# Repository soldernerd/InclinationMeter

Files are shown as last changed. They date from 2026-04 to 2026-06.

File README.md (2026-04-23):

# Inclination Meter

A battery-powered, Bluetooth-enabled precision electronic level instrument for machine tool geometry inspection and granite surface plate qualification.

## Overview

The instrument combines a MEMS 3-axis inclinometer (Murata SCL3300) with a high-resolution pendulum-based capacitive sensor (Sciosense PCAP04), a 2.7" Sharp Memory LCD display, and a Bluetooth Low Energy interface to a companion Windows application. All precision sensing is mechanically coupled directly to a cast iron reference base, isolated from the plastic enclosure.

## Hardware

| Parameter | Value |
|---|---|
| MCU | STM32G0B1RET6 (Cortex-M0+, 64 MHz, 512 KB flash) |
| Display | Sharp LS027B7DH01, 2.7", 400x240 monochrome |
| Connectivity | Bluetooth LE 5.0 (Microchip RN4871) |
| USB | USB-C Full Speed - charging + HID + DFU bootloader |
| Battery | 1S LiPo 1000 mAh, ~20 h runtime |
| Supply | 3.3 V main rail, 5 V display rail |
| MEMS range | +/-90 deg |
| Pendulum range | +/-1 mm/m |
| Pendulum resolution | ~0.001 um/m |

### Physical Architecture

Three PCBs:
- **Main board** - MCU, power management, display, BLE, user interface
- **SCL3300 daughter board** - 3-axis MEMS inclinometer, mounted to cast iron base
- **PCAP04 daughter boards x2** - capacitive pendulum readout, one per axis

## Repository Structure

```
KiCad/          KiCad 10 schematic and PCB files
docs/           KiCad file format and schematic reference notes
spec.md         Full hardware design specification
Netlist.md      Schematic netlist / connection list
```

## KiCad Library

All symbols and footprints use [sldrnrd_kicad_lib](https://github.com/soldernerd/sldrnrd_kicad_lib). Clone it as a sibling of this repository:

```
EmbeddedSystems/
├── InclinationMeter/   ← this repo
└── sldrnrd_kicad_lib/  ← library repo
```

## Firmware

Developed with STM32CubeIDE. Firmware update via USB DFU bootloader (no external programmer required after initial flash).

## Status

Hardware design in progress - schematic phase.

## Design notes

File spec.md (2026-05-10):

# Precision Electronic Level Instrument — Hardware Design Specification

**Document version:** 0.3  
**Status:** Draft  
**Date:** May 2026  
**Schematic reference:** KiCad commit 03fac10 (finalized)

---

## 1. System Overview

A battery-powered, Bluetooth-enabled precision electronic level instrument for machine tool geometry inspection and granite surface plate qualification. The system combines a MEMS 3-axis inclinometer with a high-resolution pendulum-based capacitive precision sensor, a wireless interface to a companion Windows desktop application, and a local display for standalone use.

### 1.1 Physical Architecture

The instrument consists of three PCBs:

| Board | Description | Mounting |
|---|---|---|
| Main PCB | Microcontroller, power, display, connectivity, user interface | 3D printed plastic enclosure |
| SCL3300 daughter board | 3-axis MEMS inclinometer | Cast iron precision base via brass standoffs |
| PCAP04 daughter board ×2 | Capacitive pendulum readout (one per axis) | Cast iron precision base via brass standoffs |

The cast iron base (~150×40mm) provides the precision reference surface. The plastic enclosure mounts on top. All precision sensing is mechanically coupled directly to the cast iron, isolated from the plastic enclosure.

### 1.2 Key Specifications

| Parameter | Value |
|---|---|
| Measurement range (MEMS) | ±90° |
| Measurement range (pendulum) | ±1 mm/m |
| Pendulum resolution | ~0.001 µm/m (electronics limited) |
| Pendulum precision (workshop) | ~0.1 µm/m |
| Display | 2.7" Sharp Memory LCD, 400×240 monochrome |
| Connectivity | Bluetooth Low Energy (BLE 5.0) |
| USB | USB-C, Full Speed (charging + HID + MSD bootloader) |
| Battery | 1S LiPo, 1000 mAh |
| Battery life | ~20 hours at 30 mA average |
| Supply voltage | 3.3V (main rail), 3.3V (sensor rail), 5V (buzzer only) |

---

## 2. Power Supply

### 2.1 Architecture

```
1S LiPo 1000mAh (JST-PH 2.0mm)
    │
    ├── Reverse polarity protection (Q1 DMG2305UX P-MOSFET)
    │
    ├── U1 TP4056 (USB-C charging, CC/CV, 500mA charge current)
    │       └── Q2 FS8205A (cell protection FET)
    │
    ├── U2 LP5907MFX-3.3 LDO → 3V3 rail (MCU, RN4871, display logic, EEPROM, buzzer buffer)
    │       └── Enable pin controlled by STM32 PB9 (3V3_EN, active-high)
    │
    ├── U4 LP5907MFX-3.3 LDO → 3V3_Sensors rail (SCL3300, PCAP04 #1, PCAP04 #2)
    │       └── Enable controlled by LDO_EN (power-sheet sequencing logic)
    │
    └── U5 SD6210A boost converter → 5V0 rail (buzzer BZ1 only, via U8 74AHCT244)
            └── Enable controlled by STM32 PB8 (5V_EN, active-high)
```

### 2.2 Component Details

| Ref | Function | Part | Package | JLCPCB # | Notes |
|---|---|---|---|---|---|
| J2 | USB-C + battery charge input | USB-C receptacle | SMD | C165948 | CC1/CC2: 5.1 kΩ to GND |
| Q1 | Reverse polarity | DMG2305UX | SOT-23 | C144153 | P-channel MOSFET |
| U1 | LiPo charger | TP4056 | SOP-8 | C382139 | RPROG = 2 kΩ (R3 ‖ R5) → ~500 mA |
| Q2 | Cell protection FET | FS8205A | TSSOP-8 | C14212 | Dual N-channel |
| U2 | 3V3 LDO — main rail | LP5907MFX-3.3/NOPB | SOT-23-5 | C80670 | 250 mA; EN = PB9 |
| U4 | 3V3_Sensors LDO — sensor rail | LP5907MFX-3.3/NOPB | SOT-23-5 | C80670 | 250 mA; EN = LDO_EN (power-sheet logic) |
| U5 | 5 V boost converter | SD6210A | SOT-23-6 | C250809 | 2.8–5 V in, 5 V/250 mA out; EN = PB8 |
| Q3 | Charging control | AO3400A | SOT-23 | C20917 | N-ch MOSFET; controls TP4056 charge enable path |
| Q4 | Sense-divider isolation | AO3400A | SOT-23 | C20917 | N-ch MOSFET; disconnects BATTERY_SENSE divider lower leg in off-state to prevent battery drain |
| D1–D4 | Schottky diodes | BAT54WS | SOD-323 | — | Present in schematic; verify placement in power sheet |

### 2.3 Battery Cutoff

- Hardware cutoff: DW01A at ~3.0V (cell protection absolute minimum)
- Software cutoff: STM32 ADC monitors Vbat via resistor divider, disables LDO enable pin at 3.6V
- Usable capacity at 3.6V cutoff: ~70% of rated capacity (~700mAh)
- Runtime at 30mA average: ~23 hours

### 2.4 Vbat Measurement

Resistor divider on BAT+ → BATTERY_SENSE → PB14 (ADC_IN):

- R9 = 100 kΩ (high side, BAT+ to divider node)
- R6 = 33 kΩ (low side, divider node to Q4 drain → GND)
- Q4 (AO3400A, N-ch) in the lower leg disconnects the divider during off-state to prevent battery drain
- Scale factor: 33/(100+33) = 0.248 → 4.2 V × 0.248 = 1.04 V max ADC input (within 3.3 V ADC range)
- Software ADC reference: VREF+ = 3.3 V

### 2.5 USB-C Connector

USB-C with CC1/CC2 pulled to GND via 5.1kΩ resistors for 5V/500mA negotiation. USB data lines connect to STM32 USB peripheral.

### 2.6 Decoupling

Every power pin of every IC must have a 100nF ceramic capacitor placed as close as possible to the pin. Additional bulk capacitors (10µF) at LDO output and charge pump output.

---

## 3. Microcontroller

### 3.1 Device

**STM32G0B1RET6**
- Package: LQFP64-GP (10×10 mm, 0.5 mm pitch — same body as PIC32MX470 64-TQFP)
- Core: ARM Cortex-M0+, 64 MHz
- Flash: 512 KB
- RAM: 144 KB (without parity)
- Supply: 1.7–3.6V
- JLCPCB: C2829307

### 3.2 Clock

- Main crystal: 8 MHz, ±20 ppm, SMD 5032 package (Yangxing X50328MSB2GI, JLCPCB C115962)
- Main crystal load caps: 33 pF NP0 (0603). Crystal CL = 20 pF, C_stray ≈ 3 pF → C_load = 2×(20−3) = 34 pF → 33 pF (nearest E12)
- Main crystal pins: PF0-OSC_IN (pin 10), PF1-OSC_OUT (pin 11)
- PLL configuration: HSE 8 MHz → SYSCLK = 64 MHz
- USB clock: HSI48 internal RC + CRS locked to USB SOF packets → 48 MHz (no crystal required for USB)
- **RTC crystal (Y1):** 32.768 kHz, standard RTC crystal, on PC14 (OSC32_IN, pin 4) and PC15 (OSC32_OUT, pin 5)
  > **Note:** PC14/PC15 are also used for PCAP04 #2 SCL/SDA and the ~{RST} signal respectively. See open items.

### 3.3 Debug / Programming Interface

**J4 — 2×7, 50 mil (1.27 mm) pitch SMD header**, compatible with STLINK-V3MINIE.

| J4 Position | Signal | Net | Notes |
|---|---|---|---|
| 1 | VCC | 3V3 | Target voltage sense for STLINK |
| 2 | SWDIO | SWDIO | SWD data — see note below |
| 3 | GND | GND | |
| 4 | SWCLK | SWCLK | SWD clock — see note below |
| 5 | GND | GND | |
| 6 | SWO | SWO | Cortex-M0+ has no ITM; SWO not functional |
| 7 | NC | — | |
| 8 | ~{RST} | ~{RST} | Reset signal → PC15 |
| 9 | GND | GND | |
| 10 | DEBUG_UART_MCU_TO_PC | — | PD9 (UART TX from MCU) |
| 11 | DEBUG_UART_PC_TO_MCU | — | PD8 (UART RX to MCU) |
| 12–14 | GND / NC | — | |

> **SWD pin note:** Standard SWD pins on STM32G0B1 are PA13 (SWDIO) and PA14 (SWCLK). In this design, PA13/PA14 are used for PCAP04 #1 P3/P2 GPIO. The `SWDIO` and `SWCLK` nets on J4 appear connected to PA8/PB15 in the schematic. This is a known conflict requiring clarification: either PA13/PA14 must be routed to J4 for SWD to function, or SWD and PCAP04_1 P2/P3 cannot be used simultaneously. See Netlist.md open items.

### 3.4 Reset

NRST (pin 12) has a decoupling capacitor to GND. The `~{RST}` signal from J4 routes to PC15 — see Netlist.md open item 2.

### 3.5 BOOT0 / DFU Bootloader

PA14 doubles as BOOT0 on STM32G0B1. A pull-down resistor holds BOOT0 LOW for normal boot. To activate the ROM DFU bootloader, pull BOOT0 HIGH before reset — the device enumerates as a USB DFU device. No SPI flash required.

---

## 4. Peripheral Pin Allocation

### 4.1 Summary Table

All assignments verified from KiCad/mcu.kicad_sch global label coordinates. See Netlist.md §5 for full analysis and footnotes.

| Function | Signal | Direction | STM32 Pin (phys.) | Net name |
|---|---|---|---|---|
| **Power control** | | | | |
| 3.3 V main LDO enable | 3V3_EN | Out | PB9 (63) | 3V3_EN |
| 5 V boost enable | 5V_EN | Out | PB8 (62) | 5V_EN |
| Charge enable (active-low) | ~{CHARGE_EN} | Out | PB7 (61) | ~{CHARGE_EN} |
| Battery voltage sense | BATTERY_SENSE | ADC in | PB14 (34) | BATTERY_SENSE |
| Charge status sense | CHARGE_SENSE | In | PC4 (25) | CHARGE_SENSE |
| Standby sense | STANDBY_SENSE | In | PC5 (26) | STANDBY_SENSE |
| USB VBUS sense | VBUS_SENSE | In | PC7 (39) | VBUS_SENSE |
| **SPI — SCL3300 inclinometer** | | | | |
| SCK | SCL3300_SCK | SPI out | PB5 (59) | SCL3300_SCK |
| MOSI | SCL3300_MOSI | SPI out | PB3 (57) | SCL3300_MOSI |
| MISO | SCL3300_MISO | SPI in | PB4 (58) | SCL3300_MISO |
| CS (active-low) | SCL3300_CS | Out | PB6 (60) | SCL3300_CS |
| **I2C — PCAP04 #1** | | | | |
| SCL | PCAP04_1_SCL | I2C out | PC8 (48) | PCAP04_1_SCL |
| SDA | PCAP04_1_SDA | I2C bidir | PA15 (47) | PCAP04_1_SDA |
| Interrupt | PCAP04_1_INT | In | PA12 (44) | PCAP04_1_INT |
| GPIO P2 (optional) | PCAP04_1_P2 | Bidir | PA14 (46) | PCAP04_1_P2 |
| GPIO P3 (optional) | PCAP04_1_P3 | Bidir | PA13 (45) | PCAP04_1_P3 |
| **I2C — PCAP04 #2** | | | | |
| SCL | PCAP04_2_SCL | I2C out | PC14 (4) | PCAP04_2_SCL |
| SDA | PCAP04_2_SDA | I2C bidir | PC13 (3) | PCAP04_2_SDA |
| Interrupt | PCAP04_2_INT | In | PC10 (64) | PCAP04_2_INT |
| GPIO P2 (optional) | PCAP04_2_P2 | Bidir | PC11 (1) | PCAP04_2_P2 |
| GPIO P3 (optional) | PCAP04_2_P3 | Bidir | PC12 (2) | PCAP04_2_P3 |
| **I2C — EEPROM (U10)** | | | | |
| SCL | EEPROM_SCL | I2C out | PA4 (21) | EEPROM_SCL |
| SDA | EEPROM_SDA | I2C bidir | PA3 (20) | EEPROM_SDA |
| **SPI — Display (LS027B7DH01)** | | | | |
| SCK | DISP_SCK | SPI out | PB10 (30) | DISP_SCK |
| MOSI (SI) | DISP_MOSI | SPI out | PB0 (27) | DISP_MOSI |
| CS (SCS, active-high) | DISP_CS | Out | PB11 (31) | DISP_CS |
| VCOM toggle | DISP_VCOM | Out | PB1 (28) | DISP_VCOM |
| Display on/off | DISP_ON | Out | PB2 (29) | DISP_ON |
| **USART2 — RN4871 BLE** | | | | |
| TX (MCU→BLE) | BLE_UART_MCU_TO_BLE | Out | PD6 (56) | BLE_UART_MCU_TO_BLE |
| RX (BLE→MCU) | BLE_UART_BLE_TO_MCU | In | PD5 (55) | BLE_UART_BLE_TO_MCU |
| Reset (active-low) | ~{BLE_RST} | Out | PD4 (54) | ~{BLE_RST} |
| GPIO P0_2 (optional) | BLE_P0_2 | Bidir | PD2 (52) | BLE_P0_2 |
| GPIO P1_6 (optional) | BLE_P1_6 | Bidir | PD3 (53) | BLE_P1_6 |
| GPIO P1_7 (optional) | BLE_P1_7 | Bidir | PD0 (50) | BLE_P1_7 |
| GPIO P2_0 (optional) | BLE_P2_0 | Bidir | PC9 (49) | BLE_P2_0 |
| GPIO P3_6 (optional) | BLE_P3_6 | Bidir | PD1 (51) | BLE_P3_6 |
| **Debug UART (J4)** | | | | |
| TX (MCU→PC) | DEBUG_UART_MCU_TO_PC | Out | PD9 (41) | DEBUG_UART_MCU_TO_PC |
| RX (PC→MCU) | DEBUG_UART_PC_TO_MCU | In | PD8 (40) | DEBUG_UART_PC_TO_MCU |
| **USB FS** | | | | |
| D+ | USB_D+ | Bidir | PA9 (37) | USB_D+ |
| D− | USB_D- | Bidir | PC6 (38) | USB_D- |
| **Rotary encoder 1** | | | | |
| Channel A | ENC_1A | In | PA1 (18) | ENC_1A |
| Channel B | ENC_1B | In | PA2 (19) | ENC_1B |
| Push-button (active-low) | ~{ENC_1SW} | In | PA0 (17) | ~{ENC_1SW} |
| **Rotary encoder 2** | | | | |
| Channel A | ENC_2A | In | PC2 (15) | ENC_2A |
| Channel B | ENC_2B | In | PC3 (16) | ENC_2B |
| Push-button | ENC_2SW | In | PC1 (14) | ENC_2SW |
| **Temperature sensor** | | | | |
| Analog output | TEMP_SENSE | ADC in | PB13 (33) | TEMP_SENSE |
| **Buzzer** | | | | |
| Drive signal (3.3 V logic) | BUZZER | PWM out | PB12 (32) | BUZZER |
| **Status LEDs** | | | | |
| Power LED | LED_PWR | Out | PA6 (23) | LED_PWR |
| Status LED | LED_STATUS | Out | PA5 (22) | LED_STATUS |
| **SWD / debug** | | | | |
| SWO | SWO | Out | PA7 (24) | SWO |
| SWDIO | SWDIO | Bidir | PA8 (36)* | SWDIO |
| SWCLK | SWCLK | In | PB15 (35)* | SWCLK |
| Reset sense | ~{RST} | In | PC15 (5)* | ~{RST} |
| **Misc** | | | | |
| External reset (NRST) | — | — | pin 12 | hardware only |

*See §3.3 note regarding SWD pin conflict with PCAP04 and ~{RST} on PC15.

### 4.2 Peripheral Allocation

| Peripheral | Assignment | Pins |
|---|---|---|
| SPI (TBD) | SCL3300 inclinometer | PB3/PB4/PB5/PB6 |
| SPI (TBD) | Display LS027B7DH01 | PB0/PB10/PB11 (bit-bang or AF, verify) |
| I2C (TBD) | PCAP04 #1 | PC8/PA15 |
| I2C (TBD) | PCAP04 #2 | PC14/PC13 |
| I2C (TBD) | EEPROM (U10) | PA4/PA3 — dedicated bus |
| USART2 | RN4871 BLE module, 115200 baud | PD5/PD6 |
| USART (TBD) | Debug UART to J4 | PD8/PD9 |
| USB FS | USB-C (charging + HID + DFU); HSI48 + CRS | PA9/PC6 |
| ADC | BATTERY_SENSE, TEMP_SENSE | PB14, PB13 |
| Timer (PWM) | BUZZER (3.3 V drive to U8) | PB12 |
| Timer (PWM) | DISP_VCOM toggle (≥ 1 Hz) | PB1 |

> All SPI and I2C peripheral assignments require verification against the STM32G0B1RET6 alternate function table.  
> PCAP04 P2/P3 GPIO lines and RN4871 GPIO lines will be assigned to specific functions during firmware development.

---

## 5. Display

### 5.1 Device

**Sharp LS027B7DH01**
- Size: 2.7", 400×240 pixels, monochrome
- Technology: Memory-in-Pixel reflective LCD (no backlight)
- Interface: SPI write-only
- Supply: VDD = VDDA = 5V
- Logic inputs: 3V compatible (level shifted from 3.3V)
- FPC connector: 10-pin, 0.5mm pitch, integral tail

### 5.2 Power

- VDD and VDDA both connected to 5V rail from SD6210A
- VDD must rise before or simultaneously with VDDA
- 1µF ceramic decoupling on both VDD and VDDA

### 5.3 Signal Connections

| Display Pin | Signal | Connection |
|---|---|---|
| SCLK | SPI clock | 74AHCT244 output → SPI1 SCK |
| SI | SPI data in | 74AHCT244 output → SPI1 MOSI |
| SCS | Chip select | 74AHCT244 output → GPIO (active HIGH) |
| EXTCOMIN | VCOM inversion | 74AHCT244 output → GPIO (timer ISR toggle) |
| EXTMODE | COM mode select | Tied to VDD (5V) — external VCOM mode |
| DISP | Display on/off | 74AHCT244 output → GPIO |
| VDD | Digital supply | 5V rail |
| VDDA | Analog supply | 5V rail |
| VSS | Digital GND | GND |
| VSSA | Analog GND | GND |

### 5.4 Logic Level Shifting

All 5 logic signals (SCLK, SI, SCS, EXTCOMIN, DISP) shifted from 3.3V to 5V via:

**SN74AHCT244DBR** (TI, SSOP-20, JLCPCB C2868870)
- 8-channel unidirectional buffer, 3.3V in, 5V out
- OE1, OE2 tied to GND (always enabled)
- 3 channels spare

### 5.5 PCB Connector

**10-pin, 0.5mm pitch ZIF FPC connector** (bottom contact, SMD)
- Hirose FH12-10S-0.5SH or equivalent
- Position within 30mm of display window in enclosure (limited by FPC tail length)

### 5.6 VCOM Timing

EXTMODE = HIGH selects external VCOM mode. STM32 TIM3_CH1 (PA6 AF1) or a timer ISR toggles DISP_VCOM at 30 Hz (33 ms period). This prevents DC bias buildup in the liquid crystal cells. VCOM must toggle continuously whenever the display is powered.

### 5.7 Framebuffer Note

Full 400×240 monochrome framebuffer = 12,000 bytes. STM32G0B1 has 144 KB RAM — full framebuffer fits comfortably. Render line-by-line for updates; transmit only changed lines to minimise SPI activity.

---

## 6. Bluetooth Low Energy

### 6.1 Device

**RN4871-I/RM128** (Microchip, castellated module)
- BLE 5.0
- UART ASCII command interface
- Pre-certified FCC/CE
- 3.3V supply
- JLCPCB: C633941

### 6.2 Interface

UART at 115200 baud, 8N1

| Signal | STM32 Pin (phys.) | Direction | Notes |
|---|---|---|---|
| UART TX (MCU→BLE) | PD6 (56), USART2_TX | STM32 → RN4871 | 3.3V logic |
| UART RX (BLE→MCU) | PD5 (55), USART2_RX | RN4871 → STM32 | 3.3V logic |
| ~{BLE_RST} | PD4 (54) | STM32 → RN4871 | Active low hardware reset |
| GPIO P0_2–P3_6 | PD2/PD3/PD0/PC9/PD1 | TBD | Optional; usage determined in firmware |

### 6.3 GATT Service

Custom BLE service with two characteristics:

| Characteristic | UUID | Properties | Description |
|---|---|---|---|
| Measurement notify | 128-bit custom | Notify | Device → PC: angle data |
| Command write | 128-bit custom | Write | PC → Device: trigger commands |

Custom 128-bit UUIDs to be defined during firmware development.

### 6.4 Antenna Keep-out

Keep-out zone around RN4871 antenna: no copper, no vias, no traces within the area specified in the module datasheet. Place module at PCB edge where possible.

---

## 7. 3-Axis Inclinometer (SCL3300 Daughter Board)

### 7.1 Device

**Murata SCL3300-D01**
- 3-axis MEMS inclinometer
- Digital SPI interface
- Supply: 3.0–3.6V
- Current: 1.2mA typical
- Measurement modes: 4 selectable (Mode 4 preferred: lowest noise, 10Hz ODR)
- Noise: 0.0009°/√Hz (Mode 4, X/Z axes)
- Factory calibrated, no external calibration required
- Package: 12-pin LCC (SMD, on daughter board)

### 7.2 Daughter Board

Separate small PCB (~30×25mm) with:
- SCL3300 + decoupling capacitors only
- 6-pin FFC connector (same physical standard as PCAP04 boards)
- Mounted to cast iron base via brass M3 standoffs, 4 corners

**Pinout of J3 (6-pin FFC, 1.0 mm pitch, main board side):**

| Pin | Signal | Description |
|---|---|---|
| 1 | 3V3_Sensors | 3.3 V supply (from U4 LDO) |
| 2 | SCL3300_CS | SPI chip select (active-low) |
| 3 | SCL3300_SCK | SPI clock |
| 4 | SCL3300_MISO | SPI data out (SCL3300 → MCU) |
| 5 | SCL3300_MOSI | SPI data in (MCU → SCL3300) |
| 6 | GND | Ground |

Connector: J3 (JUSHUO AFA07 or equivalent 6-pin 1.0 mm FFC ZIF).

### 7.3 Main Board Connection

J3 (SCL3300 FFC) is the only 6-pin FFC on the main board for sensor connections. J5 and J6 are 10-pin FFCs for PCAP04 #1 and #2 respectively.

**SPI timing:** Use SPI Mode 0, recommended clock 2–4 MHz per datasheet for best noise performance.

**Post-assembly calibration:** Perform system-level zero/offset calibration after final mechanical assembly with all standoffs torqued. Wait minimum 12 hours after reflow before calibrating.

---

## 8. Precision Capacitive Inclinometer (PCAP04 Boards)

### 8.1 Device

**Sciosense PCAP04-AQFM-24**
- Capacitance-to-digital converter with integrated DSP
- Input range: 1pF–100nF
- Resolution: up to 8aF at 2.5Hz
- Interface: I2C or SPI (I2C selected)
- Supply: 2.1–3.6V (3.3V nominal)
- Package: QFN-24, 4×4mm

### 8.2 I2C Configuration

Each PCAP04 board has a dedicated I2C bus. I2C (not SPI) is used in this design.

**PCAP04 #1 (J5) — SCL=PC8, SDA=PA15:**
- PCAP04 #1 I2C address: verify from PCAP04 datasheet (address depends on ADDR pin)
- Pull-ups on SCL/SDA to 3V3_Sensors on the daughter board

**PCAP04 #2 (J6) — SCL=PC14, SDA=PC13:**
- PCAP04 #2 I2C address: verify from PCAP04 datasheet
- Pull-ups on SCL/SDA to 3V3_Sensors on the daughter board

**EEPROM (U10) — SCL=PA4, SDA=PA3 (separate dedicated I2C bus)**

> EEPROM is on its own I2C bus, separate from both PCAP04 buses.

### 8.3 PCAP04 Daughter Boards (v2)

The PCAP04 v2 daughter boards are used. They expose both I2C and SPI interfaces but **only I2C is used**. Connector: 10-pin FFC.

**Pinout of J5 / J6 (10-pin FFC, main board side):**

| Pin | Signal | Description |
|---|---|---|
| 1 | 3V3_Sensors | 3.3 V supply |
| 2 | PCAP04_x_SCL | I2C clock |
| 3 | PCAP04_x_SDA | I2C data |
| 4–7 | GND / NC | Ground / no-connect |
| 8 | PCAP04_x_P3 | GPIO P3 (optional, usage TBD) |
| 9 | PCAP04_x_P2 | GPIO P2 (optional, usage TBD) |
| 10 | PCAP04_x_INT | Interrupt output (active-low) |

> **Compatibility note:** These 10-pin FFC connectors are **not compatible** with the old 6-pin FFC prototype boards.  
> New v2 daughter boards are required for use with this main board.

### 8.4 Mechanical Design (Pendulum Sensor)

The PCAP04 measures differential capacitance between two plates (~20mm diameter, 0.1mm gap) flanking a brass pendulum bob suspended from a thin metal foil pivot. Eddy current braking (permanent magnet near brass bob) provides damping. Pendulum length ~40mm to centre of gravity.

**Performance summary:**

| Parameter | Value |
|---|---|
| Capacitance per plate | ~28 pF |
| Sensitivity | ~53 fF/arcsecond |
| Resolution (8aF noise) | ~0.001 µm/m |
| Measurement range | ±1 mm/m |
| Natural frequency | ~2.5 Hz |

---

## 9. Firmware Update (DFU)

The W25Q80DV SPI flash has been removed. Firmware updates are handled by the STM32G0B1 built-in ROM DFU bootloader:

- No external flash required
- DFU activated by pulling BOOT0 (PA14/pin 46) HIGH during reset
- STM32 enumerates as USB DFU device (class 0xFE, subclass 0x01)
- Firmware downloaded via `dfu-util` or STM32CubeProgrammer over the existing USB-C port
- After programming, normal reset (BOOT0 LOW) boots from internal flash

The SPI2 bus is now dedicated to the SCL3300 sensor only (one device, one CS line).

---

## 10. EEPROM

### 10.1 Device

**Microchip 24LC256-I/ST**
- 256Kbit (32KB) EEPROM
- I2C interface
- 3.3V supply
- TSSOP-8 package
- JLCPCB: C87823

### 10.2 Purpose

Non-volatile storage for calibration coefficients, zero offsets, instrument configuration, and measurement history.

### 10.3 Connections

| EEPROM Pin | Connection | Notes |
|---|---|---|
| A0 | GND | I2C address bit 0 = 0 |
| A1 | GND | I2C address bit 1 = 0 |
| A2 | GND | I2C address bit 2 = 0 → address 0x50 |
| VSS | GND | |
| SDA | I2C SDA | Shared bus |
| SCL | I2C SCL | Shared bus |
| WP | GND | Write always enabled |
| VCC | 3.3V | 100nF decoupling |

---

## 11. Temperature Sensor

### 11.1 Device

**Texas Instruments LM35**
- Linear temperature sensor, 10mV/°C
- No calibration required
- Supply: 3.3V
- SOT-23 package
- JLCPCB: C9900081740

### 11.2 Purpose

Ambient temperature measurement for pendulum thermal drift compensation and data logging.

### 11.3 Placement

Mount on main PCB, away from heat sources (LP5907 LDO, TP4056, SD6210A charge pump). Placement near centre of board, not near USB-C connector or power section.

### 11.4 Connection

Output pin → STM32 PB1 (pin 28, ADC_IN9) via 100 Ω series resistor and 10 nF cap to GND (low-pass filter).

---

## 12. Buzzer

### 12.1 Device

**Same Sky (CUI) CPT-9019A-SMT-TR**
- SMD passive piezo transducer
- Resonant frequency: 4000 Hz
- Rated voltage: 3 Vp-p
- Capacitance: 12 nF (capacitive load — no driver transistor required)
- SPL: 75 dB typical / 72 dB minimum at 10 cm at 3 Vp-p
- Package: 9×9×1.9 mm SMD
- Operating temperature: −20 to +70 °C
- JLCPCB: C20181991

### 12.2 Drive

BZ1 is driven at **5 V** via the 74AHCT244 buffer (U8):

1. MCU PB12 (pin 32) outputs 3.3 V PWM signal (`BUZZER` net)
2. U8 (74AHCT244) level-shifts 3.3 V → 5 V (`BUZZER_5V` net)
3. 5 V signal drives BZ1

PWM frequency: buzzer resonant frequency (typically ~4 kHz). Duty cycle 50% for continuous tone. Shorter bursts for click feedback.

### 12.3 Connections

| Buzzer Pin | Net | Notes |
|---|---|---|
| + (signal) | BUZZER_5V | U8 (74AHCT244) output, 5 V |
| − (GND) | GND | |

### 12.4 Usage

| Event | Pattern |
|---|---|
| Encoder turn | Single short beep (e.g. 20 ms) |
| Button press | Double short beep (e.g. 2 × 10 ms) |
| Battery low warning | Slow repeating beep (firmware defined) |
| Error / invalid action | Long beep (firmware defined) |

---

## 13. User Interface

### 12.1 Rotary Encoders

Two mechanical rotary encoders with integral push-button switches.

**Debouncing:** RC filters only (no Schmitt trigger inverter). All 6 signals connect to STM32 GPIO pins with internal pull-ups. Additional software debounce (≥ 5 ms) required in firmware.

RC filter values (from schematic):
- Encoder A/B signals (4 lines): 33 kΩ + 10 nF (τ = 330 µs)
- Encoder switch signals (2 lines): 68 kΩ + 100 nF (τ = 6.8 ms)

**Encoder part:** Bourns PEC11R-4215F-S0024. JLCPCB: C143790. Incremental, 24 detents/rev, integrated push-button switch, 15 mm shaft, SMD.

**Encoder assignments:**
- Encoder 1: Navigation / value adjustment
- Encoder 2: Mode selection / confirmation

**Push buttons:** Short press = select/confirm, long press = back/cancel (defined in firmware).

### 12.2 Status LEDs

| LED | Colour | Function | Series resistor |
|---|---|---|---|
| LED_PWR | Green | Power on indicator | 330Ω |
| LED_STS | Blue | BLE connected / activity | 330Ω |

Both LEDs: 0603 SMD, active high from STM32 GPIO.

---

## 14. USB

### 13.1 Connector

USB-C receptacle, SMD, with CC1/CC2 pull-down resistors:
- CC1: 5.1kΩ to GND
- CC2: 5.1kΩ to GND
- Purpose: signals USB-C host to supply 5V/500mA (USB default power)

### 13.2 USB Interface

Implemented directly by STM32G0B1 internal USB peripheral (Full Speed, 12 Mbps).

**USB clock:** HSI48 internal 48 MHz RC oscillator locked to USB SOF via CRS (Clock Recovery System). No crystal required for USB operation.

**USB pin assignment:** D+ = PA9 (pin 37), D− = PC6 (pin 38). These are alternate USB pin positions on STM32G0B1 — verify AF table support before implementing USB driver.

**VBUS detection:** PC7 (pin 39) senses VBUS for cable presence detection.

### 13.3 USB Device Classes

| Class | Purpose |
|---|---|
| HID | Communication with Windows companion application |
| DFU | Firmware update via STM32 ROM DFU bootloader (USB DFU class) |
| CDC (optional) | Development/debug virtual COM port |

**DFU bootloader flow:** Pull BOOT0 (PA14) HIGH before reset → STM32 ROM DFU activates → host programs firmware via `dfu-util` or STM32CubeProgrammer → normal reset boots updated firmware. No SPI flash or external memory required.

---

## 15. Connectors and Headers

### 14.1 Connector Summary

| Ref | Type | Pins | Pitch | Purpose |
|---|---|---|---|---|
| J2 | USB-C receptacle | — | — | Charging + USB data |
| J3 | ZIF FFC | 6 | 1.0 mm | SCL3300 inclinometer daughter board |
| J4 | 2×7 50 mil SMD header | 14 | 1.27 mm | STLINK-V3MINIE SWD debug + debug UART |
| J5 | ZIF FFC | 10 | TBD | PCAP04 #1 daughter board (v2) |
| J6 | ZIF FFC | 10 | TBD | PCAP04 #2 daughter board (v2) |

The display (DS1, LS027B7DH01) FPC is integrated into the DS1 footprint — there is no separate FPC connector designator on the main board.

> J5 and J6 (10-pin FFC) are not compatible with earlier 6-pin FFC PCAP04 daughter boards. V2 daughter boards required.

### 14.2 Expansion Header (J8)

7-pin 100mil (2.54mm) through-hole header. **DNP (do not populate)** — footprint reserved for future hardware extensions. Place at board edge.

| Pin | Signal | Net | Notes |
|---|---|---|---|
| 1 | GND | GND | |
| 2 | +3.3V | +3V3 | |
| 3 | +5V | +5V | |
| 4 | EXP1 | EXP1 | Spare GPIO from STM32 (assign from 18 spare pins) |
| 5 | EXP2 | EXP2 | Spare GPIO from STM32 |
| 6 | EXP3 | EXP3 | Spare GPIO from STM32 |
| 7 | EXP4 | EXP4 | Spare GPIO from STM32 |

Specific spare pins to assign at PCB layout stage. Candidates: PD1–PD6 (pins 51–56), PB4/PB5 (pins 58/59).

### 14.3 FFC Cable Note

All three 6-pin FFC connectors on the main board are identical physical parts. The signal assignments at the daughter board end differ between SCL3300 and PCAP04 boards. Cable length should be sufficient to allow mechanical compliance between cast iron base and plastic enclosure — recommend 100–150mm.

---

## 16. Complete Bill of Materials

| Ref | Description | Part Number | Package | JLCPCB # | Qty |
|---|---|---|---|---|---|
| U6 | MCU STM32G0B1RET6 | STM32G0B1RET6 | LQFP64-GP | C2829307 | 1 |
| U7 | BLE module RN4871 | RN4871-I/RM128 | Castellated | C633941 | 1 |
| U1 | LiPo charger | TP4056 | SOP-8 | C382139 | 1 |
| U2 | 3.3 V LDO — main rail (3V3) | LP5907MFX-3.3/NOPB | SOT-23-5 | C80670 | 1 |
| U4 | 3.3 V LDO — sensor rail (3V3_Sensors) | LP5907MFX-3.3/NOPB | SOT-23-5 | C80670 | 1 |
| U5 | 5 V boost converter | SD6210A | SOT-23-6 | C250809 | 1 |
| U8 | Octal buffer 3.3V→5V (buzzer drive) | 74AHCT244 | SSOP-20 | C2868870 | 1 |
| U10 | EEPROM 32 KB | 24LC256-I/ST | TSSOP-8 | C87823 | 1 |
| Q1 | Reverse polarity P-ch MOSFET | DMG2305UX | SOT-23 | C144153 | 1 |
| Q2 | Cell protection FET | FS8205A | TSSOP-8 | C14212 | 1 |
| Q3 | Charge control N-ch MOSFET | AO3400A | SOT-23 | C20917 | 1 |
| Q4 | Sense-divider isolation N-ch MOSFET | AO3400A | SOT-23 | C20917 | 1 |
| D1–D4 | Schottky diode | BAT54WS | SOD-323 | — | 4 |
| Y1 (main) | Crystal 8 MHz | X50328MSB2GI | SMD-5032 | C115962 | 1 |
| Y1 (RTC) | Crystal 32.768 kHz | (TBD) | SMD | — | 1 |
| J2 | USB-C connector | TYPE-C-31-M-12 | SMD right-angle | C165948 | 1 |
| J3 | FFC ZIF 6-pin (SCL3300) | JUSHUO AFA07 | SMD ZIF 1.0 mm | — | 1 |
| J4 | Debug header 2×7 50 mil | (TBD) | SMD | — | 1 |
| J5, J6 | FFC ZIF 10-pin (PCAP04 ×2) | (TBD) | SMD ZIF | — | 2 |
| SW1, SW2 | Rotary encoder with switch | Bourns PEC11R-4215F-S0024 | SMD | C143790 | 2 |
| DS1 | Sharp Memory LCD 2.7" | LS027B7DH01 | FPC | C17492463 | 1 |
| BZ1 | Passive piezo transducer | CPT-9019A-SMT-TR | SMD 9×9 mm | C20181991 | 1 |
| — | Resistors 0603 | Various | 0603 | — | ~30 |
| — | Capacitors | 100 nF, 1 µF (0603); 4.7 µF, 10 µF (0805/1206) | — | — | ~40 |

> Components removed vs previous spec: DW01A (cell protection IC replaced by FS8205A alone), SN74HC14PWR Schmitt trigger (no longer used), SPI flash W25Q80DV (replaced by ROM DFU bootloader).

---

## 17. PCB Design Guidelines

### 16.1 Stack-up

4-layer PCB recommended:
- Layer 1: Signal + components (top)
- Layer 2: Ground plane (solid)
- Layer 3: Power planes (3.3V, 5V)
- Layer 4: Signal (bottom)

2-layer is acceptable for prototype if careful attention is paid to ground return paths.

### 16.2 Layout Priorities

1. Crystal and load capacitors as close to OSC1/OSC2 as possible, keep traces short, no other signals nearby
2. USB D+/D- routed as differential pair, matched length, 90Ω differential impedance, no vias
3. RN4871 at board edge, antenna keep-out observed, no copper under antenna area
4. Power section (TP4056, DW01A, LDO, charge pump) grouped together away from sensitive signals
5. 74AHCT244 between STM32 and display connector, short trace path
6. 10-pin display ZIF connector positioned within 30mm of display window location
7. Three 6-pin FFC connectors grouped at one edge of board for cable routing to cast iron base
8. U5B (3.3V_DBOARD LDO) placed close to the three FFC connectors with short traces to the 3.3V_DBOARD power pour; minimises resistive drop on the daughter board supply
9. LM35 away from heat sources, near centre of board

### 16.3 Decoupling Strategy

- 100 nF 0603 ceramic at every power pin, placed within 1 mm of pin
- 4.7 µF at STM32 VDD/VDDA (pin 8) as primary bulk cap; additional 100 nF directly at pin
- 1 µF + 10 nF at STM32 VREF+ (pin 7)
- 100 nF at STM32 VBAT (pin 6)
- 4.7 µF 0805 at STM32 VDD bulk; 10 µF 0805/1206 at LDO output and charge pump output
- 1 µF ceramic at display VDD and VDDA
- Keep decoupling capacitor ground via as short as possible — direct to ground plane
- **No VCAP capacitor needed** — STM32G0 has fully integrated core regulator (no external filter cap)

### 16.4 Ground

Single ground plane on layer 2. Star topology from main ground point near power section. No ground splits. Analogue and digital signals share the same ground plane — this is acceptable for this design given the SCL3300 and PCAP04 are fully digital devices. The only analogue signals are Vbat sense and LM35 output, both low frequency.

---

## 18. Mechanical

### 17.1 PCB Dimensions

To be defined. Target: fits within 150×35mm footprint of plastic enclosure with display centred on top face.

### 17.2 Enclosure

3D printed (PETG or ASA). Brass heat-set inserts for all screw attachment points. Display window with minimal bezel. Encoder knobs accessible from top/front panel. USB-C and ICSP header accessible from end panel. LED indicators visible from top.

### 17.3 Precision Base

Cast iron, approximately 150×40×20mm. Precision lapped bottom surface. Tapped holes for brass standoffs supporting sensor PCBs. Material: grey cast iron for vibration damping and thermal stability.

### 17.4 Sensor PCB Mounting

SCL3300 and PCAP04 PCBs mount directly to cast iron via 4× M3 brass standoffs each. All standoffs torqued to consistent value. PCBs must be flat — any bow introduces sensor offset. Perform zero calibration after final assembly with all hardware at operating temperature.

---

## 19. Firmware Architecture (Outline)

### 18.1 Boot Sequence

1. Check BOOT0 (PA14, shared with PCAP04_1_P2) state: if HIGH → STM32 ROM DFU bootloader handles firmware update, enumerates USB DFU
2. Normal boot (BOOT0 LOW): STM32 jumps to user application at `0x08000000`
3. Firmware initialises all peripherals, starts main loop

### 18.2 Main Tasks

| Task | Rate | Notes |
|---|---|---|
| SCL3300 read | 10 Hz | SPI, Mode 0, PB3–PB6 |
| PCAP04 read | 2–10 Hz | I2C; #1 on PC8/PA15, #2 on PC14/PC13 |
| Sensor fusion | 10 Hz | Complementary filter: pendulum < 0.5 Hz, MEMS > 0.5 Hz |
| BLE notify | On measurement | USART2 to RN4871 (PD5/PD6) |
| Display update | 10 Hz | Redraw changed lines only |
| VCOM toggle | ≥ 1 Hz | PB1 PWM — must run whenever display is powered |
| Vbat ADC | 1 Hz | PB14 ADC; software cutoff at 3.6 V |
| Temperature ADC | 0.1 Hz | PB13 ADC |
| USB service | As needed | HID + DFU; PA9/PC6 |
| Encoder service | GPIO interrupt | RC-filtered inputs; software debounce ≥ 5 ms |

### 18.3 BLE Protocol

Custom GATT service. Measurement notification packet format (to be defined):
- X-axis angle (pendulum, µm/m, 32-bit float)
- Y-axis angle (SCL3300, µm/m, 32-bit float)
- Z-axis angle (SCL3300, µm/m, 32-bit float)
- Temperature (°C, 16-bit fixed point)
- Status flags (battery, BLE, sensor health)
- Timestamp (ms since power-on)

---

## 20. Open Items

| Item | Description | Priority |
|---|---|---|
| **SWD vs PCAP04_1 pin conflict** | PA13/PA14 used for PCAP04_1_P3/P2 AND are the hardware SWD pins. Schematic shows SWDIO/SWCLK at PA8/PB15 — verify if this is intentional routing or an error. Clarify with designer before firmware implementation. | **High** |
| **~{RST} on PC15 / RTC crystal** | PC15 carries ~{RST} from J4. PC14/PC15 are also OSC32_IN/OUT for RTC crystal Y1. Clarify: is Y1 fitted? If yes, PCAP04_2 SCL/SDA (PC14/PC13) and ~{RST} (PC15) conflict. Decision: use LSI for RTC or do not populate Y1. | **High** |
| **USB alternate pin mapping** | USB D+=PA9, D−=PC6 (non-standard). Verify STM32G0B1 AF table supports USB FS on these pins before USB driver development. | **High** |
| **PCAP04 I2C addresses** | Verify I2C addresses for PCAP04 #1 and #2 from PCAP04 datasheet (ADDR pin configuration). | Medium |
| **10-pin FFC connector parts** | Select specific parts for J5 and J6 (10-pin FFC ZIF). Confirm pitch (0.5 mm or 1.0 mm) matches v2 PCAP04 daughter boards. | Medium |
| **J4 debug header part** | Confirm 50-mil 2×7 SMD header part number for J4. | Medium |
| **RTC crystal Y1** | Select 32.768 kHz crystal if RTC crystal is to be used. Confirm PC14/PC15 are not conflicting. | Medium |
| **EEPROM I2C address** | Confirm address pin wiring (A0/A1/A2) for U10 in schematic. Default 0x50 assumed. | Low |
| **Display SPI peripheral** | PB0 (MOSI) and PB10/PB11 (SCK/CS) — verify compatible STM32G0B1 AF or use bit-banged SPI. | Medium |
| **VCOM timer** | Confirm timer and pin AF for DISP_VCOM (PB1) PWM. Must toggle ≥ 1 Hz continuously when display is on. | Medium |
| **Buzzer resonant frequency** | Confirm BZ1 resonant frequency and set PWM accordingly on PB12. | Low |
| **Custom BLE UUIDs** | Define 128-bit UUIDs for measurement notification and command write characteristics. | Medium |
| **PCB dimensions** | Define main board outline matching enclosure. | Medium |
| **LiPo cell dimensions** | Select cell fitting enclosure, confirm JST-PH polarity. | Medium |
| **5V boost validation** | Verify SD6210A output voltage under load (buzzer) at minimum battery (3.6V input). | Low |
| ~~FFC pitch~~ | ~~Confirmed: J3 = 1.0 mm pitch~~ | ~~Resolved~~ |
| ~~Crystal load caps~~ | ~~33 pF (CL=20 pF, C_stray≈3 pF)~~ | ~~Resolved~~ |
| ~~Encoder selection~~ | ~~Bourns PEC11R-4215F-S0024 (C143790)~~ | ~~Resolved~~ |
| ~~USB-C connector~~ | ~~TYPE-C-31-M-12 (C165948)~~ | ~~Resolved~~ |

---

*End of specification*

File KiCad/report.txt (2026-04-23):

Info: Processing symbol 'BZ1:local_CPT-9019A:CPT-9019A-SMT-TR'.
Info: Processing symbol 'R3:Resistor_SMD:R_0603_1608Metric'.
Info: Processing symbol 'C1:Capacitor_SMD:C_0603_1608Metric'.
Info: Processing symbol 'C2:Capacitor_SMD:C_0603_1608Metric'.
Info: Processing symbol 'C3:Capacitor_SMD:C_0603_1608Metric'.
Info: Processing symbol 'C4:Capacitor_SMD:C_0603_1608Metric'.
Info: Processing symbol 'C5:Capacitor_SMD:C_0603_1608Metric'.
Info: Processing symbol 'C6:Capacitor_SMD:C_0603_1608Metric'.
Info: Processing symbol 'C7:Resistor_SMD:R_0603_1608Metric'.
Info: Processing symbol 'C8:Capacitor_SMD:C_0603_1608Metric'.
Info: Processing symbol 'C9:Capacitor_SMD:C_0603_1608Metric'.
Info: Processing symbol 'C10:Capacitor_SMD:C_0603_1608Metric'.
Info: Processing symbol 'C11:Capacitor_SMD:C_0603_1608Metric'.
Info: Processing symbol 'C12:Capacitor_SMD:C_0805_2012Metric'.
Info: Processing symbol 'C13:Capacitor_SMD:C_0603_1608Metric'.
Info: Processing symbol 'C14:Capacitor_SMD:C_0603_1608Metric'.
Info: Processing symbol 'C15:Capacitor_SMD:C_0603_1608Metric'.
Info: Processing symbol 'C16:Capacitor_SMD:C_0603_1608Metric'.
Info: Processing symbol 'C17:Capacitor_SMD:C_0603_1608Metric'.
Info: Processing symbol 'C18:Capacitor_SMD:C_0603_1608Metric'.
Info: Processing symbol 'C19:Capacitor_SMD:C_0603_1608Metric'.
Info: Processing symbol 'C20:Capacitor_SMD:C_0805_2012Metric'.
Info: Processing symbol 'C21:Capacitor_SMD:C_0603_1608Metric'.
Info: Processing symbol 'C22:Capacitor_SMD:C_0603_1608Metric'.
Info: Processing symbol 'D1:LED_SMD:LED_0603_1608Metric'.
Info: Processing symbol 'Q2:Package_SO:TSSOP-8_4.4x3mm_P0.65mm'.
Info: Processing symbol 'J2:local_FTSH-107:FTSH-107-01-L-DV-K'.
Info: Processing symbol 'D2:LED_SMD:LED_0603_1608Metric'.
Info: Processing symbol 'R1:Resistor_SMD:R_0603_1608Metric'.
Info: Processing symbol 'R2:Resistor_SMD:R_0603_1608Metric'.
Info: Processing symbol 'J1:Connector_FFC-FPC:Hirose_FH12-10S-0.5SH_1x10-1MP_P0.50mm_Horizontal'.
Info: Processing symbol 'Q1:Package_TO_SOT_SMD:SOT-23'.
Info: Processing symbol 'R4:Resistor_SMD:R_0603_1608Metric'.
Info: Processing symbol 'R5:Resistor_SMD:R_0603_1608Metric'.
Info: Processing symbol 'R6:Resistor_SMD:R_0603_1608Metric'.
Info: Processing symbol 'R7:Resistor_SMD:R_0603_1608Metric'.
Info: Processing symbol 'U1:Package_TO_SOT_SMD:SOT-23-6'.
Info: Processing symbol 'U2:Package_SO:SOP-8_3.9x4.9mm_P1.27mm'.
Info: Processing symbol 'U3:Package_TO_SOT_SMD:SOT-23-5'.
Info: Processing symbol 'U4:Package_TO_SOT_SMD:SOT-23-6'.
Info: Processing symbol 'U5:Package_QFP:LQFP-64_10x10mm_P0.5mm'.
Info: Processing symbol 'Y1:Crystal:Crystal_SMD_5032-2Pin_5.0x3.2mm'.
Info: Processing symbol 'U6:Package_SO:SSOP-20_5.3x7.2mm_P0.65mm'.
Info: Processing symbol 'U7:local_RN4871:RN4871-I_RM128'.
Info: Processing symbol 'U8:Package_SO:TSSOP-14_4.4x5mm_P0.65mm'.
Info: Processing symbol 'U9:Package_SO:TSSOP-8_4.4x3mm_P0.65mm'.
Warning: No net found for component D2 pad 2 (no pin 2 in symbol).
Warning: No net found for component U5 pad 2 (no pin 2 in symbol).
Warning: No net found for component U5 pad 1 (no pin 1 in symbol).
Warning: No net found for component U5 pad 51 (no pin 51 in symbol).
Warning: No net found for component U5 pad 54 (no pin 54 in symbol).
Warning: No net found for component U5 pad 56 (no pin 56 in symbol).
Warning: No net found for component J1 pad MP (no pin MP in symbol).
Warning: No net found for component U5 pad 4 (no pin 4 in symbol).
Warning: No net found for component U5 pad 3 (no pin 3 in symbol).
Warning: No net found for component U5 pad 59 (no pin 59 in symbol).
Warning: No net found for component U5 pad 16 (no pin 16 in symbol).
Warning: No net found for component U5 pad 29 (no pin 29 in symbol).
Warning: No net found for component U5 pad 53 (no pin 53 in symbol).
Warning: No net found for component U5 pad 5 (no pin 5 in symbol).
Warning: No net found for component U5 pad 64 (no pin 64 in symbol).
Warning: No net found for component U5 pad 55 (no pin 55 in symbol).
Warning: No net found for component U5 pad 41 (no pin 41 in symbol).
Warning: No net found for component U5 pad 58 (no pin 58 in symbol).
Warning: No net found for component U5 pad 52 (no pin 52 in symbol).
Warning: No net found for component J1 pad MP (no pin MP in symbol).
Warning: No net found for component D2 pad 1 (no pin 1 in symbol).
Warning: No net found for component D1 pad 1 (no pin 1 in symbol).
Warning: No net found for component D1 pad 2 (no pin 2 in symbol).
Warning: No net found for component U5 pad 40 (no pin 40 in symbol).
Error: Cannot add U7 (footprint 'local_RN4871:RN4871-I_RM128' not found).
Error: Cannot add U2 (footprint 'Package_SO:SOP-8_3.9x4.9mm_P1.27mm' not found).
Error: Cannot add J2 (footprint 'local_FTSH-107:FTSH-107-01-L-DV-K' not found).
Error: Cannot add BZ1 (footprint 'local_CPT-9019A:CPT-9019A-SMT-TR' not found).

Info: Total warnings: 24, errors: 4.

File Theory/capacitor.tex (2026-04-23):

\documentclass[11pt,a4paper]{article}

\usepackage{amsmath}
\usepackage{amssymb}
\usepackage{geometry}
\usepackage{pgfplots}
\usepackage{pgfplotstable}
\usepackage{siunitx}
\usepackage{booktabs}
\usepackage{hyperref}
\usepackage{microtype}
\usepackage{parskip}

\pgfplotsset{compat=1.18}
\geometry{margin=2.5cm}

\sisetup{
  separate-uncertainty,
  per-mode=symbol
}

\hypersetup{
  colorlinks=true,
  linkcolor=black,
  urlcolor=blue
}

\title{Capacitance of a Tilted Circular Parallel-Plate Capacitor\\
       with Application to Precision Tilt Measurement}
\author{}
\date{}

\begin{document}

\maketitle
\tableofcontents
\bigskip

% ─────────────────────────────────────────────────────────────
\section{Problem Statement}
% ─────────────────────────────────────────────────────────────

Precision tilt sensors based on capacitive measurement exploit the
sensitivity of capacitance to small changes in the air gap between two
conducting plates.  In a practical instrument, a pendulum of length~$L$
suspends one plate so that its centre-to-centre distance to a fixed
reference plate varies with the tilt angle~$\alpha$.  When the
instrument is tilted, the two plates are no longer parallel: they subtend
the same angle~$\alpha$.

The goal of this note is to derive a closed-form expression for the
capacitance as a function of the tilt angle, compare it with two
progressively cruder approximations, and invert each expression to
obtain~$\alpha$ as a function of the measured capacitance.

% ─────────────────────────────────────────────────────────────
\section{Variable Definitions and Conventions}
% ─────────────────────────────────────────────────────────────

\begin{center}
\begin{tabular}{@{}lll@{}}
\toprule
Symbol & Unit & Description \\
\midrule
$\alpha$ & \si{\radian} & Tilt angle; $\alpha = 0$ corresponds to parallel plates \\
$L$      & \si{\metre}  & Pendulum length (constant) \\
$r$      & \si{\metre}  & Radius of the circular capacitor plates (constant) \\
$g$      & \si{\metre}  & Neutral air gap at $\alpha = 0$ (constant, $g > 0$) \\
$d_c$    & \si{\metre}  & Centre-to-centre plate distance at angle $\alpha$ \\
$\varepsilon_0$ & \si{\farad\per\metre} & Permittivity of free space,
                  $\varepsilon_0 = \SI{8.854e-12}{\farad\per\metre}$ \\
$C$      & \si{\farad}  & Total capacitance \\
$x$      & \si{\metre}  & Signed distance from the plate centre along the tilt axis \\
\bottomrule
\end{tabular}
\end{center}

By convention, $\alpha > 0$ means the pendulum swings in the positive
$x$-direction, closing the gap on that side.  Negative values of~$\alpha$
are equally valid and correspond to the opposite direction.

% ─────────────────────────────────────────────────────────────
\section{Geometry and Physical Limits}
% ─────────────────────────────────────────────────────────────

\subsection{Centre distance as a function of tilt}

The pendulum geometry gives the centre distance

\begin{equation}
  d_c(\alpha) = g - L\sin\alpha .
  \label{eq:dc}
\end{equation}

At $\alpha = 0$ the plates are parallel with uniform gap $g$.  For
$\alpha \neq 0$ the plates are tilted by the same angle~$\alpha$, so the
local gap at a signed distance~$x$ from the plate centre (measured along
the tilt axis) is

\begin{equation}
  d(x,\alpha) = d_c(\alpha) + x\sin\alpha .
  \label{eq:localGap}
\end{equation}

\subsection{Physical validity limit}

The plates must not touch anywhere.  The smallest gap occurs at
$x = -r$ (the trailing edge when $\alpha > 0$), so the condition
$d(-r,\alpha) > 0$ gives

\begin{equation}
  \boxed{\alpha < \arcsin\!\left(\frac{g}{L + r}\right).}
  \label{eq:alphaMax}
\end{equation}

% ─────────────────────────────────────────────────────────────
\section{Exact Capacitance}
% ─────────────────────────────────────────────────────────────

\subsection{From the parallel-plate formula to an integral}

The standard parallel-plate capacitor formula,

\begin{equation}
  C = \varepsilon_0 \frac{A}{d},
  \label{eq:parallelPlate}
\end{equation}

assumes a uniform gap~$d$ over the entire plate area~$A$.  When the gap
varies with position, equation~\eqref{eq:parallelPlate} is applied
locally to each infinitesimal area element $\mathrm{d}A$, and the total
capacitance is obtained by integrating the local contribution
$\mathrm{d}C = \varepsilon_0\,\mathrm{d}A / d(x,y)$:

\begin{equation}
  C = \varepsilon_0 \iint_{\text{disk}} \frac{\mathrm{d}A}{d(x,y)}.
  \label{eq:doubleIntegral}
\end{equation}

A double integral is required because the integration domain is a
two-dimensional disk.  Since the gap~\eqref{eq:localGap} depends only
on~$x$ and not on~$y$, the inner integral over~$y$ can be evaluated
immediately.  For the circular plate of radius~$r$ the $y$-limits at
a given~$x$ are $\pm\sqrt{r^2 - x^2}$, giving

\begin{equation}
  C(\alpha) = 2\varepsilon_0 \int_{-r}^{+r}
              \frac{\sqrt{r^2 - x^2}}{d_c + x\sin\alpha}\,\mathrm{d}x .
  \label{eq:singleIntegral}
\end{equation}

\subsection{Evaluation of the integral}

Equation~\eqref{eq:singleIntegral} is of the standard form

\begin{equation}
  I = \int_{-r}^{+r} \frac{\sqrt{r^2 - x^2}}{a + bx}\,\mathrm{d}x
    = \frac{\pi}{b^2}\!\left(a - \sqrt{a^2 - b^2 r^2}\right),
    \qquad a > br,
  \label{eq:stdIntegral}
\end{equation}

with $a = d_c$ and $b = \sin\alpha$.  Substituting and simplifying gives

\begin{equation}
  C(\alpha) = \frac{2\pi\varepsilon_0}{(\sin\alpha)^2}
              \!\left(d_c - \sqrt{d_c^2 - r^2(\sin\alpha)^2}\right).
  \label{eq:exactRaw}
\end{equation}

This form is indeterminate ($0/0$) at $\alpha = 0$.  Rationalising by
multiplying numerator and denominator by
$d_c + \sqrt{d_c^2 - r^2(\sin\alpha)^2}$ eliminates the singularity:

\begin{equation}
  \boxed{C(\alpha) = \frac{2\pi\varepsilon_0\, r^2}
         {d_c + \sqrt{d_c^2 - r^2(\sin\alpha)^2}},}
  \label{eq:exact}
\end{equation}

with $d_c = g - L\sin\alpha$ from equation~\eqref{eq:dc}.
Equation~\eqref{eq:exact} is valid for all~$\alpha$ satisfying the
physical limit~\eqref{eq:alphaMax}.

\subsection{Verification at \texorpdfstring{$\alpha = 0$}{alpha = 0}}

At $\alpha = 0$, $d_c \to g$ and $\sin\alpha \to 0$.  Expanding the
square root for small $s = \sin\alpha$,

\begin{equation}
  \sqrt{d_c^2 - r^2 s^2} \approx d_c - \frac{r^2 s^2}{2 d_c},
\end{equation}

so the denominator of~\eqref{eq:exact} approaches $2d_c \to 2g$, giving

\begin{equation}
  C(0) = \frac{\pi r^2 \varepsilon_0}{g} = \varepsilon_0 \frac{A}{g},
  \label{eq:C0}
\end{equation}

which is the standard parallel-plate result with $A = \pi r^2$. \checkmark

% ─────────────────────────────────────────────────────────────
\section{Approximate Formulae}
% ─────────────────────────────────────────────────────────────

\subsection{Approximation neglecting the tilt angle}

If the plate radius~$r$ is small compared with the ratio $d_c/\sin\alpha$,
the term $r^2(\sin\alpha)^2$ under the square root in~\eqref{eq:exact} is
negligible.  Physically, this corresponds to treating the plates as
parallel (using only the centre gap) while still accounting for the
change in $d_c$ with~$\alpha$.  Setting $r\sin\alpha \approx 0$ in the
denominator of~\eqref{eq:exact} reduces it to $2d_c$:

\begin{equation}
  \boxed{C_{\text{approx}}(\alpha) = \frac{\pi r^2 \varepsilon_0}{d_c}
         = \frac{\pi r^2 \varepsilon_0}{g - L\sin\alpha}.}
  \label{eq:approx}
\end{equation}

\subsection{Linear approximation}

A further simplification is obtained by linearising around $\alpha = 0$.
The sensitivity is found by differentiating~\eqref{eq:approx} with respect
to~$C$ at the neutral point.  Both the exact and approximate formulae
coincide at $\alpha = 0$, so their sensitivities are identical there.
Implicit differentiation gives

\begin{equation}
  \frac{\mathrm{d}\alpha}{\mathrm{d}C}\bigg|_{\alpha=0}
  = \frac{g^2}{\pi r^2 \varepsilon_0\, L},
\end{equation}

and the linear approximation around $\alpha = 0$, $C = C_0$ is

\begin{equation}
  \boxed{\alpha_{\text{lin}} = \frac{g^2}{\pi r^2 \varepsilon_0\, L}
         \!\left(C - C_0\right),}
  \label{eq:linear}
\end{equation}

with $C_0 = \pi r^2 \varepsilon_0 / g$ from equation~\eqref{eq:C0}.

% ─────────────────────────────────────────────────────────────
\section{Inversion: Solving for \texorpdfstring{$\alpha$}{alpha}}
% ─────────────────────────────────────────────────────────────

In practice, the capacitance~$C$ is the measured quantity and the tilt
angle~$\alpha$ is the desired output.  We solve each formula for~$\alpha$.

\subsection{Linear approximation}

Equation~\eqref{eq:linear} is already solved for~$\alpha$:

\begin{equation}
  \alpha_{\text{lin}} = \frac{g^2}{\pi r^2 \varepsilon_0\, L}
                        \!\left(C - C_0\right).
  \label{eq:alphaLin}
\end{equation}

\subsection{Approximate formula}

Solving~\eqref{eq:approx} for $\sin\alpha$ and applying the inverse sine:

\begin{equation}
  \boxed{\alpha_{\text{approx}} = \arcsin\!\left[\frac{1}{L}
         \!\left(g - \frac{\pi r^2 \varepsilon_0}{C}\right)\right].}
  \label{eq:alphaApprox}
\end{equation}

\subsection{Exact formula}

Starting from~\eqref{eq:exact} and writing $s = \sin\alpha$,
$d_c = g - Ls$, and $k = 2\pi\varepsilon_0 r^2 / C$:

\begin{align}
  d_c + \sqrt{d_c^2 - r^2 s^2} &= k \notag \\
  \sqrt{d_c^2 - r^2 s^2}        &= k - d_c \notag \\
  d_c^2 - r^2 s^2               &= k^2 - 2k\,d_c + d_c^2.
\end{align}

The $d_c^2$ terms cancel; substituting $d_c = g - Ls$ and collecting
terms in~$s$ yields a quadratic:

\begin{equation}
  r^2 s^2 + 2kL\,s + (k^2 - 2kg) = 0,
\end{equation}

with solution

\begin{equation}
  s = \frac{-kL \pm \sqrt{k^2(L^2 - r^2) + 2kgr^2}}{r^2},
  \qquad k = \frac{2\pi\varepsilon_0 r^2}{C}.
  \label{eq:quadSol}
\end{equation}

The two roots correspond to positive and negative tilt directions.
Only the root satisfying the physical limit~\eqref{eq:alphaMax} is
physically meaningful, so

\begin{equation}
  \boxed{\alpha_{\text{exact}} = \arcsin\!\left(
         \frac{-kL \pm \sqrt{k^2(L^2 - r^2) + 2kgr^2}}{r^2}
         \right),}
  \label{eq:alphaExact}
\end{equation}

where the sign is chosen such that $|\alpha| <
\arcsin\!\bigl(g/(L+r)\bigr)$.

% ─────────────────────────────────────────────────────────────
\section{Numerical Example and Graphical Comparison}
% ─────────────────────────────────────────────────────────────

\subsection{Instrument parameters}

\begin{center}
\begin{tabular}{@{}lll@{}}
\toprule
Parameter & Value & Description \\
\midrule
$L$ & \SI{40}{\milli\metre} & Pendulum length \\
$r$ & \SI{10}{\milli\metre} & Plate radius \\
$g$ & \SI{0.1}{\milli\metre} & Neutral air gap \\
\bottomrule
\end{tabular}
\end{center}

From equation~\eqref{eq:C0} the capacitance at $\alpha = 0$ is

\begin{equation}
  C_0 = \frac{\pi \times (10^{-2})^2 \times 8.854\times10^{-12}}{10^{-4}}
      = \SI{27.82}{\pico\farad}.
\end{equation}

The physical validity limit from equation~\eqref{eq:alphaMax} is

\begin{equation}
  \alpha_{\max} = \arcsin\!\left(\frac{0.1}{50}\right)
                = \arcsin(0.002) \approx \SI{412.5}{\arcsecond}
                \approx \SI{2000}{\micro\metre\per\metre}.
\end{equation}

\subsection{Comparison of the three models}

Figure~\ref{fig:comparison} shows $C$ as a function of~$\alpha$ for the
exact formula~\eqref{eq:exact}, the tilt-neglecting
approximation~\eqref{eq:approx}, and the linear
approximation~\eqref{eq:linear} over 70\,\% of the valid range.  A
secondary axis expresses the angle in \si{\micro\metre\per\metre}
(slope units used in metrology), related to arc seconds by
$1'' \approx 4.848\;\si{\micro\metre\per\metre}$.

\begin{figure}[ht]
\centering
\pgfplotstableread{capdata.dat}{\capdata}
\begin{tikzpicture}
\begin{axis}[
  width  = 0.85\textwidth,
  height = 7.5cm,
  xlabel = {Tilt angle $\alpha$ (arc seconds)},
  ylabel = {Capacitance $C$ (pF)},
  xmin = -300, xmax = 300,
  xtick distance = 100,
  grid = both,
  grid style = {line width=0.3pt, draw=gray!30},
  legend pos = north west,
  legend style = {font=\small},
  tick label style = {font=\small},
  label style = {font=\small},
  % Secondary x-axis (µm/m = arcsec * 4.8481)
  extra x ticks = {-288.77, -192.51, -96.26, 0, 96.26, 192.51, 288.77},
  extra x tick labels = {$-1400$, $-933$, $-467$, $0$, $467$, $933$, $1400$},
  extra x tick style = {
    xticklabel style = {yshift=0.65cm, font=\small},
    tick style = {yshift=0.4cm},
    grid = none,
  },
]
\addplot[blue,   thick,              ] table[x=arcsec, y=Cexact  ]{\capdata};
\addplot[teal,   thick, dashed,      ] table[x=arcsec, y=Capprox ]{\capdata};
\addplot[orange, thick, dotted, very thick] table[x=arcsec, y=Clinear ]{\capdata};
\legend{Exact \eqref{eq:exact},
        Approximate \eqref{eq:approx},
        Linear \eqref{eq:linear}}
\end{axis}
% µm/m label above the plot
\node at (7.2, 7.85) [font=\small] {Tilt (\si{\micro\metre\per\metre})};
\end{tikzpicture}
\caption{Capacitance versus tilt angle for the three models.
         Instrument parameters: $L=\SI{40}{\milli\metre}$,
         $r=\SI{10}{\milli\metre}$, $g=\SI{0.1}{\milli\metre}$.
         The plot covers 70\,\% of the physical validity range.
         The exact and approximate curves are nearly indistinguishable
         at this scale, confirming that the tilt correction is negligible
         for these dimensions.  The linear model diverges noticeably
         toward the edges of the range.}
\label{fig:comparison}
\end{figure}

% ─────────────────────────────────────────────────────────────
\section{Summary}
% ─────────────────────────────────────────────────────────────

Starting from the parallel-plate capacitance formula, three expressions
for the capacitance of a pendulum-coupled circular capacitor have been
derived and compared.

\begin{enumerate}

  \item \textbf{Exact formula} (eq.~\ref{eq:exact}): valid for all
        angles within the physical limit~\eqref{eq:alphaMax}; accounts
        fully for both the change in centre gap and the angular tilt of
        the plates.

  \item \textbf{Approximate formula} (eq.~\ref{eq:approx}): treats the
        plates as parallel using only the centre gap; accurate when
        $r\sin\alpha \ll d_c$.  For the example parameters the error is
        negligible across the entire operating range.

  \item \textbf{Linear approximation} (eq.~\ref{eq:linear}): a
        first-order Taylor expansion around $\alpha = 0$; valid only for
        small deviations from the neutral position.

\end{enumerate}

Each formula has been inverted analytically to yield $\alpha$ as a
function of~$C$ (equations~\ref{eq:alphaExact},
\ref{eq:alphaApprox}, \ref{eq:alphaLin}).  The exact inversion requires
solving a quadratic in $\sin\alpha$; both roots are real and correspond
to tilt in opposite directions, and the physically valid root is selected
by the limit~\eqref{eq:alphaMax}.

\end{document}

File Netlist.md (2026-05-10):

# InclinationMeter — Netlist & Hardware Reference

**Version:** 1.0  
**Date:** 2026-05-09  
**Source:** Finalized KiCad 10 schematics (commit 03fac10)  
**Schematic tool:** KiCad 10.0, library: sldrnrd_kicad_lib

> This document is the single source of truth for firmware development.  
> All pin assignments, net names, and component roles are derived directly  
> from the KiCad schematics. Do not rely on older documents.

---

## 1. Schematic Hierarchy

| Sheet file | Description |
|---|---|
| `InclinationMeter.kicad_sch` | Root sheet (title block, hierarchy) |
| `KiCad/power.kicad_sch` | Power management, battery charging, LDOs, boost converter |
| `KiCad/mcu.kicad_sch` | MCU (U6), BLE module (U7), all MCU signal routing |
| `KiCad/ui.kicad_sch` | Display (DS1), encoders (SW1/SW2), LEDs, buzzer |
| `KiCad/connectors.kicad_sch` | External connectors: J2–J6, sensor headers |

Global labels are used for all inter-sheet net connections.

---

## 2. Power Architecture

### 2.1 Power Rails

| Rail | Voltage | Source | Enabled by |
|---|---|---|---|
| `BAT+` | 3.0–4.2 V | Battery (J2 USB-C charge input) | always |
| `3V3` | 3.3 V | U2 LP5907MFX-3.3 LDO | `3V3_EN` (PB9, active-high) |
| `3V3_Sensors` | 3.3 V | U4 LP5907MFX-3.3 LDO | `LDO_EN` (power-sheet local, tied to both LDOs) |
| `5V0` | 5.0 V | U5 SD6210A boost converter | `5V_EN` (PB8, active-high) |
| `VBUS` | 5.0 V | USB-C input | external |

`3V3` powers: MCU (U6), BLE module (U7), EEPROM (U10), display (DS1), buzzer buffer (U8).  
`3V3_Sensors` powers: SCL3300 (U3/J3), PCAP04 #1 (J5), PCAP04 #2 (J6).  
`5V0` powers: buzzer (BZ1) via U8 buffer output.

> **Note:** `LDO_EN` is a local net in power.kicad_sch that enables both LP5907 LDOs (U2 and U4) simultaneously. There is no separate MCU GPIO for `LDO_EN`; it is driven by the power sequencing circuit on the power sheet.

### 2.2 Power Switching

| Component | Type | Function |
|---|---|---|
| Q3 | AO3400A (N-ch MOSFET) | Battery charging control |
| Q4 | AO3400A (N-ch MOSFET) | Battery sense divider isolation (prevents drain in off-state) |
| Q2 | FS8205A (dual N-ch MOSFET) | Battery FET (reverse protection / disconnect) |
| Q1 | DMG2305UX (P-ch MOSFET) | Charge enable gate control |
| D1–D4 | BAT54WS (Schottky) | Flyback / reverse-blocking diodes |

### 2.3 Battery Charger

| Component | Value/Type | Net | Notes |
|---|---|-----|---|
| U1 | TP4056 | — | 1-cell Li-Ion charger |
| R3 | 2 kΩ | RPROG | Sets charge current ≈ 500 mA |
| R5 | 2 kΩ | — | Second RPROG (parallel path) |

Charger outputs: `CHARGE_SENSE` (GPIO input, PC4), `~{CHARGE_EN}` (GPIO output, PB7, active-low).

### 2.4 Battery Voltage Sense

Resistor divider on `BAT+` → `BATTERY_SENSE` → PB14 (ADC input):

| Component | Value |
|---|---|
| R9 | 100 kΩ (upper) |
| R6 | 33 kΩ (lower) |

Divider ratio: 33k/(100k+33k) = 0.248. Full battery (4.2 V) → 1.041 V on ADC. Use VREF+ = 3.3 V for ADC reference.

### 2.5 Power Control Signals

| Net | Direction | MCU Pin | Description |
|-----|---|---|---|
| `3V3_EN` | Output | PB9 | Enables U2 LP5907 (3V3 rail). Active-high. |
| `5V_EN` | Output | PB8 | Enables U5 SD6210A (5V0 rail). Active-high. |
| `~{CHARGE_EN}` | Output | PB7 | Disables TP4056 charger. Active-low (low = charging enabled). |
| `PWR_ON` | — | — | Power-on latch signal (power sheet logic) |
| `STANDBY_SENSE` | Input | PC5 | Detects low-power standby condition |
| `VBUS_SENSE` | Input | PC7 | Detects USB-C VBUS presence (5 V from host) |

---

## 3. Component List

### 3.1 ICs

| Ref | Part | Description | Sheet |
|-----|---|---|---|
| U1 | TP4056 | Li-Ion 1-cell battery charger, SOT-23-6 | power |
| U2 | LP5907MFX-3.3/NOPB | 3.3 V LDO, 250 mA, SOT-23-5; supplies `3V3` | power |
| U3 | SCL3300 | 3-axis inclinometer, SPI, SO-14 | connectors (via J3) |
| U4 | LP5907MFX-3.3/NOPB | 3.3 V LDO, 250 mA, SOT-23-5; supplies `3V3_Sensors` | power |
| U5 | SD6210A | 5 V synchronous boost converter; supplies `5V0` | power |
| U6 | STM32G0B1RET6 | MCU, Cortex-M0+, LQFP64 | mcu |
| U7 | RN4871-I/RM128 | BLE 5.0 module (UART interface) | mcu |
| U8 | 74AHCT244 | Octal buffer/driver (3.3 V → 5 V level shift for buzzer) | ui |
| U9 | PCAP04 | Capacitance-to-digital converter #2 (I2C) | connectors (via J6) |
| U10 | AT24Cxx | I2C EEPROM | mcu |
| U11 | PCAP04 | Capacitance-to-digital converter #1 (I2C) | connectors (via J5) |

> U3 (SCL3300) mounts on a daughter board connected via J3 (6-pin FFC).  
> U11 and U9 (PCAP04) mount on daughter boards connected via J5 and J6 (10-pin FFC).

### 3.2 Discrete Semiconductors

| Ref | Part | Function |
|-----|---|---|
| Q1 | DMG2305UX | P-ch MOSFET, charger gate |
| Q2 | FS8205A | Dual N-ch MOSFET, battery protection FET |
| Q3 | AO3400A | N-ch MOSFET, battery charging control |
| Q4 | AO3400A | N-ch MOSFET, battery sense divider isolation |
| D1–D4 | BAT54WS | Schottky diode, SOD-323 |
| D5–D8 | (see schematic) | Additional diodes (power sheet) |

### 3.3 Passive Components (Key Values)

| Ref | Value | Function |
|-----|---|---|
| R3 | 2 kΩ | TP4056 RPROG (charge current) |
| R5 | 2 kΩ | TP4056 RPROG (parallel) |
| R6 | 33 kΩ | BATTERY_SENSE lower divider |
| R8 | 1 kΩ | Current limit resistor |
| R9 | 100 kΩ | BATTERY_SENSE upper divider |
| R10 | 68 kΩ | Pull-up/filter (power sheet) |
| Y1 | 32.768 kHz | RTC crystal (LQFP64 pins PC14/PC15, OSC32_IN/OUT) |

### 3.4 Connectors

| Ref | Part | Pins | Function |
|-----|---|---|---|
| J2 | USB-C receptacle | — | USB data + battery charging input |
| J3 | Header_FFC_1.0mm_06 (JUSHUO AFA07) | 6 | SCL3300 sensor FFC |
| J4 | Header_50mil_2x07 | 14 (2×7) | SWD debug header (STLINK-V3MINIE) |
| J5 | FFC 10-pin | 10 | PCAP04 #1 sensor FFC |
| J6 | FFC 10-pin | 10 | PCAP04 #2 sensor FFC |

### 3.5 Electromechanical

| Ref | Part | Function |
|-----|---|---|
| SW1 | Rotary encoder with push | Encoder 1 (ENC_1A/B/SW) |
| SW2 | Rotary encoder with push | Encoder 2 (ENC_2A/B/SW) |
| BZ1 | Piezo buzzer | Driven at 5 V via U8 (74AHCT244) |
| DS1 | LS027B7DH01 (Sharp Memory LCD) | 2.7" reflective display, SPI |

---

## 4. Connector Pinouts

### 4.1 J3 — SCL3300 FFC (6-pin, 1.0 mm pitch)

| Pin | Net | Direction | Description |
|-----|-----|---|---|
| 1 | 3V3_Sensors | — | 3.3 V supply for SCL3300 |
| 2 | SCL3300_CS | MCU→SCL3300 | SPI chip select (active-low) |
| 3 | SCL3300_SCK | MCU→SCL3300 | SPI clock |
| 4 | SCL3300_MISO | SCL3300→MCU | SPI data out |
| 5 | SCL3300_MOSI | MCU→SCL3300 | SPI data in |
| 6 | GND | — | Ground |

### 4.2 J4 — Debug Header (2×7, 50 mil pitch)

| Pin | Net | Description |
|-----|-----|---|
| 1 | VCC (3V3) | Target voltage sense for STLINK |
| 2 | SWDIO | SWD data |
| 3 | GND | Ground |
| 4 | SWCLK | SWD clock |
| 5 | GND | Ground |
| 6 | SWO | Serial Wire Output (trace, Cortex-M0+ — may not be functional) |
| 7 | — | NC |
| 8 | ~{RST} | Target reset |
| 9 | GND | Ground |
| 10 | DEBUG_UART_MCU_TO_PC | UART TX (MCU→PC) |
| 11 | DEBUG_UART_PC_TO_MCU | UART RX (PC→MCU) |
| 12–14 | GND / NC | — |

> The exact J4 pin-to-position mapping follows the STLINK-V3MINIE connector standard.  
> The debug UART uses PD9 (TX to PC) and PD8 (RX from PC).

### 4.3 J5 — PCAP04 #1 FFC (10-pin)

| Pin | Net | Direction | Description |
|-----|-----|---|---|
| 1 | 3V3_Sensors | — | 3.3 V supply |
| 2 | PCAP04_1_SCL | MCU→PCAP04 | I2C clock |
| 3 | PCAP04_1_SDA | Bidirectional | I2C data |
| 4–7 | GND / NC | — | Ground / no-connect |
| 8 | PCAP04_1_P3 | Bidirectional | PCAP04 port P3 (capacitance measurement) |
| 9 | PCAP04_1_P2 | Bidirectional | PCAP04 port P2 (capacitance measurement) |
| 10 | PCAP04_1_INT | PCAP04→MCU | Interrupt output |

### 4.4 J6 — PCAP04 #2 FFC (10-pin)

| Pin | Net | Direction | Description |
|-----|-----|---|---|
| 1 | 3V3_Sensors | — | 3.3 V supply |
| 2 | PCAP04_2_SCL | MCU→PCAP04 | I2C clock |
| 3 | PCAP04_2_SDA | Bidirectional | I2C data |
| 4–7 | GND / NC | — | Ground / no-connect |
| 8 | PCAP04_2_P3 | Bidirectional | PCAP04 port P3 |
| 9 | PCAP04_2_P2 | Bidirectional | PCAP04 port P2 |
| 10 | PCAP04_2_INT | PCAP04→MCU | Interrupt output |

> **Compatibility note:** J5 and J6 are 10-pin FFC connectors.  
> Existing prototype daughter boards using 6-pin FFC are **physically incompatible** with this main board.  
> New daughter boards are required.

---

## 5. MCU Pin Assignments — U6 (STM32G0B1RET6, LQFP64)

Pin assignments derived by coordinate analysis of `KiCad/mcu.kicad_sch`.  
All global labels connected to the MCU symbol are mapped below.

### 5.1 Left Edge — Pins 1–16

| Phys. Pin | Port | Net / Signal | Function |
|---|---|---|---|
| 1 | PC11 | PCAP04_2_P2 | PCAP04 #2 port P2 |
| 2 | PC12 | PCAP04_2_P3 | PCAP04 #2 port P3 |
| 3 | PC13 | PCAP04_2_SDA | I2C SDA — PCAP04 #2 |
| 4 | PC14 | PCAP04_2_SCL | I2C SCL — PCAP04 #2 (also OSC32_IN if RTC crystal fitted) |
| 5 | PC15 | ~{RST} | External reset input from J4 debug header ¹ |
| 6 | VBAT | [VBAT] | RTC backup power (connect to 3V3 or coin cell) |
| 7 | VREF+ | [VREF+] | ADC reference (connect to 3V3) |
| 8 | VDD | [3V3] | Core supply |
| 9 | VSS | [GND] | Ground |
| 10 | PF0 | NC | OSC_IN (crystal not used on PF0/PF1) |
| 11 | PF1 | NC | OSC_OUT |
| 12 | ~{NRST} | — | Reset pin (no global label; see note ¹) |
| 13 | PC0 | NC | — |
| 14 | PC1 | ENC_2SW | Encoder 2 push-button (active-low, RC filter) |
| 15 | PC2 | ENC_2A | Encoder 2 channel A |
| 16 | PC3 | ENC_2B | Encoder 2 channel B |

¹ The `~{RST}` global label connects to PC15. The physical ~{NRST} pin (pin 12) has no global label in the schematic. This likely means PC15 is used as a software-monitored reset-request GPIO input, with firmware acting on it, rather than a hard-wired connection to NRST. Clarify with designer.

### 5.2 Top Edge — Pins 17–32

| Phys. Pin | Port | Net / Signal | Function |
|---|---|---|---|
| 17 | PA0 | ~{ENC_1SW} | Encoder 1 push-button (active-low, RC filter) |
| 18 | PA1 | ENC_1A | Encoder 1 channel A |
| 19 | PA2 | ENC_1B | Encoder 1 channel B |
| 20 | PA3 | EEPROM_SDA | I2C SDA — EEPROM (U10) |
| 21 | PA4 | EEPROM_SCL | I2C SCL — EEPROM (U10) |
| 22 | PA5 | LED_STATUS | Status LED drive |
| 23 | PA6 | LED_PWR | Power LED drive |
| 24 | PA7 | SWO | Serial Wire Output ² |
| 25 | PC4 | CHARGE_SENSE | Charger status input (from TP4056 CHRG pin) |
| 26 | PC5 | STANDBY_SENSE | Standby/sleep detection input |
| 27 | PB0 | DISP_MOSI | Display SPI data (LS027B7DH01 SI) |
| 28 | PB1 | DISP_VCOM | Display VCOM toggle (timer PWM recommended) |
| 29 | PB2 | DISP_ON | Display power enable |
| 30 | PB10 | DISP_SCK | Display SPI clock |
| 31 | PB11 | DISP_CS | Display SPI chip select (SCS) |
| 32 | PB12 | BUZZER | Buzzer drive signal (MCU logic → U8 → 5 V buzzer) |

² STM32G0B1 (Cortex-M0+) does not have ITM/SWO hardware. The SWO pin is included for debug header compatibility but will not carry trace data.

### 5.3 Right Edge — Pins 33–48

| Phys. Pin | Port | Net / Signal | Function |
|---|---|---|---|
| 33 | PB13 | TEMP_SENSE | Temperature sense ADC input |
| 34 | PB14 | BATTERY_SENSE | Battery voltage ADC input (R6/R9 divider) |
| 35 | PB15 | SWCLK | SWD clock signal to J4 — see note ³ |
| 36 | PA8 | SWDIO | SWD data signal to J4 — see note ³ |
| 37 | PA9 | USB_D+ | USB FS D+ (alternate pin mapping — see note ⁴) |
| 38 | PC6 | USB_D- | USB FS D− (alternate pin mapping — see note ⁴) |
| 39 | PC7 | VBUS_SENSE | USB VBUS detection |
| 40 | PD8 | DEBUG_UART_PC_TO_MCU | Debug UART RX |
| 41 | PD9 | DEBUG_UART_MCU_TO_PC | Debug UART TX |
| 42 | PA10 | NC | — |
| 43 | PA11 | NC | — |
| 44 | PA12 | PCAP04_1_INT | PCAP04 #1 interrupt input |
| 45 | PA13 | PCAP04_1_P3 | PCAP04 #1 port P3 — shared with SWDIO ³ |
| 46 | PA14 | PCAP04_1_P2 | PCAP04 #1 port P2 — shared with SWCLK ³ |
| 47 | PA15 | PCAP04_1_SDA | I2C SDA — PCAP04 #1 |
| 48 | PC8 | PCAP04_1_SCL | I2C SCL — PCAP04 #1 |

³ **SWD / PCAP04_1 pin conflict:** PA13 and PA14 are the hardware SWD pins (SWDIO/SWCLK) on all STM32G0B1 devices. In this schematic, PA13/PA14 are assigned to PCAP04_1_P3/P2. The `SWDIO` and `SWCLK` global labels (driving J4) appear at PA8/PB15 in the mcu.kicad_sch. Since PA8/PB15 are not standard SWD-capable pins, the STLINK connection via J4 must physically reach PA13/PA14. The SWDIO/SWCLK labels on PA8/PB15 may be routing artifacts in the schematic; verify with designer. During active SWD sessions, PCAP04_1 P2/P3 GPIO usage is inhibited.

⁴ **USB pin mapping:** Primary USB FS pins on STM32G0B1 are PA11 (D−) and PA12 (D+). The schematic assigns USB_D+ to PA9 and USB_D− to PC6. Verify in the STM32G0B1 alternate function table that USB remapping to PA9/PC6 is supported. PA11/PA12 are NC in this schematic.

### 5.4 Bottom Edge — Pins 49–64

| Phys. Pin | Port | Net / Signal | Function |
|---|---|---|---|
| 49 | PC9 | BLE_P2_0 | RN4871 GPIO P2_0 ↔ MCU |
| 50 | PD0 | BLE_P1_7 | RN4871 GPIO P1_7 ↔ MCU |
| 51 | PD1 | BLE_P3_6 | RN4871 GPIO P3_6 ↔ MCU |
| 52 | PD2 | BLE_P0_2 | RN4871 GPIO P0_2 ↔ MCU |
| 53 | PD3 | BLE_P1_6 | RN4871 GPIO P1_6 ↔ MCU |
| 54 | PD4 | ~{BLE_RST} | RN4871 hardware reset (active-low output from MCU) |
| 55 | PD5 | BLE_UART_BLE_TO_MCU | UART RX from RN4871 (USART2 RX) |
| 56 | PD6 | BLE_UART_MCU_TO_BLE | UART TX to RN4871 (USART2 TX) |
| 57 | PB3 | SCL3300_MOSI | SPI MOSI to SCL3300 |
| 58 | PB4 | SCL3300_MISO | SPI MISO from SCL3300 |
| 59 | PB5 | SCL3300_SCK | SPI clock to SCL3300 |
| 60 | PB6 | SCL3300_CS | SPI chip select for SCL3300 (active-low) |
| 61 | PB7 | ~{CHARGE_EN} | TP4056 charge enable (active-low; low = charging allowed) |
| 62 | PB8 | 5V_EN | Enable 5 V boost (U5 SD6210A), active-high |
| 63 | PB9 | 3V3_EN | Enable 3.3 V main LDO (U2), active-high |
| 64 | PC10 | PCAP04_2_INT | PCAP04 #2 interrupt input |

---

## 6. Peripheral Interface Summary

### 6.1 SPI — SCL3300 Inclinometer

| Signal | MCU Pin | Net |
|---|---|-----|
| SCK | PB5 | SCL3300_SCK |
| MOSI | PB3 | SCL3300_MOSI |
| MISO | PB4 | SCL3300_MISO |
| CS | PB6 | SCL3300_CS |

SPI peripheral: **SPI1** (PB3–PB6 — verify alternate function in STM32G0B1 datasheet).  
Mode: SPI Mode 0 (CPOL=0, CPHA=0) per SCL3300 datasheet.  
Supply rail: `3V3_Sensors`.

### 6.2 I2C — PCAP04 #1

| Signal | MCU Pin | Net |
|---|---|-----|
| SCL | PC8 | PCAP04_1_SCL |
| SDA | PA15 | PCAP04_1_SDA |
| INT | PA12 | PCAP04_1_INT |
| P2 | PA14 | PCAP04_1_P2 |
| P3 | PA13 | PCAP04_1_P3 |

I2C peripheral: verify which I2C instance supports PC8/PA15 on STM32G0B1.  
Supply rail: `3V3_Sensors` (via J5).

### 6.3 I2C — PCAP04 #2

| Signal | MCU Pin | Net |
|---|---|-----|
| SCL | PC14 | PCAP04_2_SCL |
| SDA | PC13 | PCAP04_2_SDA |
| INT | PC10 | PCAP04_2_INT |
| P2 | PC11 | PCAP04_2_P2 |
| P3 | PC12 | PCAP04_2_P3 |

> PC13/PC14 are also OSC32_IN/OUT (RTC crystal pins). See open item 2 below.

### 6.4 I2C — EEPROM (U10)

| Signal | MCU Pin | Net |
|---|---|-----|
| SCL | PA4 | EEPROM_SCL |
| SDA | PA3 | EEPROM_SDA |

Dedicated I2C bus for EEPROM only (separate from both PCAP04 buses).

### 6.5 SPI — Display (LS027B7DH01)

| Signal | MCU Pin | Net |
|---|---|-----|
| SCK | PB10 | DISP_SCK |
| MOSI (SI) | PB0 | DISP_MOSI |
| CS (SCS) | PB11 | DISP_CS |
| VCOM | PB1 | DISP_VCOM |
| Power on | PB2 | DISP_ON |

3-wire SPI (no MISO). VCOM must toggle at ≥ 1 Hz to prevent display damage.  
PB0 and PB10 are on different default SPI peripherals — use bit-banged SPI or verify compatible AF assignment in STM32G0B1 datasheet.

### 6.6 UART — BLE (RN4871)

| Signal | MCU Pin | Net | Direction |
|---|---|-----|---|
| TX (MCU→BLE) | PD6 | BLE_UART_MCU_TO_BLE | Output |
| RX (BLE→MCU) | PD5 | BLE_UART_BLE_TO_MCU | Input |
| ~{RST} | PD4 | ~{BLE_RST} | Output (active-low) |

UART peripheral: **USART2** (PD5/PD6 — verify AF).  
Default baud rate: 115200 baud, 8N1.

RN4871 GPIO connections:

| RN4871 GPIO | MCU Pin | Net |
|---|---|-----|
| P0_2 | PD2 | BLE_P0_2 |
| P1_6 | PD3 | BLE_P1_6 |
| P1_7 | PD0 | BLE_P1_7 |
| P2_0 | PC9 | BLE_P2_0 |
| P3_6 | PD1 | BLE_P3_6 |

### 6.7 UART — Debug (J4)

| Signal | MCU Pin | Net | Direction |
|---|---|-----|---|
| TX (MCU→PC) | PD9 | DEBUG_UART_MCU_TO_PC | Output |
| RX (PC→MCU) | PD8 | DEBUG_UART_PC_TO_MCU | Input |

UART peripheral: **USART3** or LPUART (PD8/PD9 — verify AF on STM32G0B1).

### 6.8 USB

| Signal | MCU Pin | Net |
|---|---|-----|
| D+ | PA9 | USB_D+ |
| D− | PC6 | USB_D- |
| VBUS sense | PC7 | VBUS_SENSE |

See note ⁴ in section 5.3 regarding non-standard USB pin assignment.

### 6.9 ADC Inputs

| Net | MCU Pin | Source |
|-----|---|---|
| BATTERY_SENSE | PB14 | R6/R9 voltage divider from BAT+ |
| TEMP_SENSE | PB13 | Temperature sensor (thermistor or IC output) |
| CHARGE_SENSE | PC4 | TP4056 CHRG status (open-drain, needs pull-up) |
| STANDBY_SENSE | PC5 | Standby detection |
| VBUS_SENSE | PC7 | USB VBUS (through resistor divider) |

### 6.10 User Interface

#### Encoders

Encoder RC filter values (from schematic):

| Filter | R | C | MCU Pins |
|---|---|---|---|
| ENC_1 A/B | 33 kΩ | 10 nF | PA1 (A), PA2 (B) |
| ENC_1 SW | 68 kΩ | 100 nF | PA0 |
| ENC_2 A/B | 33 kΩ | 10 nF | PC2 (A), PC3 (B) |
| ENC_2 SW | 68 kΩ | 100 nF | PC1 |

All encoder inputs are active-low. Configure GPIO as input with internal or external pull-up.  
The RC filters provide hardware debounce; add ≥ 5 ms software debounce in firmware.

#### LEDs

| Net | MCU Pin |
|-----|---|
| LED_STATUS | PA5 |
| LED_PWR | PA6 |

#### Buzzer

BZ1 (piezo) driven at 5 V through 74AHCT244 (U8):  
PB12 (3.3 V PWM) → U8 input → `BUZZER_5V` net → BZ1.  
Use timer PWM on PB12 at the buzzer's resonant frequency (typically 2–4 kHz).

---

## 7. Net Glossary

| Net Name | Type | Description |
|---|---|---|
| `3V3` | Power | 3.3 V main rail (U2 LDO) |
| `3V3_Sensors` | Power | 3.3 V sensor rail (U4 LDO) |
| `5V0` | Power | 5.0 V boost output (U5) |
| `BAT+` | Power | Battery positive |
| `BAT-` | Power | Battery negative (GND) |
| `VBUS` | Power | USB VBUS (5 V from host) |
| `BUZZER` | Signal | MCU buzzer drive (3.3 V logic) |
| `BUZZER_5V` | Signal | Buffered buzzer drive (5 V, U8 output) |
| `BLE_UART_MCU_TO_BLE` | Signal | UART TX from MCU to RN4871 |
| `BLE_UART_BLE_TO_MCU` | Signal | UART RX from RN4871 to MCU |
| `~{BLE_RST}` | Signal | RN4871 hardware reset (active-low, MCU output) |
| `BLE_P0_2` … `BLE_P3_6` | Signal | RN4871 GPIO lines |
| `SCL3300_SCK` | Signal | SPI clock to SCL3300 |
| `SCL3300_MOSI` | Signal | SPI MOSI to SCL3300 |
| `SCL3300_MISO` | Signal | SPI MISO from SCL3300 |
| `SCL3300_CS` | Signal | SPI CS for SCL3300 (active-low) |
| `PCAP04_1_SCL` | Signal | I2C SCL for PCAP04 #1 |
| `PCAP04_1_SDA` | Signal | I2C SDA for PCAP04 #1 |
| `PCAP04_1_INT` | Signal | Interrupt from PCAP04 #1 |
| `PCAP04_1_P2` | Signal | PCAP04 #1 measurement port P2 |
| `PCAP04_1_P3` | Signal | PCAP04 #1 measurement port P3 |
| `PCAP04_2_SCL` | Signal | I2C SCL for PCAP04 #2 |
| `PCAP04_2_SDA` | Signal | I2C SDA for PCAP04 #2 |
| `PCAP04_2_INT` | Signal | Interrupt from PCAP04 #2 |
| `PCAP04_2_P2` | Signal | PCAP04 #2 measurement port P2 |
| `PCAP04_2_P3` | Signal | PCAP04 #2 measurement port P3 |
| `EEPROM_SCL` | Signal | I2C SCL for EEPROM |
| `EEPROM_SDA` | Signal | I2C SDA for EEPROM |
| `DISP_SCK` | Signal | Display SPI clock |
| `DISP_MOSI` | Signal | Display SPI data |
| `DISP_CS` | Signal | Display SPI chip select |
| `DISP_VCOM` | Signal | Display VCOM toggle |
| `DISP_ON` | Signal | Display power enable |
| `ENC_1A` | Signal | Encoder 1 channel A (active-low) |
| `ENC_1B` | Signal | Encoder 1 channel B (active-low) |
| `~{ENC_1SW}` | Signal | Encoder 1 push-button (active-low) |
| `ENC_2A` | Signal | Encoder 2 channel A (active-low) |
| `ENC_2B` | Signal | Encoder 2 channel B (active-low) |
| `ENC_2SW` | Signal | Encoder 2 push-button (active-low) |
| `LED_STATUS` | Signal | Status LED drive |
| `LED_PWR` | Signal | Power LED drive |
| `BATTERY_SENSE` | Signal | Battery voltage ADC input |
| `TEMP_SENSE` | Signal | Temperature ADC input |
| `CHARGE_SENSE` | Signal | Charger status input |
| `~{CHARGE_EN}` | Signal | Charger enable (active-low MCU output) |
| `STANDBY_SENSE` | Signal | Standby condition input |
| `VBUS_SENSE` | Signal | USB VBUS detection |
| `5V_EN` | Signal | 5 V boost enable (active-high) |
| `3V3_EN` | Signal | 3.3 V main LDO enable (active-high) |
| `USB_D+` | Signal | USB FS D+ |
| `USB_D-` | Signal | USB FS D− |
| `SWDIO` | Signal | SWD data (J4 debug header) |
| `SWCLK` | Signal | SWD clock (J4 debug header) |
| `SWO` | Signal | Serial Wire Output (J4, not functional on Cortex-M0+) |
| `~{RST}` | Signal | External reset from J4 → PC15 |
| `DEBUG_UART_MCU_TO_PC` | Signal | Debug UART TX (MCU→PC via J4) |
| `DEBUG_UART_PC_TO_MCU` | Signal | Debug UART RX (PC→MCU via J4) |
| `PWR_ON` | Signal | Power-on latch (power sheet) |

---

## 8. Open Items / Firmware Notes

1. **SWD vs PCAP04_1_P2/P3 conflict (PA13/PA14):** The standard SWD pins PA13/PA14 are used for PCAP04_1_P3/P2. Disable these GPIOs before connecting STLINK. Continuous background debug is not possible while PCAP04_1 P2/P3 are actively driven.

2. **~{RST} on PC15 / RTC crystal conflict:** PC15 carries the `~{RST}` signal from J4. PC14/PC15 are also the OSC32_IN/OUT pins used by RTC crystal Y1. If Y1 is fitted and the RTC oscillator is enabled in hardware, PCAP04_2_SCL (PC14) and ~{RST} (PC15) will conflict with the crystal. Configure RTC to use the internal LSI oscillator if PCAP04 #2 is required, and verify the reset scheme with the hardware designer.

3. **USB pin mapping (PA9/PC6):** Primary USB pins on STM32G0B1 are PA11/PA12. Confirm that STM32G0B1 supports USB remapping to PA9 (D+) and PC6 (D−) before implementing the USB driver.

4. **Display SPI (PB0/PB10/PB11):** PB0 (MOSI) and PB10/PB11 (SCK/CS) span multiple SPI peripherals. Check the AF table or use bit-banged SPI.

5. **VCOM:** Toggle DISP_VCOM (PB1) at ≥ 1 Hz continuously. Failure to toggle will damage the LS027B7DH01 display. Implement via timer interrupt or PWM.

6. **Buzzer frequency:** Drive PB12 with PWM at the resonant frequency of BZ1. The 74AHCT244 (U8) level-shifts to 5 V. Check U8 output current against buzzer impedance.

7. **Encoder debounce:** Hardware RC filters present (33 kΩ + 10 nF for A/B, 68 kΩ + 100 nF for SW). Add ≥ 5 ms software debounce in addition.

8. **BLE UART:** RN4871 default 115200 baud, 8N1 on USART2 (PD5 RX, PD6 TX). RN4871 GPIO lines (P0_2–P3_6) function per RN4871 firmware configuration.

9. **EEPROM I2C address:** Depends on address pins A0/A1/A2 configuration. Check connectors.kicad_sch or power.kicad_sch for pull-up/down connections. Default AT24Cxx base address: 0x50.

10. **NRST pin (pin 12):** The physical NRST pin has no global label in the schematic. Verify in the power or connectors sheet that it is connected to a decoupling capacitor to GND (standard practice) and not floating.

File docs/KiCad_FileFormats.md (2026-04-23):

# KiCad 10 File Format Reference — Practical Implementation Notes

**Purpose:** Hands-on reference for programmatic reading/writing of KiCad 10 files. Complements `KiCad_SchematicsGuide.md` (design best practices) with format details and pitfalls learned during implementation.  
**Target:** KiCad 10, file format version `20250114`.

---

## 1. File Overview

A KiCad project consists of these files:

| File | Format | Purpose |
|---|---|---|
| `*.kicad_pro` | JSON | Project settings (net classes, board defaults, library pins) |
| `*.kicad_sch` | S-expression | Schematic sheet (one per sheet in hierarchy) |
| `sym-lib-table` | S-expression | Symbol library lookup table (project-local) |
| `fp-lib-table` | S-expression | Footprint library lookup table (project-local) |
| `*.kicad_sym` | S-expression | Symbol library (one or more symbols per file) |
| `*.kicad_pcb` | S-expression | PCB layout (not covered here) |

---

## 2. S-Expression Format Basics

KiCad uses a Lisp-like S-expression syntax. Key rules:

- Parenthesized lists: `(keyword arg1 arg2 ...)`
- Strings with special chars are quoted: `(property "Value" "100nF")`
- Numbers are unquoted: `(at 25.4 50.8 0)`
- UUIDs are quoted strings: `(uuid "a1b2c3d4-...")`
- Indentation uses tabs in KiCad-generated files (spaces also accepted)
- No trailing commas, no separators between elements

### Parsing Gotcha
When extracting a symbol from a `.kicad_sym` file by text search, use plain string matching (`str.find()`), **not** `re.escape()` followed by `str.find()`. The `re.escape()` function adds backslashes (e.g., `DMG2305UX\-13`) that break literal string searching. Either use raw `str.find()` or use actual regex with `re.search()`.

---

## 3. Symbol Library Files (.kicad_sym)

### Structure
```
(kicad_symbol_lib
  (version 20211014)
  (generator "...")

  (symbol "SYMBOL_NAME"
    (in_bom yes)
    (on_board yes)
    (property "Reference" "U" (at 0 7.62 0) (effects ...))
    (property "Value" "SYMBOL_NAME" (at 0 -7.62 0) (effects ...))
    (property "Footprint" "Package:Footprint" (at ...) (effects ... hide))
    (property "Datasheet" "url" (at ...) (effects ... hide))
    ...additional properties...

    (symbol "SYMBOL_NAME_0_1"      ; Graphics sub-symbol (unit 0 = common to all units)
      (rectangle (start ...) (end ...) (stroke ...) (fill ...))
      (pin TYPE STYLE
        (at X Y ROT)
        (length L)
        (name "PIN_NAME" (effects ...))
        (number "PIN_NUM" (effects ...))
      )
      ...more pins...
    )
    (symbol "SYMBOL_NAME_1_1"      ; Unit 1 additional graphics (if multi-unit)
      ...
    )
  )
)
```

### Sub-Symbol Naming Convention
- `SYMBOL_NAME_0_1` — graphics common to all units (unit 0), "de Morgan" variant 1
- `SYMBOL_NAME_1_1` — unit 1 specific graphics, variant 1
- `SYMBOL_NAME_2_1` — unit 2 specific graphics, variant 1
- For single-unit symbols, pins are typically in `_0_1` (or sometimes `_1_1`)
- Both `_0_1` and `_1_1` are children of the parent `SYMBOL_NAME` symbol

### Pin Definition
```
(pin TYPE STYLE
  (at X Y ROTATION)    ; Connection point in symbol coords (Y-up)
  (length LENGTH)      ; How far the pin line extends from connection point
  (name "NAME" ...)
  (number "NUM" ...)
)
```

**Pin types:** `input`, `output`, `bidirectional`, `passive`, `power_in`, `power_out`, `unspecified`, `free`, `open_collector`, `open_emitter`, `no_connect`, `tri_state`

**Pin styles:** `line`, `inverted`, `clock`, `inverted_clock`, `input_low`, `clock_low`, `output_low`, `edge_clock_high`, `non_logic`

**Pin rotation** (in symbol coords, Y-up):
| Rotation | Pin line extends | Connection point is on |
|---|---|---|
| 0° | RIGHT from body | LEFT side (wire connects on left) |
| 90° | UP from body | BOTTOM side |
| 180° | LEFT from body | RIGHT side (wire connects on right) |
| 270° | DOWN from body | TOP side |

The `(at X Y)` gives the **wire connection endpoint** — this is where you must place wires in the schematic.

### Extracting Pin Positions
To get the wire connection point for each pin, parse the `(pin ... (at X Y ROT) ...)` inside the sub-symbols. The `(at X Y)` value is directly the connection point in symbol-local coordinates.

Example from DW01A:
```
(pin unspecified line
  (at -12.70 2.54 0)    ; Pin 1 "OD" — connection at (-12.70, 2.54)
  (length 5.08)
  (name "OD" ...)
  (number "1" ...)
)
```

---

## 4. JLCPCB / EasyEDA Converted Libraries

Libraries generated by `easyeda2kicad.py` (from JLCPCB/LCSC) have these characteristics:

### Symbol Name Convention
- **Slashes `/` are replaced with underscores `_`** in symbol names
  - Manufacturer part: `LP5907MFX-3.3/NOPB` → Symbol name: `LP5907MFX-3.3_NOPB`
  - `RN4871-I/RM128` → `RN4871-I_RM128`
  - `24LC256-I/ST` → `24LC256-I_ST`
- Hyphens `-` are preserved: `DMG2305UX-13` stays `DMG2305UX-13`
- LCSC part numbers may be appended: `TP4056_C382139`

### Properties
These libraries include extra properties not in standard KiCad libraries:
- `"LCSC Part"` — JLCPCB/LCSC part number (e.g., `"C85680"`)
- `"MPN"` — Manufacturer Part Number
- `"Manufacturer"` — Manufacturer name (often `"null"` for generics)
- Properties use `(id N)` identifiers (legacy format from older KiCad versions)

### Pin Layout
- Pins use **physical package order**, not functional grouping
- All pins typically typed as `unspecified` (not `input`/`output`/`power_in`)
- Pin arrangement reflects the IC's physical pinout, not schematic conventions

### Footprint References
- Footprints reference the library's own namespace: `"DW01A:SOT-23-6_L2.9-W1.6-P0.95-LS2.8-BL"`
- These won't resolve unless the matching `.kicad_mod` footprint library is also installed
- For JLCPCB assembly, the footprint name matters less than the LCSC part number

### Library Version
- Use `(version 20211014)` — older than KiCad 10's native format
- KiCad 10 reads these without issue; it silently upgrades on re-save

---

## 5. Schematic Files (.kicad_sch)

### Top-Level Structure
```
(kicad_sch
  (version 20250114)
  (generator "eeschema")
  (generator_version "10.0")
  (uuid "ROOT_UUID")
  (paper "A3")                    ; or "A4"
  (title_block
    (title "Sheet Title")
    (date "2026-04-14")
    (rev "0.1")
  )
  (lib_symbols
    ; ALL symbol definitions used on this sheet, embedded in full
  )
  ; Content elements in order:
  (junction ...)                   ; Wire junction dots
  (wire ...)                       ; Wire segments
  (text ...)                       ; Freestanding text annotations
  (label ...)                      ; Local net labels
  (global_label ...)               ; Global net labels
  (symbol ...)                     ; Component instances
  (sheet ...)                      ; Sub-sheet references (root sheet only)
  (sheet_instances ...)            ; Page number assignments
  (embedded_fonts no)
)
```

### Critical Rule: lib_symbols Must Embed Everything
Every symbol used on a sheet must have its **complete definition** embedded in `(lib_symbols ...)`. This includes:
- Component symbols (ICs, passives)
- Power symbols (GND, +3V3, etc.)
- The definitions are copies — modifying them here doesn't change the source library

When embedding a local library symbol, rename it to avoid conflicts:
```python
# Rename "DW01A" to "local_DW01A:DW01A" in the embedded definition
sym_text = sym_text.replace(
    '(symbol "DW01A"',
    '(symbol "local_DW01A:DW01A"'
)
```
This must also rename all sub-symbols: `DW01A_0_1` → `local_DW01A:DW01A_0_1`.

### Symbol Instance (Component Placement)
```
(symbol
  (lib_id "local_TP4056:TP4056_C382139")   ; References embedded lib_symbol
  (at 175 72 0)                              ; X Y ROTATION in mm
  (unit 1)                                   ; Which unit (for multi-unit symbols)
  (exclude_from_sim no)
  (in_bom yes)
  (on_board yes)
  (dnp no)                                   ; Do Not Populate
  (uuid "UNIQUE_UUID")
  (property "Reference" "U3"
    (at 177.54 69.46 0)
    (effects (font (size 1.27 1.27)) (justify left))
  )
  (property "Value" "TP4056"
    (at 177.54 66.92 0)
    (effects (font (size 1.27 1.27)) (justify left))
  )
  (property "Footprint" "Package_SO:SOP-8_3.9x4.9mm_P1.27mm"
    (at 175 72 0)
    (effects (font (size 1.27 1.27)) (hide yes))
  )
  (property "Datasheet" "~"
    (at 175 72 0)
    (effects (font (size 1.27 1.27)) (hide yes))
  )
  (property "Description" ""
    (at 175 72 0)
    (effects (font (size 1.27 1.27)) (hide yes))
  )
  (instances
    (project "ProjectName"
      (path "/ROOT_UUID"                     ; or "/ROOT_UUID/SHEET_UUID"
        (reference "U3")
        (unit 1)
      )
    )
  )
)
```

### Power Symbol Instances
Power symbols (GND, +3V3, etc.) are special:
- They are **both** a `lib_symbols` definition **and** a `symbol` instance
- Their `lib_id` uses the `power:` prefix: `"power:GND"`, `"power:+3V3"`
- The `(power)` flag in the lib_symbol definition makes the net implicitly global
- Reference designators use `#PWR` prefix and should be hidden
- Each placed power symbol gets a unique `#PWR0xx` reference

### Wire Segments
```
(wire
  (pts (xy X1 Y1) (xy X2 Y2))
  (stroke (width 0) (type default))
  (uuid "UNIQUE_UUID")
)
```
- Wires are always point-to-point segments (two endpoints)
- Only orthogonal wires (horizontal or vertical) — no diagonals
- Wire endpoints must exactly match pin connection points for electrical connection
- A 0.01mm offset will cause an unconnected pin error

### Junction Dots
```
(junction
  (at X Y)
  (diameter 0)
  (color 0 0 0 0)
  (uuid "UNIQUE_UUID")
)
```
Required wherever 3+ wires meet at a point. Without a junction, KiCad treats crossing wires as unconnected.

### Labels
```
; Local net label (single sheet scope)
(label "NET_NAME"
  (at X Y ROTATION)
  (effects (font (size 1.27 1.27)) (justify left bottom))
  (uuid "UNIQUE_UUID")
)

; Global label (all sheets)
(global_label "NET_NAME"
  (shape input)                    ; input, output, bidirectional, tri_state, passive
  (at X Y ROTATION)
  (effects (font (size 1.27 1.27)) (justify left))
  (uuid "UNIQUE_UUID")
  (property "Intersheets" ""
    (at X Y 0)
    (effects (font (size 1.27 1.27)) (hide yes))
  )
)
```

**Label rotation:**
| Rotation | Text reads | Wire connects from |
|---|---|---|
| 0° | Left to right | Left side |
| 180° | Left to right | Right side |
| 90° | Bottom to top | Bottom side |
| 270° | Top to bottom | Top side |

For a label at 0°, the connection point is on the **left** — attach wire to the label's `(at X Y)` position from the left.  
For a label at 180°, the connection point is on the **right** — attach wire to the label's position from the right.

### Freestanding Text
```
(text "Annotation text"
  (at X Y ROTATION)
  (effects (font (size 2.54 2.54)) (justify left bottom))
  (uuid "UNIQUE_UUID")
)
```

### Dashed Rectangle (Section Border)
Drawn as a `(polyline ...)` inside a `(symbol ...)` wrapper — but for schematic annotations, use raw polyline with dashed stroke. In practice, four `(wire ...)` segments with dashed type don't exist — instead use a `(polyline ...)` at the schematic level (KiCad 10):
```
(polyline
  (pts (xy X1 Y1) (xy X2 Y1) (xy X2 Y2) (xy X1 Y2) (xy X1 Y1))
  (stroke (width 0.254) (type dash))
  (uuid "UNIQUE_UUID")
)
```
Note: Older KiCad versions used `(rectangle ...)` at the schematic level; KiCad 10 uses `(polyline ...)` for free-form drawing.

---

## 6. Coordinate Systems

### The Two Coordinate Systems (Critical)

| Context | Y-axis | Used in |
|---|---|---|
| Symbol definition (`.kicad_sym`) | **Y-up** (math convention) | Pin positions, body rectangle, graphics |
| Schematic file (`.kicad_sch`) | **Y-down** (screen convention) | Symbol placement, wires, labels |

### Pin Position Transform

Given:
- Symbol placed at schematic position `(sx, sy)` with rotation `R`
- Pin defined at symbol-local position `(px, py)` (Y-up coordinates)

The **wire connection point** in schematic coordinates (Y-down) is:

```
R =   0°:  wire_x = sx + px,  wire_y = sy - py
R =  90°:  wire_x = sx - py,  wire_y = sy - px
R = 180°:  wire_x = sx - px,  wire_y = sy + py
R = 270°:  wire_x = sx + py,  wire_y = sy + px
```

The Y-flip (`sy - py` at 0°) accounts for the coordinate system difference. At 90°, the rotation matrix and Y-flip combine.

### Worked Example
LP5907 symbol: pin 1 (IN) at local `(-7.62, 2.54)`, symbol placed at schematic `(260, 55)`, rotation 0°:
```
wire_x = 260 + (-7.62) = 252.38
wire_y = 55 - 2.54 = 52.46
```
Wire must connect to `(252.38, 52.46)` in the schematic.

---

## 7. Hierarchical Sheets

### Root Sheet
The root `.kicad_sch` contains `(sheet ...)` elements referencing sub-sheets:
```
(sheet
  (at 30 60)                      ; Position of the sheet box on root page
  (size 65 30)                    ; Width and height of the sheet box
  (exclude_from_sim no)
  (in_bom yes)
  (on_board yes)
  (dnp no)
  (stroke (width 0) (type solid))
  (fill (color 0 0 0 0.0000))
  (uuid "SHEET_UUID")             ; This UUID is used in instance paths
  (property "Sheetname" "Power Supply"
    (at 30 59.238 0)
    (effects (font (size 1.524 1.524)) (justify left bottom))
  )
  (property "Sheetfile" "power.kicad_sch"
    (at 30 90.762 0)
    (effects (font (size 1.524 1.524)) (justify left top))
  )
  (instances
    (project "ProjectName"
      (path "/ROOT_UUID"
        (page "2")
      )
    )
  )
)
```

### sheet_instances Block
The root sheet must also contain a `(sheet_instances ...)` block listing all sheet paths and their page numbers:
```
(sheet_instances
  (path "/"
    (page "1")
  )
  (path "/ROOT_UUID/SHEET1_UUID"
    (page "2")
  )
  (path "/ROOT_UUID/SHEET2_UUID"
    (page "3")
  )
)
```

### Instance Paths
Symbol instances on sub-sheets use the path format `"/ROOT_UUID/SHEET_UUID"`:
```
(instances
  (project "ProjectName"
    (path "/ROOT_UUID/SHEET_UUID"
      (reference "U3")
      (unit 1)
    )
  )
)
```

The `SHEET_UUID` must match the `(uuid ...)` in the root sheet's `(sheet ...)` element. If these don't match, KiCad won't assign correct reference designators.

### Inter-Sheet Connectivity
- **Global labels** connect nets across all sheets — same name = same net
- **Power symbols** are implicitly global — `GND` on any sheet connects to `GND` everywhere
- **Hierarchical pins** on sheet boxes are NOT needed when using global labels (they're for explicit hierarchical designs)

---

## 8. Project File (.kicad_pro)

Minimal working `.kicad_pro`:
```json
{
  "board": {
    "design_settings": {
      "defaults": {
        "board_outline_line_width": 0.1,
        "copper_line_width": 0.2,
        "copper_text_size_h": 1.5,
        "copper_text_size_v": 1.5,
        "copper_text_thickness": 0.3,
        "silk_line_width": 0.15,
        "silk_text_size_h": 1.0,
        "silk_text_size_v": 1.0
      }
    }
  },
  "libraries": {
    "pinned_footprint_libs": [],
    "pinned_symbol_libs": []
  },
  "meta": {
    "filename": "ProjectName.kicad_pro",
    "version": 3
  },
  "net_settings": {
    "classes": [
      {
        "bus_width": 12,
        "clearance": 0.2,
        "name": "Default",
        "track_width": 0.2,
        "via_diameter": 0.6,
        "via_drill": 0.3
      }
    ]
  },
  "schematic": {
    "drawing": {
      "default_line_thickness": 6.0,
      "default_text_size": 50.0,
      "intersheets_ref_show": true
    }
  }
}
```

---

## 9. Library Tables

### sym-lib-table
```
(sym_lib_table
  (version 7)
  (lib (name "local_DW01A")(type "KiCad")(uri "${KIPRJMOD}/../Libraries/KiCad/DW01A.kicad_sym")(options "")(descr ""))
  ...
)
```
- `${KIPRJMOD}` expands to the directory containing `.kicad_pro`
- Use relative paths via `${KIPRJMOD}` for portability
- `type` is always `"KiCad"` for `.kicad_sym` files

### fp-lib-table
```
(fp_lib_table
  (version 7)
  (lib (name "local_DW01A")(type "KiCad")(uri "${KIPRJMOD}/../Libraries/KiCad/DW01A.pretty")(options "")(descr ""))
  ...
)
```
- `.pretty` is a directory containing `.kicad_mod` files
- JLCPCB-converted libraries create one `.pretty` directory per component

---

## 10. Inline Symbol Definitions (No External Library Needed)

For common passives and power symbols, define them inline to avoid dependency on KiCad's built-in library paths (which vary by OS and installation).

### Resistor (Minimal)
```
(symbol "Device:R"
  (pin_names (offset 0))
  (exclude_from_sim no)
  (in_bom yes)
  (on_board yes)
  (property "Reference" "R" (at 2.032 0 90) (effects (font (size 1.27 1.27))))
  (property "Value" "R" (at -2.032 0 90) (effects (font (size 1.27 1.27))))
  (property "Footprint" "" (at 0 0 0) (effects (font (size 1.27 1.27)) (hide yes)))
  (property "Datasheet" "~" (at 0 0 0) (effects (font (size 1.27 1.27)) (hide yes)))
  (property "Description" "Resistor" (at 0 0 0) (effects (font (size 1.27 1.27)) (hide yes)))
  (symbol "R_0_1"
    (rectangle (start -1.016 3.81) (end 1.016 -3.81)
      (stroke (width 0) (type default)) (fill (type none)))
  )
  (symbol "R_1_1"
    (pin passive line (at 0 5.08 270) (length 1.27) (name "1" ...) (number "1" ...))
    (pin passive line (at 0 -5.08 90) (length 1.27) (name "2" ...) (number "2" ...))
  )
)
```
Pin 1 at `(0, 5.08)` → top, pin 2 at `(0, -5.08)` → bottom in symbol coords.

### Capacitor (Minimal)
Same structure as resistor with different body graphic (two parallel lines instead of rectangle).

### GND Power Symbol
```
(symbol "power:GND"
  (power)                          ; ← This flag makes it a power symbol
  (pin_names (offset 0))
  ...
  (symbol "GND_0_1"
    (polyline (pts (xy 0 0) (xy 0 -1.27) (xy 1.27 -1.27) (xy 0 -2.54) (xy -1.27 -1.27) (xy 0 -1.27))
      (stroke (width 0) (type default)) (fill (type none)))
  )
  (symbol "GND_1_1"
    (pin power_in line (at 0 0 270) (length 0)
      (name "GND" ...) (number "1" ...))
  )
)
```
- The `(power)` flag is essential — without it, the symbol won't create an implicit global net
- Pin type must be `power_in`
- Pin length is 0 — the connection point is at the symbol origin

---

## 11. UUID Requirements

Every element needs a unique UUID v4. KiCad will regenerate conflicting UUIDs on load, but this triggers warnings. Generate fresh UUIDs for:
- The schematic file itself (`(uuid "...")` at top level)
- Every `(symbol ...)` instance
- Every `(wire ...)` segment
- Every `(junction ...)`, `(label ...)`, `(global_label ...)`
- Every `(text ...)` and `(polyline ...)`
- Every `(sheet ...)` reference
- The instance path entries

In Python: `str(uuid.uuid4())` generates valid UUIDs.

---

## 12. Common Pitfalls

| Pitfall | Symptom | Fix |
|---|---|-----|
| Pin endpoint off 1.27mm grid | Unconnected pin ERC errors | Ensure all pin `(at)` values are multiples of 1.27 |
| Wire doesn't exactly reach pin | "Wire not connected" | Use `pin()` transform function, don't estimate coords |
| `re.escape()` with `str.find()` | Symbols not found in library | Don't escape for literal string search |
| `/` in JLCPCB symbol names | Symbol extraction fails | Use `_` instead of `/` when referencing |
| Missing `lib_symbols` entry | Symbol appears as `?` box | Embed every used symbol in `(lib_symbols ...)` |
| Missing `(power)` flag | Power net not globally connected | Include `(power)` in power symbol definitions |
| Wrong instance path | Reference designators reset to `U?` | Path must be `/ROOT_UUID/SHEET_UUID` |
| `sheet_instances` missing entries | Page numbers show as `?` | List all sheets including root `/` |
| Duplicate UUIDs | Warning on load, possible corruption | Generate fresh UUID for every element |
| Sub-symbols not renamed | Symbol partially loads | When renaming `FOO` → `LIB:FOO`, also rename `FOO_0_1` → `LIB:FOO_0_1` |

---

## 13. Automating Pin Extraction

To avoid manually transcribing pin positions, parse `.kicad_sym` files:

```python
import re

def extract_pins(lib_path, symbol_name):
    """Extract pin {number: (x, y)} from a .kicad_sym file."""
    content = lib_path.read_text(encoding="utf-8")
    pins = {}
    # Find all pins in the symbol (including sub-symbols)
    pin_pattern = re.compile(
        r'\(pin\s+\w+\s+\w+\s*\n?\s*'
        r'\(at\s+([-\d.]+)\s+([-\d.]+)\s+\d+\)\s*\n?\s*'
        r'\(length\s+[-\d.]+\)\s*\n?\s*'
        r'\(name\s+"[^"]*"[^)]*\)\s*\n?\s*'
        r'\(number\s+"(\d+)"',
        re.MULTILINE
    )
    for m in pin_pattern.finditer(content):
        x, y, num = float(m.group(1)), float(m.group(2)), m.group(3)
        pins[num] = (x, y)
    return pins
```

This returns the pin connection points in symbol-local coordinates (Y-up). Apply the transform from Section 6 to get schematic coordinates.

---

## References

- [KiCad Schematic File Format (official docs)](https://dev-docs.kicad.org/en/file-formats/sexpr-schematic/)
- [KiCad Symbol Library File Format](https://dev-docs.kicad.org/en/file-formats/sexpr-symbol-lib/)
- [easyeda2kicad converter](https://github.com/uPesy/easyeda2kicad.py)
- Companion document: `KiCad_SchematicsGuide.md` (design best practices)

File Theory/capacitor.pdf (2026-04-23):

## Capacitance of a Tilted Circular Parallel-Plate Capacitor with Application to Precision Tilt Measurement

## Contents

1 Problem Statement | 1
2 Variable Definitions and Conventions | 2
3 Geometry and Physical Limits | 2
4 Exact Capacitance | 2
5 Approximate Formulae | 4
6 Inversion: Solving for α | 4
7 Numerical Example and Graphical Comparison | 5
8 Summary | 6

## 1 Problem Statement

Precision tilt sensors based on capacitive measurement exploit the sensitivity of capacitance to small changes in the air gap between two conducting plates. In a practical instrument, a pendulum of length L suspends one plate so that its centre-to-centre distance to a fixed reference plate varies with the tilt angle α. When the instrument is tilted, the two plates are no longer parallel: they subtend the same angle α.

The goal of this note is to derive a closed-form expression for the capacitance as a function of the tilt angle, compare it with two progressively cruder approximations, and invert each expression to obtain α as a function of the measured capacitance.
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

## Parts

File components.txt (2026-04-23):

General remark:
- Use ceramics capacitors generously, every power pin of every IC needs at least a 100nF capacitor located closely to it.

Power supply:
- Single cell LiPo, capacity TBD
- Dual voltage: 5V for display, 3.3 volts for everything else
- 5V converter to be designed. Possibly charge pump instead of switchmode boost converter.
- Charging over USB, controlled by TP4056 (1A Standalone Linear Li-lon Battery Charger with Thermal Regulation in SOP-8)
- Protection by DW01A in SOT-23-6 package (one cell li-ion / LiPo protection IC)
- Low-dropout linear regulator: Texas LP5907, fixed 3.3V output, SOT-23-5 package (low-noise)
  - Two instances: one for the main 3.3V rail, one dedicated to the capacitive sensor daughterboards (PCAP04) to isolate them from noise
  - EN pin is active-high; MCU drives it active-high (high = LDO on, low = LDO off)
- Cut-off volatage controlled by PIC (PIC uses internal voltage reference to measure battery voltage). Cut-off voltage 3.5 - 3.6V to give a bit of headroom for LDO
- Microcontroller pins:
	- 1 x Voltage Sense (analog input)
	- 1 x Main LDO enable (digital output, active-high)
	- 1 x Sensor LDO enable (digital output, active-high)
	- 1 x Charge sense (digital input)

Microcontroller:
- PIC32MX470F512H (64 pin TQFP)
- 8MHz crysal with PLL configured for 48MHz USB clock and 80MHz core clock

Programming header:
- Microchip ICSP interface
- 100mil header with pinout matching PicKit programmer
- MCLR / VDD / GND / PGD / PGC / AUX

Display:
- Sharp Memory LCD, 2.7" LS027B7DH01, 400×240 resolution
- Needs 5V supply
- Logic level shifting via 74AHCT1G125 or similar
- SPI interface 
- Microcontroller pins:
	- 1x SCLK (digital output)
	- 1x MOSI (digital output)
	- No MISO?
	- 1x Chip Select (digital output)
	- 1x Display ON (digital output)
	- 1x VCOM (digital output)

Status LEDs:
- 1x power on
- 1x status
- Microcontroller pins: 2x digital output

Input device:
- 2x Rotary encoder with push button
- Outputs are RC-filtered and run through a 74HC14 for proper hardware debouncing
- Push button inputs use pull-up resistors (active-low: normally high, low when pressed)
- Quadrature outputs use pull-up resistors
- Microcontroller pins:
	- 6x inputs (digital input connected to interrupt-on-change)

USB:
- Directly implemented by PIC
- USB-C connector
- For charging, HID communication and MSD bootloader
- Microcontroller pins:
	- USB+ (dedicated USB pin)
	- USB- (dedicated USB pin)
	- USB Sense (digital input)

Temperature sensor:
- For ambient temperature sensing. Rather have but not need than need but not have.
- Texas LM35 in SOT-23 package
- Microcontroller pins:
	- 1x Temperature Sense (analog input)

3-axis inclinometer:
- SCL3300 on separate, yet to be developped PCB
- Connect via same 6-pin FFC as precision inclinometer
- SPI interface
- Microcontroller pins:
	- Chip select (digital output)
	- MOSI (digital output)
	- MISO (digital input)
	- SCK (digital output)

Precision inclinometer:
- 2x  PCAP04, each on a dedicated board
- On the same I2C bus, with different I2C addresses
- Boards already exists, connects via 6-pin FFC Flat Flexible Cable, spacing to be clarified
- Pinout: SDA, SCL, GND, Reset, +3.3V, Interrupt

Flash memory:
- Standard SPI interface
-  SCL, MISO, MOSI, ChipSelect

EEPROM:
- External EEPROM 24LC256
- I2C inteface

Bluetooth Low Energy (BLE)
- RNBD451 (upgrade to RN4871)
- Interface:
	- UART_RX (PIC TX)
	- UART_TX (PIC RX)
	- Reset (GPIO output)
	- RX_IND or status pin (GPIO input)

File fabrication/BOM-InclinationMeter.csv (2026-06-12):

Comment | Designator | Footprint | LCSC Part #
CPT-9019A-SMT-TR | BZ1 | sldrnrd:CPT-9019A | C20181991
1u | C1,C6,C16 | sldrnrd:C_0805 | C28323
100n | C2,C3,C8,C11,C12,C13,C17,C18,C23,C26,C27,C28,C30,C32,C34,C35,C36,C37,C38,C39,C40,C41,C42,C43 | sldrnrd:C_0603 | C14663
10u | C4,C5,C7,C9,C10,C14 | sldrnrd:C_1206 | C70462
2u2 | C15,C29 | sldrnrd:C_0805 | C126589
15p | C19,C20 | sldrnrd:C_0603 | C1644
33p | C21,C22 | sldrnrd:C_0603 | C1663
10n | C24,C25,C31,C33 | sldrnrd:C_0603 | C57112
LED_Red_0603 | D1 | sldrnrd:LED_0603 | C2286
LED_Green_0603 | D2,D3 | sldrnrd:LED_0603 | C72043
LED_Yellow_0603 | D4 | sldrnrd:LED_0603 | C2287
LS027B7DH01 | DS1 | sldrnrd:Display_LS027B7DH01 | C17492463
JST_PH_2.0mm_1x02 | J1 | sldrnrd:JST_PH_2.0mm_1x02 | C131337
USB_C | J2 | sldrnrd:USB_C | C165948
Header_FFC_1.0mm_06 | J3 | sldrnrd:Header_FFC_1.0mm_06 | C72727
Header_50mil_2x07 | J4 | sldrnrd:Header_50mil_2x07 | C5563894
Header_FFC_1.0mm_10 | J5,J6 | sldrnrd:Header_FFC_1.0mm_10 | C52162
JST_PH_2.0mm_1x03 | J7 | sldrnrd:JST_PH_2.0mm_1x03 | C131339
DMG2305UX-13 | Q1,Q3 | sldrnrd:SOT-23-3 | C144153
FS8205A | Q2 | sldrnrd:TSSOP-8 | C14212
AO3400A | Q4,Q5 | sldrnrd:SOT-23-3 | C20917
100k | R1,R8,R28,R31 | sldrnrd:R_0603 | C25803
2k | R2,R26,R37 | sldrnrd:R_0603 | C22975
1k | R3,R6,R7,R10,R11 | sldrnrd:R_0603 | C21190
R_0603 | R4 | sldrnrd:R_0603
33k | R5,R9,R12,R13,R14,R15,R16,R17,R20,R21,R22,R23,R24,R25,R34 | sldrnrd:R_0603 | C4216
5k1 | R18,R19,R27,R29,R32,R33,R35,R36 | sldrnrd:R_0603 | C23186
68k | R30 | sldrnrd:R_0603 | C23231
PEC11R-4215F-S0024 | SW1,SW2 | sldrnrd:RotaryEncoder_PEC11R | C143790
DW01A | U1 | sldrnrd:SOT-23-6 | C85680
LP5907MFX-3.3/NOPB | U2,U4 | sldrnrd:SOT-23-5 | C80670
TP4056 | U3 | sldrnrd:ESOP-8 | C382139
SD6210A | U5 | sldrnrd:SOT-23-6 | C250809
STM32G0B1RET6 | U6 | sldrnrd:LQFP-64 | C2829307
RN4871-I/RM128 | U7 | sldrnrd:RN4871 | C633941
SN74AHCT244DBR | U8 | sldrnrd:SSOP-20 | C2868870
24LC256-I/ST | U9 | sldrnrd:TSSOP-8 | C87823
BME280 | U10 | sldrnrd:LGA-8_2.5x2.5mm_P0.65mm | C92489
SN74HC14PWR | U11 | sldrnrd:TSSOP-14 | C6821
LM35 | U12 | sldrnrd:SOT-23-3 | C9900081740
Q13FC1350000400 | Y1 | sldrnrd:CRYSTAL-3215 | C32346
X50328MSB2GI | Y2 | sldrnrd:CRYSTAL-3225 | C115962

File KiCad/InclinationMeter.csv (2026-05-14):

Reference | Qty | Value | DNP | Exclude from BOM | Exclude from Board | Footprint | Datasheet
BZ1 | 1 | CPT-9019A |  |  |  | sldrnrd:CPT-9019A | ${SLDRNRD_LIB}/datasheets/Audio/CPT-9019A.pdf
C1,C6,C16 | 3 | 1uF |  |  |  | sldrnrd:C_0603
C2,C3,C8,C11,C12,C13,C17,C18,C23,C26,C27,C28,C30,C32,C34,C35,C36,C37,C38,C39,C40 | 21 | 100n |  |  |  | sldrnrd:C_0603
C4,C9,C10,C14 | 4 | 10u |  |  |  | sldrnrd:C_0805
C5,C7 | 2 | 10u |  |  |  | sldrnrd:C_0603
C15,C29 | 2 | 3u3 |  |  |  | sldrnrd:C_0805
C19,C20 | 2 | 12.5p |  |  |  | sldrnrd:C_0603
C21,C22 | 2 | 20p |  |  |  | sldrnrd:C_0603
C24,C25,C31,C33 | 4 | 10n |  |  |  | sldrnrd:C_0603
D1 | 1 | LED_Red_0603 |  |  |  | sldrnrd:LED_0603
D2,D3,D4 | 3 | LED_Green_0603 |  |  |  | sldrnrd:LED_0603
DS1 | 1 | LS027B7DH01 |  |  |  | sldrnrd:Header_FFC_1.5mm_10 | ${SLDRNRD_LIB}/datasheets/Display/LS027B7DH01.pdf
J1 | 1 | JST_PH_2.0mm_1x02 |  |  |  | sldrnrd:JST_PH_2.0mm_1x02 | ${SLDRNRD_LIB}/datasheets/Connector/JST/ePH.pdf
J2 | 1 | USB-C |  |  |  | sldrnrd:USB_C | ${SLDRNRD_LIB}/datasheets/Connector/USB/TYPE-C-31-M-12.pdf
J3 | 1 | Header_FFC_1.0mm_06 |  |  |  | sldrnrd:Header_FFC_1.0mm_06 | ${SLDRNRD_LIB}/datasheets/Connector/FFC/AFA07.pdf
J4 | 1 | Header_50mil_2x07 |  |  |  | sldrnrd:Header_50mil_2x07
J5,J6 | 2 | Header_FFC_1.0mm_10 |  |  |  | sldrnrd:Header_FFC_1.0mm_10 | ${SLDRNRD_LIB}/datasheets/Connector/FFC/AFA07.pdf
Q1,Q3 | 2 | DMG2305UX |  |  |  | sldrnrd:SOT-23-BR
Q2 | 1 | FS8205A |  |  |  | sldrnrd:TSSOP-8
Q4,Q5 | 2 | AO3400A |  |  |  | sldrnrd:SOT-23 | ${SLDRNRD_LIB}/datasheets/Transistor/MosfetN/AO3400A.pdf
R1,R8,R28,R31 | 4 | 100k |  |  |  | sldrnrd:R_0603
R2,R4 | 2 | 2k |  |  |  | sldrnrd:R_0603
R3,R6,R7,R10,R11,R26 | 6 | 1k |  |  |  | sldrnrd:R_0603
R5,R14,R15,R16,R22,R23,R24,R34 | 8 | 33k |  |  |  | sldrnrd:R_0603
R9,R12,R13,R17,R20,R21,R25,R30 | 8 | 68k |  |  |  | sldrnrd:R_0603
R18,R19,R27,R29,R32,R33,R35,R36 | 8 | 5k1 |  |  |  | sldrnrd:R_0603
SW1,SW2 | 2 | PEC11R-4215F-S0024 |  |  |  | sldrnrd:RotaryEncoder_PEC11R | ${SLDRNRD_LIB}/datasheets/InputDevice/RotaryEncoder/PEC11R.pdf
U1 | 1 | DW01A |  |  |  | sldrnrd:SOT-23-6 | ${SLDRNRD_LIB}/datasheets/Power/BatteryManagement/DW01A.pdf
U2,U4 | 2 | LP5907MFX-3.3/NOPB |  |  |  | sldrnrd:SOT-23-5 | ${SLDRNRD_LIB}/datasheets/Power/LinearRegulator/LP5907.pdf
U3 | 1 | TP4056 |  |  |  | sldrnrd:ESOP-8 | ${SLDRNRD_LIB}/datasheets/Power/BatteryManagement/TP4056.pdf
U5 | 1 | SD6210A |  |  |  | sldrnrd:SOT-23-6 | ${SLDRNRD_LIB}/datasheets/Power/ChargePump/SD6210A.pdf
U6 | 1 | STM32G0B1RET6 |  |  |  | sldrnrd:LQFP-64 | ${SLDRNRD_LIB}/datasheets/Microcontroller/STM/STM32G0B1.pdf
U7 | 1 | RN4871-I_RM128 |  |  |  | sldrnrd:RN4871 | ${SLDRNRD_LIB}/datasheets/Wireless/Bluetooth/RN4871.pdf
U8 | 1 | SN74AHCT244DBR |  |  |  | sldrnrd:SSOP-20 | ${SLDRNRD_LIB}/datasheets/Logic/74/SN74AHCT244.pdf
U9 | 1 | 24LC256-I_ST |  |  |  | sldrnrd:TSSOP-8
U10 | 1 | SN74HC14PWR |  |  |  | sldrnrd:TSSOP-14
U11 | 1 | LM35DGS |  |  |  | sldrnrd:SOT-23
Y1 | 1 | 32.768kHz |  |  |  | sldrnrd:CRYSTAL-3215 | ${SLDRNRD_LIB}/datasheets/Crystal/Q13FC1350000400.pdf
Y2 | 1 | 8MHz |  |  |  | sldrnrd:CRYSTAL-3225 | ${SLDRNRD_LIB}/datasheets/Crystal/X50328MSB2GI.pdf

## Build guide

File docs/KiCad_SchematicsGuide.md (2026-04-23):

# KiCad Schematic Best Practices — Reference Guide

**Purpose:** Reference for programmatic generation of clean, professional KiCad schematics.  
**Target:** KiCad 10 (.kicad_sch S-expression format, version 20250114)

---

## 1. Grid and Spacing

| Parameter | Value (mil) | Value (mm) | Usage |
|---|---|---|---|
| Primary grid | 50 | 1.27 | All pins, wires, symbol placement |
| Secondary grid | 25 | 0.635 | Fine text positioning only |
| Never smaller than | 25 | 0.635 | Pins/wires MUST be on 50-mil grid |

- **All pin endpoints and wire endpoints must land on 1.27 mm grid.** KiCad will not detect connections if endpoints are off-grid.
- Minimum clearance between symbol bodies: 5.08 mm (200 mil).
- Recommended spacing between adjacent components: 7.62–10.16 mm (300–400 mil).
- Place components on multiples of 2.54 mm (100 mil) for visual alignment.

---

## 2. Signal Flow Conventions

### Left-to-Right
- **Inputs on the left, outputs on the right.** This is the single most important readability rule.
- Signal flows left → right, matching natural reading direction.
- Feedback paths (power supply feedback, etc.) flow right → left to distinguish from forward paths.

### Vertical Power Convention
- **Higher voltages at the top, ground at the bottom.**
- VCC/VDD/+3V3 power symbols point upward (↑).
- GND power symbols point downward (↓).

### Cross-Sheet Flow
- Place inter-sheet labels at the sheet edges: inputs on the left edge, outputs on the right edge.
- Maintain consistent signal direction across all pages.

---

## 3. Symbol Pin Placement (KLC Rules)

| Pin Type | Position on Symbol |
|---|---|
| Positive power (VCC, VDD, VIN) | Top |
| Ground / Negative power (GND, VSS) | Bottom |
| Input / Control / Logic (EN, RST) | Left |
| Output / Driver (Q, OUT) | Right |
| Bidirectional (SDA, USB D±) | Left or Right (context-dependent) |

- **Never** arrange IC pins in physical package order. Group by function.
- Active-low signals: use overbar notation or `~{SIGNAL}` syntax.
- Pin names use 1.27 mm (50 mil) text.

---

## 4. Wire Routing Rules

1. **No four-way junctions.** Use T-junctions only. Offset one wire if four would meet.
2. **Junction dots** required wherever 3+ wire endpoints meet at one point.
3. **Orthogonal routing only** — horizontal and vertical wires. No diagonals.
4. Exit at least one grid point (1.27 mm) straight from a pin before changing direction.
5. **Short wires + net labels** preferred over long wires crossing the sheet.
6. Minimize crossings by rearranging components.
7. Use buses for grouped multi-bit signals: `DATA[7:0]`, `GPIO[0:3]`.

---

## 5. Label Types and Usage

| Label Type | Scope | When to Use |
|---|---|---|
| Net label (local) | Single sheet only | Most intra-sheet connections |
| Global label | All sheets | Power rails, shared clocks, signals spanning entire design |
| Hierarchical label | Parent ↔ child sheet | Explicit sub-sheet interfaces (preferred for hierarchy) |
| Power symbol | All sheets (implicit global) | VCC, GND, +3V3, +5V — use instead of wiring power |

- **Use global labels sparingly.** Overuse defeats hierarchical organization.
- For a flat multi-page design (our case), global labels are appropriate for inter-sheet signals.
- **Net naming:** UPPERCASE, descriptive: `SPI1_MOSI`, `I2C_SDA`, `VBAT_SENSE`.
- Active-low: consistent suffix `_N` or overbar `~{RESET}`.

---

## 6. Power and Decoupling

### Power Symbols
- Use KiCad power symbols (`power:GND`, `power:+3V3`, etc.) — they create implicit global nets.
- Do NOT draw long wires for power distribution. Use power symbols everywhere needed.
- Use distinct symbols for different voltage domains if needed.

### Decoupling Capacitor Placement (Schematic)
- Place decoupling caps **visually adjacent** to the IC they serve, not in a separate "cap farm."
- Show the connection: `+3V3` symbol above → wire → cap pin 1 → cap pin 2 → wire → `GND` below.
- Label with value (100nF, 4.7µF) and note which IC pin they serve.

### STM32 Decoupling (this project)
| Cap | Value | IC Pin | Size |
|-----|---|---|---|
| C_VDD1, C_VDD2 | 100nF | VDD/VDDA (pin 8) | 0603 |
| C_VDD_BULK | 4.7µF | VDD/VDDA (pin 8) | 0805 |
| C_VREF1 | 1µF | VREF+ (pin 7) | 0603 |
| C_VREF2 | 10nF NP0 | VREF+ (pin 7) | 0603 |
| C_VBAT | 100nF | VBAT (pin 6) | 0603 |

---

## 7. Component Grouping

### Functional Blocks
Divide the schematic into logical blocks:
- Power supply / regulation
- MCU core (crystal, reset, decoupling, boot)
- Communication interfaces (SPI, I2C, UART, USB)
- Sensors / analog inputs
- Output drivers / actuators
- Connectors

### Visual Separation
- Use dashed rectangles (`(polyline ... (stroke (type dash)))`) to delineate blocks.
- Add a bold title text (2.54 mm font) at the top-left of each block.
- Keep 5–10 mm margin inside the rectangle.

---

## 8. Hierarchical Design

### Our Hierarchy (7 sheets)
| Page | Sheet | Content |
|---|---|---|
| 1 | Root | System block diagram with sub-sheet references |
| 2 | Power | Battery, charger, protection, LDO, charge pump |
| 3 | MCU | STM32G0B1 + crystal + decoupling + reset + boot |
| 4 | Display | 74AHCT244 level shifter + Sharp LCD connector |
| 5 | BLE | RN4871 module + decoupling |
| 6 | Connectors | USB-C, SWD, FFC daughter boards, expansion |
| 7 | UI | Encoders, 74HC14, LEDs, buzzer, EEPROM, LM35 |

### Connection Strategy
- **Global labels** for inter-sheet signal connections (flat multi-page approach).
- **Power symbols** for all power distribution (implicit global).
- Each sheet is self-contained: all needed power symbols and signal labels present.

---

## 9. Sheet Sizing

| Sheet | Recommended Size | Rationale |
|---|---|---|
| Root | A4 landscape | Overview only, 6 sub-sheet boxes |
| Power | A3 landscape | Many components, complex routing |
| MCU | A3 landscape | Large IC + many connections |
| Display | A4 landscape | Few components |
| BLE | A4 landscape | Few components |
| Connectors | A3 landscape | Multiple connectors + passives |
| UI | A3 landscape | Many small circuits |

- A4 landscape: 297 × 210 mm, usable area ~(25, 25) to (272, 185).
- A3 landscape: 420 × 297 mm, usable area ~(25, 25) to (395, 272).
- Never use sheets larger than A3 — split into multiple sheets instead.

---

## 10. Text and Annotation

| Element | Font Size (mm) | Notes |
|---|---|---|
| Reference designator (R1, U3) | 1.27 | KLC standard |
| Component value (100nF, 10k) | 1.27 | KLC standard |
| Pin names / numbers | 1.27 | KLC standard |
| Net labels | 1.27 | Match component text |
| Section titles | 2.54 | Bold, at block top-left |
| Notes / annotations | 1.27–1.524 | Smaller to avoid clutter |

- **All text horizontal.** Rotate the component, not the text.
- Reference designator: above or upper-left of symbol.
- Value: below or lower-left of symbol.
- No overlapping text on wires or other components.

---

## 11. Title Block

Every sheet must include:
- Project name: "Precision Electronic Level Instrument"
- Sheet title: functional block name
- Revision: "0.1"
- Date: "2026-04-14"

---

## 12. KiCad Coordinate System

### Symbol definitions (.kicad_sym)
- **Y-axis points UP** (mathematical convention).
- Pin `(at X Y ROT)` is the wire **connection endpoint**.
- Pin extends FROM connection point by `length` in direction `ROT`:
  - 0° = extends RIGHT (connection is on LEFT of symbol body)
  - 90° = extends UP (connection at BOTTOM)
  - 180° = extends LEFT (connection on RIGHT)
  - 270° = extends DOWN (connection at TOP)

### Schematic files (.kicad_sch)
- **Y-axis points DOWN** (screen convention).
- Symbol placement: `(symbol (at SX SY ROT) ...)`.

### Pin Position Formula
When a symbol is placed at (sx, sy) with rotation R, a pin defined at local (px, py):

```
R=0°:   wire_x = sx + px,  wire_y = sy - py
R=90°:  wire_x = sx - py,  wire_y = sy - px
R=180°: wire_x = sx - px,  wire_y = sy + py
R=270°: wire_x = sx + py,  wire_y = sy + px
```

This accounts for the Y-axis flip between symbol coords (Y-up) and schematic coords (Y-down).

---

## 13. Programmatic Generation Strategy

### Approach: Direct S-Expression Generation
- KiCad has **no official Python API for schematics** (only PCB).
- Best approach: generate `.kicad_sch` files directly as text (S-expressions).
- Third-party `kicad-sch-api` library exists but is beta; direct generation is more reliable.

### File Structure (.kicad_sch)
```
(kicad_sch
  (version 20250114)
  (generator "eeschema")
  (generator_version "10.0")
  (uuid "...")
  (paper "A3")
  (title_block ...)
  (lib_symbols
    // Embedded copies of ALL symbol definitions used on this sheet
  )
  // Content: junctions, wires, labels, symbols, sheets
  (wire ...)
  (label ...)
  (global_label ...)
  (symbol ...)        // Component instances
  (sheet ...)         // Sub-sheet references (root only)
  (sheet_instances ...)
  (embedded_fonts no)
)
```

### Key Rules for Generation
1. Every element needs a unique UUID.
2. `lib_symbols` must embed definitions for ALL symbols used on that sheet.
3. Symbol instances reference `lib_id` matching the embedded definition.
4. Power symbols are both lib_symbol definitions AND symbol instances.
5. All coordinates in mm, on 1.27 mm grid.
6. Pin endpoints must EXACTLY match wire endpoints for connections.

### Symbol Loading
- Local libraries: extract from `.kicad_sym` files with `extract_symbol()`.
- Built-in symbols (R, C, LED): define inline in the generator.
- Power symbols (GND, +3V3, +5V): define inline.
- Custom symbols (STM32 functional): define inline with pins grouped by function.

---

## 14. Checklist for Clean Schematics

- [ ] All connections on 1.27 mm grid
- [ ] Signal flow: left → right; power: top → bottom
- [ ] No four-way wire junctions
- [ ] Components grouped by function with visual separators
- [ ] Decoupling caps adjacent to their IC
- [ ] All text horizontal, 1.27 mm standard size
- [ ] Descriptive UPPERCASE net names
- [ ] Power symbols used (not long power wires)
- [ ] All IC pins accounted for (unused tied, NC marked)
- [ ] Title block on every sheet
- [ ] ERC clean (no unconnected pins, no floating nets)

---

## References

- [KiCad Library Conventions (KLC)](https://klc.kicad.org)
- [KiCad Schematic File Format](https://dev-docs.kicad.org/en/file-formats/sexpr-schematic/)
- [KiCad Default Values](https://docs.kicad.org/doxygen/default__values_8h.html)
- [Phil's Lab — KiCad STM32 Hardware Design Tutorials](https://www.phils-lab.net/courses)
- [Schemalyzer — 30 Schematic Design Best Practices](https://www.schemalyzer.com/en/blog/schematic-review/best-practices/)

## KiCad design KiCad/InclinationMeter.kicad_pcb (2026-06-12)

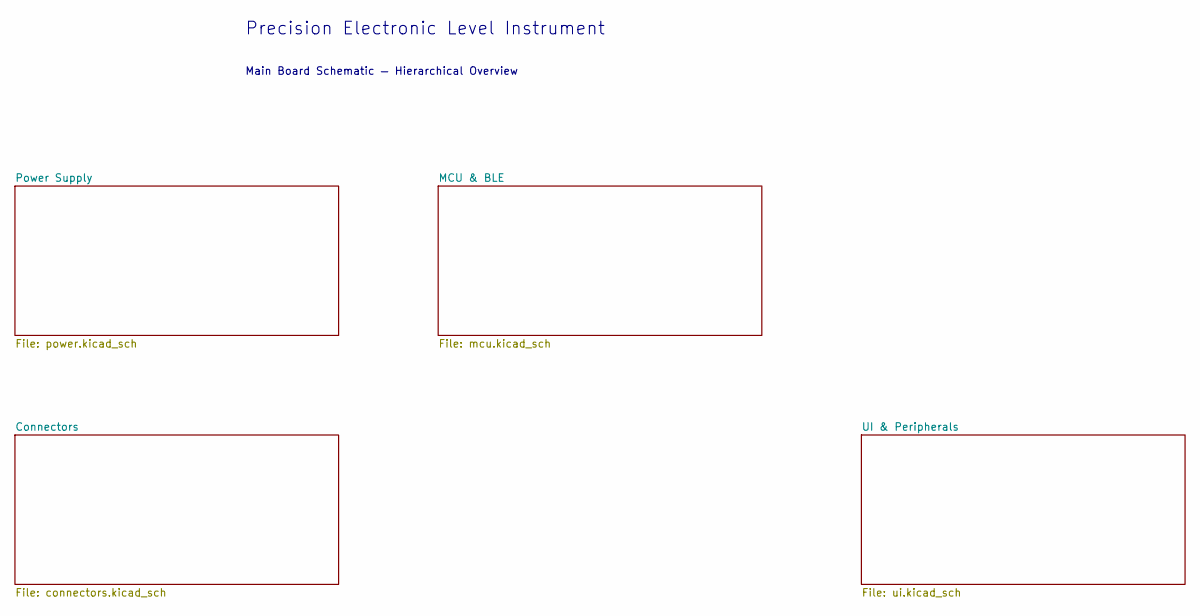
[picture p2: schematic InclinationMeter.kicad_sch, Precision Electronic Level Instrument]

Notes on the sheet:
Main Board Schematic — Hierarchical Overview
Precision Electronic Level Instrument

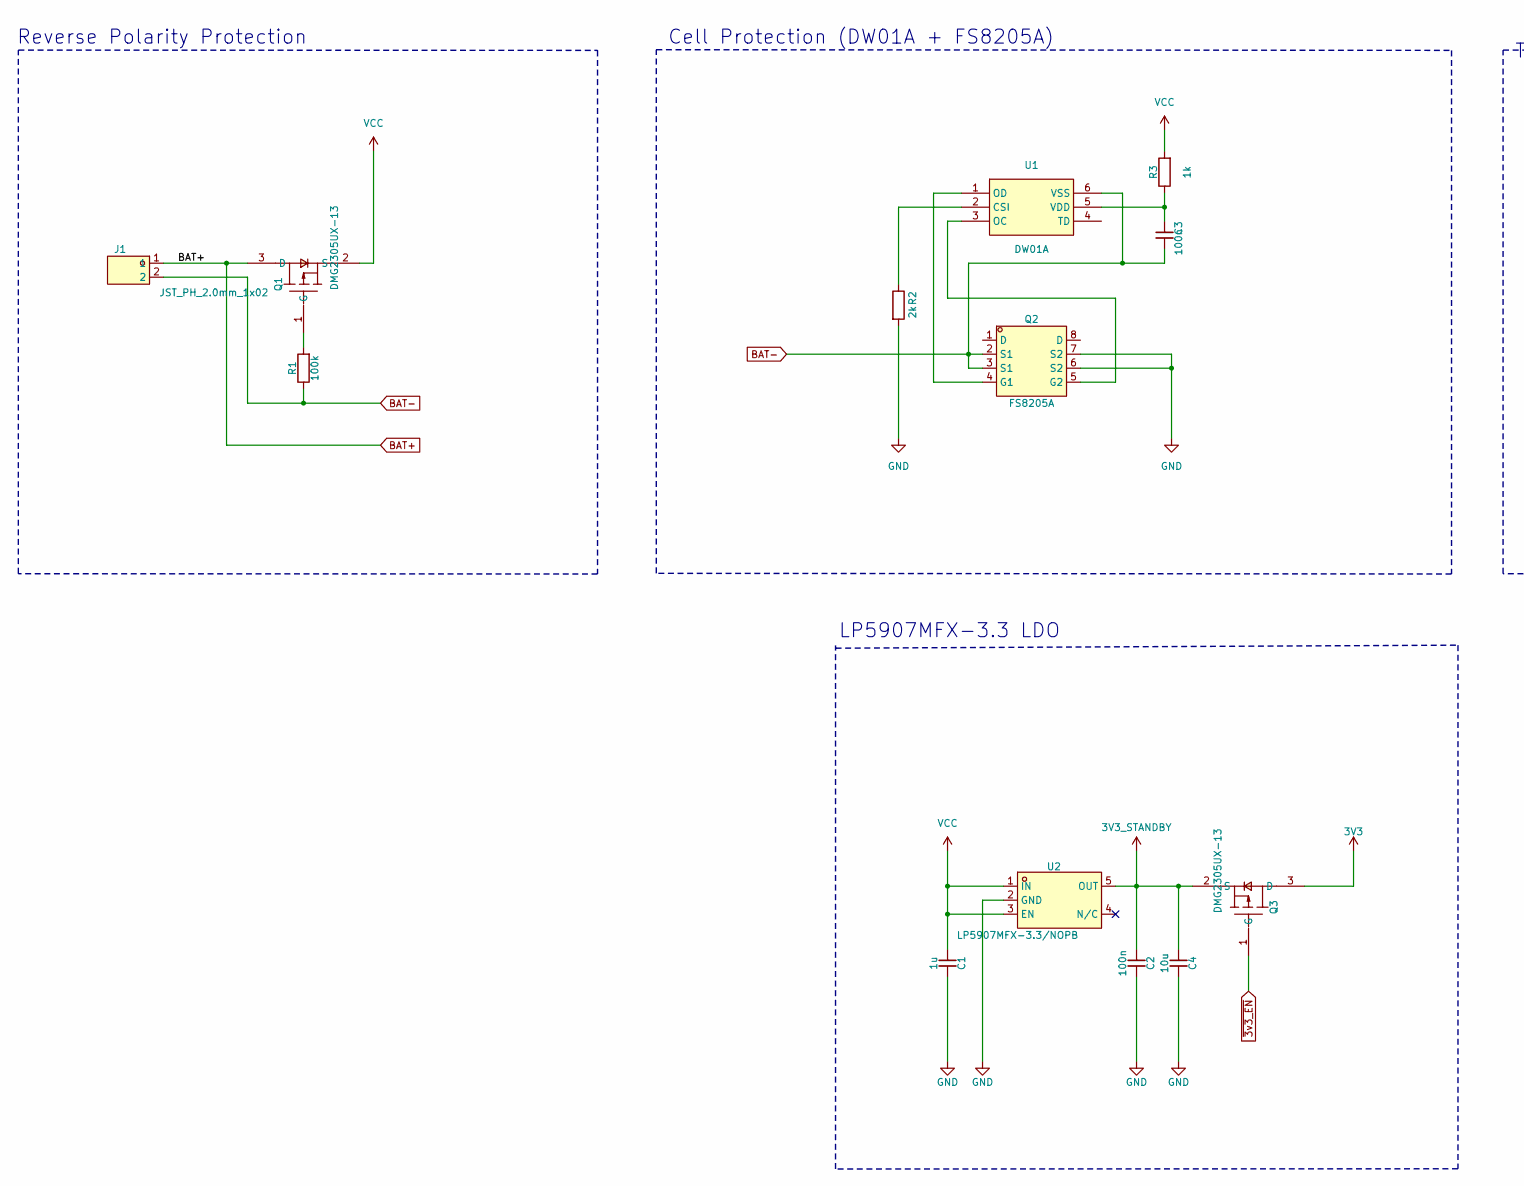
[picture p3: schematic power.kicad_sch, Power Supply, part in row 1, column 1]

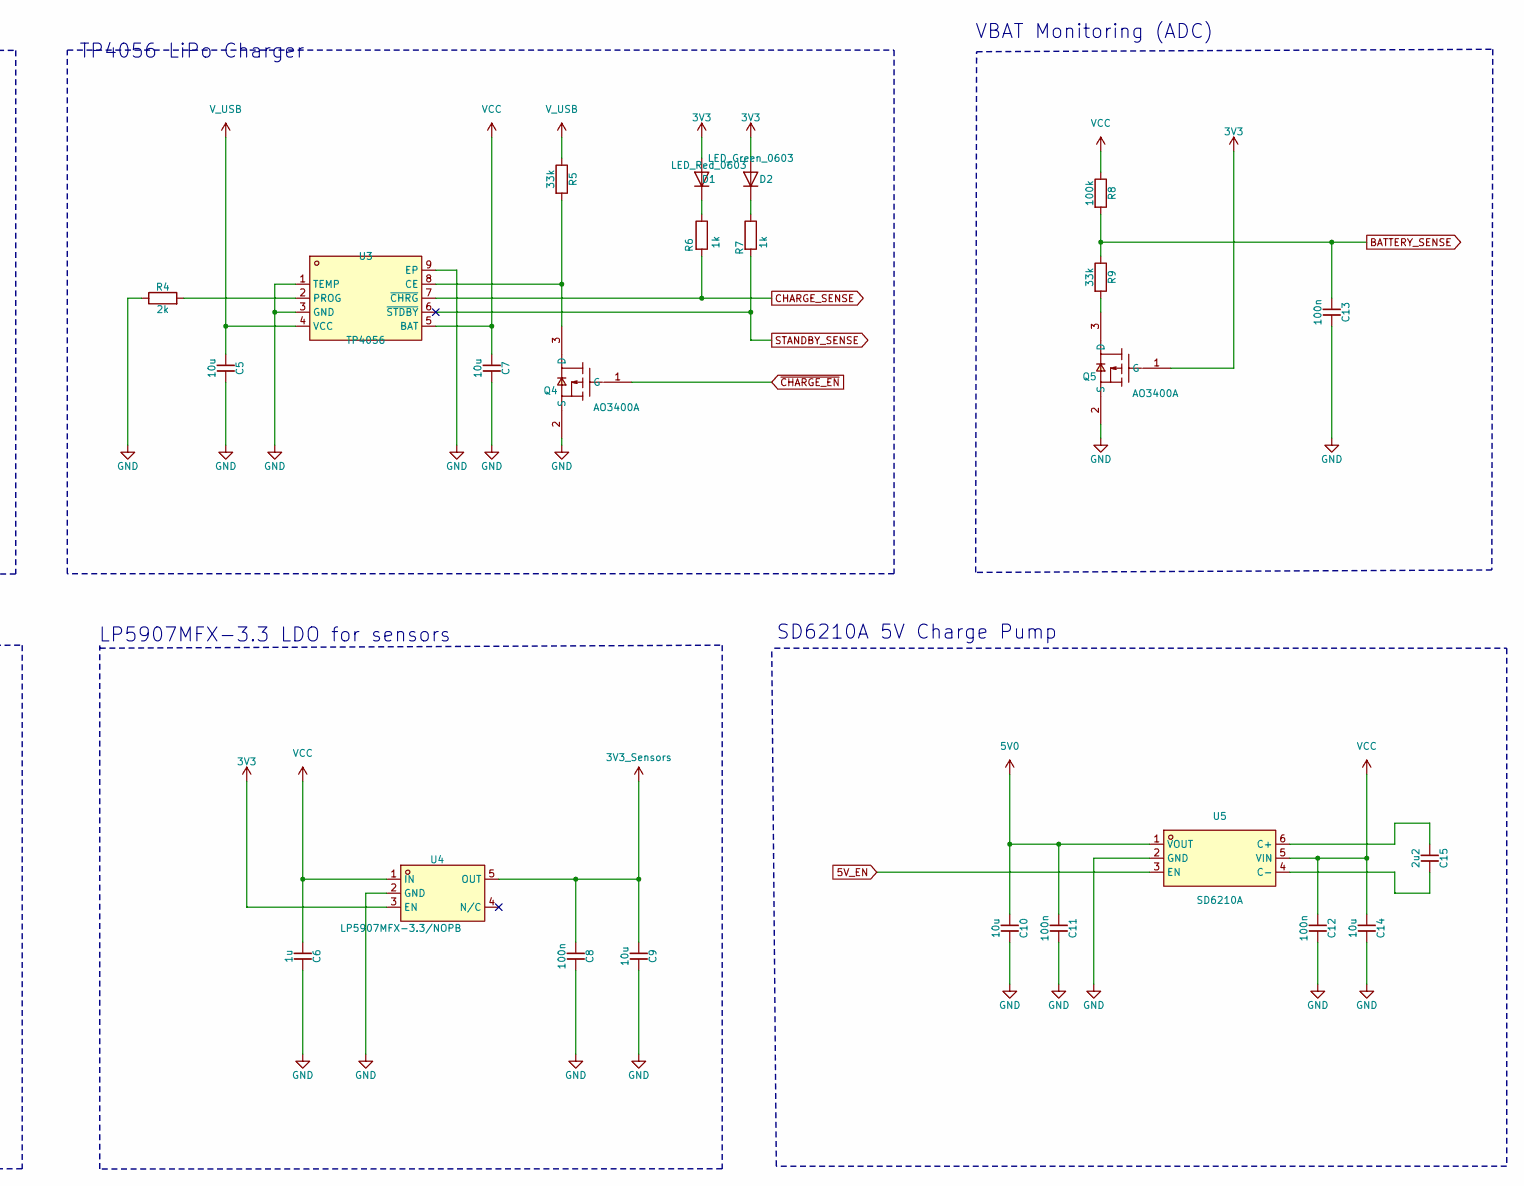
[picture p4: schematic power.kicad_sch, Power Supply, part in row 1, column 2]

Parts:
C1, C6: 1u; C_0805; Voltage 50V; MPN CL21B105KBFNNNE; LCSC C28323
C2, C3, C8, C11, C12, C13: 100n; C_0603; Voltage 50V; MPN CC0603KRX7R9BB104; LCSC C14663
C4, C5, C7, C9, C10, C14: 10u; C_1206; Voltage 25V; MPN CC1206KKX7R8BB106; LCSC C70462
C15: 2u2; C_0805; Voltage 16V; MPN GCM21BR71C225KA64L; LCSC C126589
D1: LED_Red_0603; LED_0603; MPN KT-0603R; LCSC C2286
D2: LED_Green_0603; LED_0603; MPN 19-217/GHC-YR1S2/3T; LCSC C72043
J1: JST_PH_2.0mm_1x02; MPN B2B-PH-K-S; LCSC C131337
Q1, Q3: DMG2305UX-13; SOT-23-3; MPN DMG2305UX-13; LCSC C144153
Q2: FS8205A; TSSOP-8; MPN FS8205A; LCSC C14212
Q4, Q5: AO3400A; SOT-23-3; MPN AO3400A; LCSC C20917
R1, R8: 100k; R_0603; MPN 0603WAF1003T5E; LCSC C25803
R2, R4: 2k; R_0603; MPN 0603WAF2001T5E; LCSC C22975
R3, R6, R7: 1k; R_0603; MPN 0603WAF1001T5E; LCSC C21190
R5, R9: 33k; R_0603; MPN 0603WAF3302T5E; LCSC C4216
U1: DW01A; SOT-23-6; MPN DW01A; LCSC C85680
U2, U4: LP5907MFX-3.3/NOPB; SOT-23-5; MPN LP5907MFX-3.3/NOPB; LCSC C80670
U3: TP4056; ESOP-8; MPN TP4056; LCSC C382139
U5: SD6210A; SOT-23-6; MPN SD6210A; LCSC C250809

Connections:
3V3: D1.1 (A), D2.1 (A), Q3.3 (D), Q5.1 (G), U4.3 (EN); also elsewhere on the board
3V3_STANDBY: C2.1, C4.1, Q3.2 (S), U2.5 (OUT); also elsewhere on the board
3V3_Sensors: C8.1, C9.1, U4.5 (OUT); also elsewhere on the board
5V0: C10.1, C11.1, U5.1 (VOUT); also elsewhere on the board
5V_EN: U5.3 (EN); also elsewhere on the board
~3v3_EN: Q3.1 (G); also elsewhere on the board
BAT+: J1.1, Q1.3 (D)
BAT-: C3.2, J1.2, Q2.2 (S1), Q2.3 (S1), R1.1, U1.6 (VSS)
BATTERY_SENSE: C13.1, R8.2, R9.1; also elsewhere on the board
CHARGE_SENSE: R6.2, U3.7 (~CHRG); also elsewhere on the board
GND: C1.2, C2.2, C4.2, C5.2, C6.2, C7.2, C8.2, C9.2, C10.2, C11.2, C12.2, C13.2, C14.2, Q2.6 (S2), Q2.7 (S2), Q4.2 (S), Q5.2 (S), R2.2, R4.1, U2.2 (GND), U3.1 (TEMP), U3.3 (GND), U3.9 (EP), U4.2 (GND), U5.2 (GND); also elsewhere on the board
unnamed: D1.2 (K), R6.1
unnamed: D2.2 (K), R7.1
unnamed: Q1.1 (G), R1.2
unnamed: Q2.4 (G1), U1.1 (OD)
unnamed: Q2.5 (G2), U1.3 (OC)
unnamed: Q4.3 (D), R5.2, U3.8 (CE)
unnamed: Q5.3 (D), R9.2
unnamed: R2.1, U1.2 (CSI)
unnamed: C3.1, R3.1, U1.5 (VDD)
unnamed: R4.2, U3.2 (PROG)
unnamed: C15.1, U5.6 (C+)
unnamed: C15.2, U5.4 (C-)
STANDBY_SENSE: R7.2, U3.6 (~STDBY); also elsewhere on the board
VCC: C1.1, C6.1, C7.1, C12.1, C14.1, Q1.2 (S), R3.2, R8.1, U2.1 (IN), U2.3 (EN), U3.5 (BAT), U4.1 (IN), U5.5 (VIN)
V_USB: C5.1, R5.1, U3.4 (VCC); also elsewhere on the board
~CHARGE_EN: Q4.1 (G); also elsewhere on the board

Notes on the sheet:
LP5907MFX-3.3 LDO
VBAT Monitoring (ADC)
Cell Protection (DW01A + FS8205A)
TP4056 LiPo Charger
Reverse Polarity Protection
SD6210A 5V Charge Pump
LP5907MFX-3.3 LDO for sensors

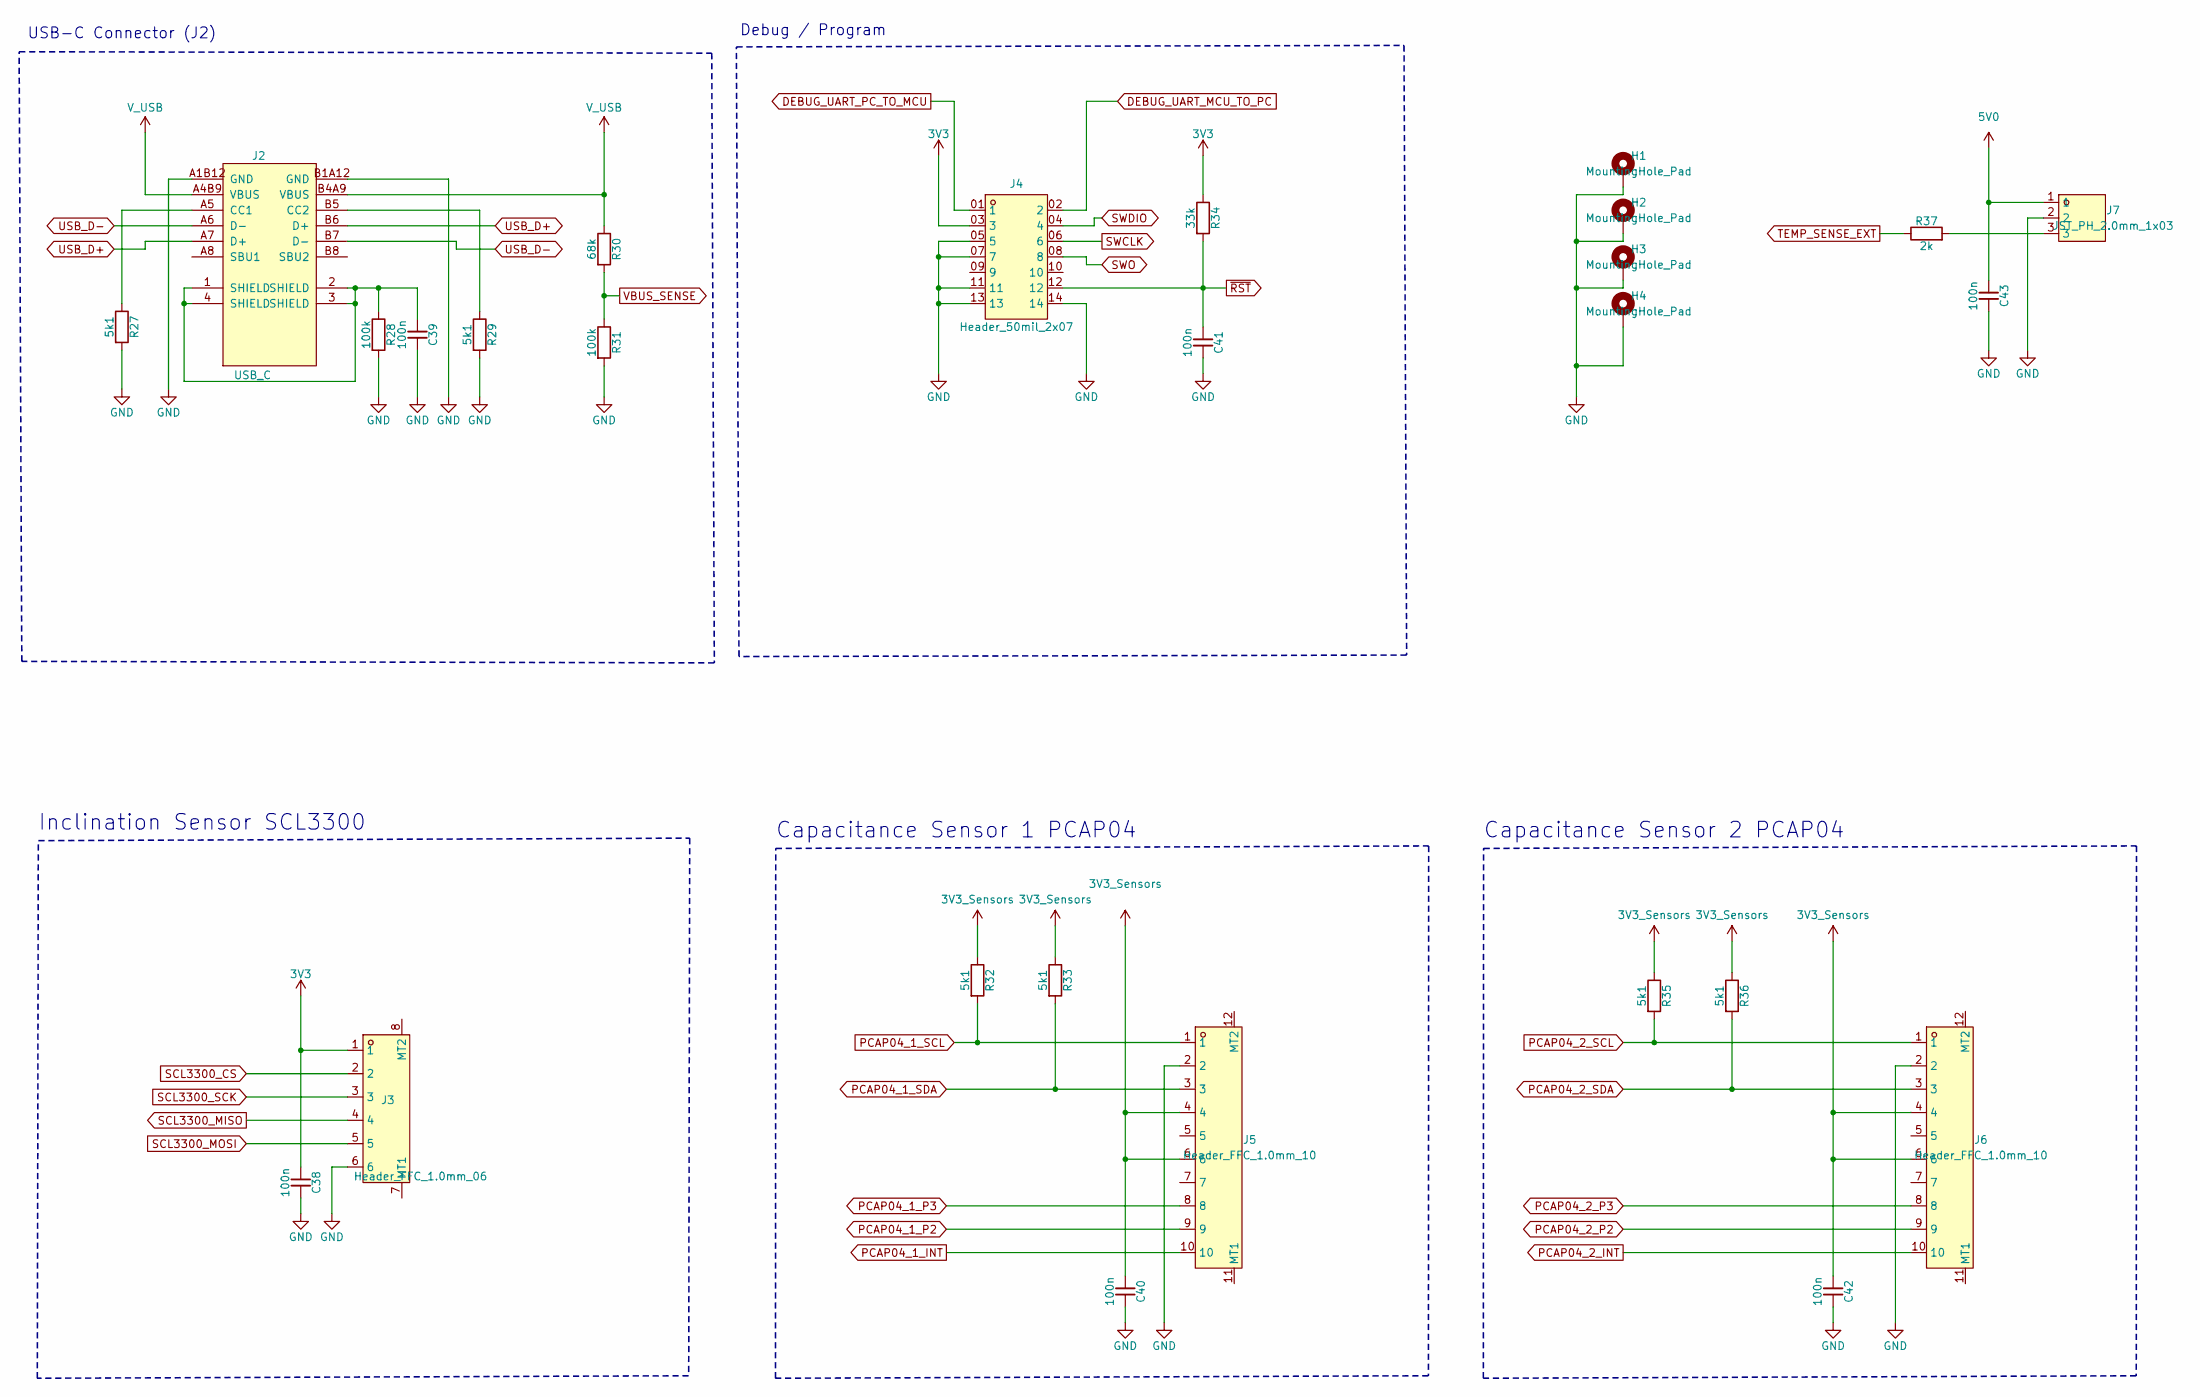
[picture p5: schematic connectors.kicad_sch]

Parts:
C38, C39, C40, C41, C42, C43: 100n; C_0603; Voltage 50V; MPN CC0603KRX7R9BB104; LCSC C14663
H1, H2, H3, H4: MountingHole_Pad; MountingHole_3.2mm
J2: USB_C; MPN TYPE-C-31-M-12; LCSC C165948
J3: Header_FFC_1.0mm_06; MPN Header_FFC_1.0mm_06; LCSC C72727
J4: Header_50mil_2x07; LCSC C5563894
J5, J6: Header_FFC_1.0mm_10; MPN Header_FFC_1.0mm_10; LCSC C52162
J7: JST_PH_2.0mm_1x03; MPN B3B-PH-K-S; LCSC C131339
R27, R29, R32, R33, R35, R36: 5k1; R_0603; MPN 0603WAF5101T5E; LCSC C23186
R28, R31: 100k; R_0603; MPN 0603WAF1003T5E; LCSC C25803
R30: 68k; R_0603; MPN 0603WAF6802T5E; LCSC C23231
R34: 33k; R_0603; MPN 0603WAF3302T5E; LCSC C4216
R37: 2k; R_0603; MPN 0603WAF2001T5E; LCSC C22975

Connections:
3V3: C38.1, J3.1, J4.03 (3), R34.1; also elsewhere on the board
3V3_Sensors: C40.1, C42.1, J5.4, J5.6, J6.4, J6.6, R32.1, R33.1, R35.1, R36.1; also elsewhere on the board
5V0: C43.1, J7.1; also elsewhere on the board
DEBUG_UART_MCU_TO_PC: J4.02 (2); also elsewhere on the board
DEBUG_UART_PC_TO_MCU: J4.01 (1); also elsewhere on the board
GND: C38.2, C39.2, C40.2, C41.2, C42.2, C43.2, H1.1 (1_1), H2.1 (1_1), H3.1 (1_1), H4.1 (1_1), J2.A1B12 (GND), J2.B1A12 (GND), J3.6, J4.05 (5), J4.07 (7), J4.11, J4.13, J4.14, J5.2, J6.2, J7.2, R27.2, R28.2, R29.2, R31.2; also elsewhere on the board
unnamed: C39.1, J2.1 (SHIELD), J2.2 (SHIELD), J2.3 (SHIELD), J2.4 (SHIELD), R28.1
unnamed: J2.A5 (CC1), R27.1
unnamed: J2.B5 (CC2), R29.1
unnamed: J7.3, R37.2
PCAP04_1_INT: J5.10; also elsewhere on the board
PCAP04_1_P2: J5.9; also elsewhere on the board
PCAP04_1_P3: J5.8; also elsewhere on the board
PCAP04_1_SCL: J5.1, R32.2; also elsewhere on the board
PCAP04_1_SDA: J5.3, R33.2; also elsewhere on the board
PCAP04_2_INT: J6.10; also elsewhere on the board
PCAP04_2_P2: J6.9; also elsewhere on the board
PCAP04_2_P3: J6.8; also elsewhere on the board
PCAP04_2_SCL: J6.1, R35.2; also elsewhere on the board
PCAP04_2_SDA: J6.3, R36.2; also elsewhere on the board
SCL3300_CS: J3.2; also elsewhere on the board
SCL3300_MISO: J3.4; also elsewhere on the board
SCL3300_MOSI: J3.5; also elsewhere on the board
SCL3300_SCK: J3.3; also elsewhere on the board
SWCLK: J4.06 (6); also elsewhere on the board
SWDIO: J4.04 (4); also elsewhere on the board
SWO: J4.08 (8); also elsewhere on the board
TEMP_SENSE_EXT: R37.1; also elsewhere on the board
USB_D+: J2.A7 (D+), J2.B6 (D+); also elsewhere on the board
USB_D-: J2.A6 (D-), J2.B7 (D-); also elsewhere on the board
VBUS_SENSE: R30.2, R31.1; also elsewhere on the board
V_USB: J2.A4B9 (VBUS), J2.B4A9 (VBUS), R30.1; also elsewhere on the board
~RST: C41.1, J4.12, R34.2; also elsewhere on the board

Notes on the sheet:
Capacitance Sensor 1 PCAP04
USB-C Connector (J2)
Capacitance Sensor 2 PCAP04
Debug / Program
Inclination Sensor SCL3300

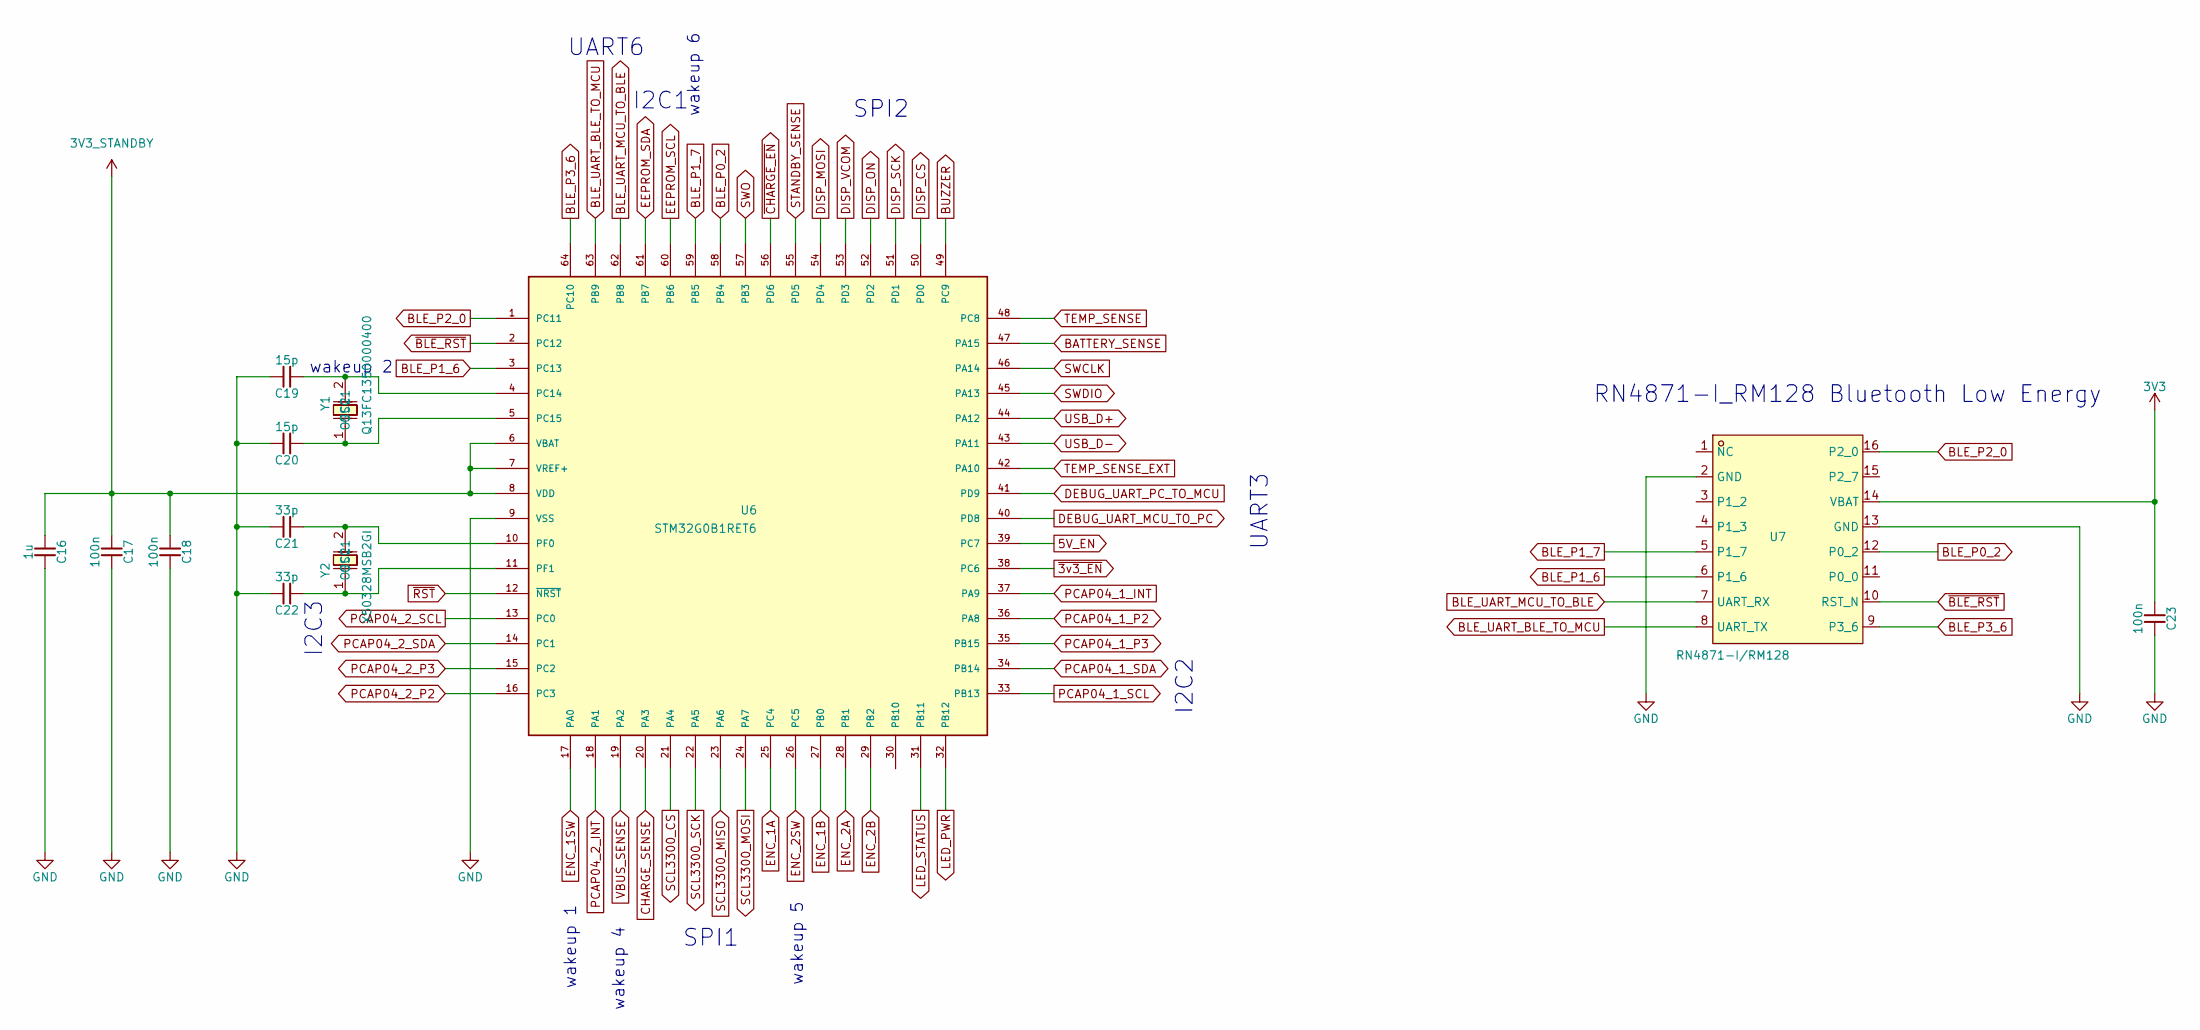
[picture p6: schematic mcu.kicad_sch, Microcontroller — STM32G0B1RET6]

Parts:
C16: 1u; C_0805; Voltage 50V; MPN CL21B105KBFNNNE; LCSC C28323
C17, C18, C23: 100n; C_0603; Voltage 50V; MPN CC0603KRX7R9BB104; LCSC C14663
C19, C20: 15p; C_0603; Voltage 50V; MPN CL10C150JB8NNNC; LCSC C1644
C21, C22: 33p; C_0603; Voltage 50V; MPN CL10C330JB8NNNC; LCSC C1663
U6: STM32G0B1RET6; LQFP-64; LCSC C2829307
U7: RN4871-I/RM128; RN4871; MPN RN4871-I/RM128; LCSC C633941
Y1: Q13FC1350000400; CRYSTAL-3215; MPN Q13FC1350000400; LCSC C32346
Y2: X50328MSB2GI; CRYSTAL-3225; MPN X50328MSB2GI; LCSC C115962

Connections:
3V3: C23.1, U7.14 (VBAT); also elsewhere on the board
3V3_STANDBY: C16.1, C17.1, C18.1, U6.6 (VBAT), U6.7 (VREF+), U6.8 (VDD); also elsewhere on the board
5V_EN: U6.39 (PC7); also elsewhere on the board
~3v3_EN: U6.38 (PC6); also elsewhere on the board
BATTERY_SENSE: U6.47 (PA15); also elsewhere on the board
BLE_P0_2: U6.58 (PB4), U7.12 (P0_2)
BLE_P1_6: U6.3 (PC13), U7.6 (P1_6)
BLE_P1_7: U6.59 (PB5), U7.5 (P1_7)
BLE_P2_0: U6.1 (PC11), U7.16 (P2_0)
BLE_P3_6: U6.64 (PC10), U7.9 (P3_6)
BLE_UART_BLE_TO_MCU: U6.63 (PB9), U7.8 (UART_TX)
BLE_UART_MCU_TO_BLE: U6.62 (PB8), U7.7 (UART_RX)
BUZZER: U6.49 (PC9); also elsewhere on the board
CHARGE_SENSE: U6.20 (PA3); also elsewhere on the board
DEBUG_UART_MCU_TO_PC: U6.40 (PD8); also elsewhere on the board
DEBUG_UART_PC_TO_MCU: U6.41 (PD9); also elsewhere on the board
DISP_CS: U6.50 (PD0); also elsewhere on the board
DISP_MOSI: U6.54 (PD4); also elsewhere on the board
DISP_ON: U6.52 (PD2); also elsewhere on the board
DISP_SCK: U6.51 (PD1); also elsewhere on the board
DISP_VCOM: U6.53 (PD3); also elsewhere on the board
EEPROM_SCL: U6.60 (PB6); also elsewhere on the board
EEPROM_SDA: U6.61 (PB7); also elsewhere on the board
ENC_1A: U6.25 (PC4); also elsewhere on the board
ENC_1B: U6.27 (PB0); also elsewhere on the board
ENC_1SW: U6.17 (PA0); also elsewhere on the board
ENC_2A: U6.28 (PB1); also elsewhere on the board
ENC_2B: U6.29 (PB2); also elsewhere on the board
ENC_2SW: U6.26 (PC5); also elsewhere on the board
GND: C16.2, C17.2, C18.2, C19.2, C20.2, C21.2, C22.2, C23.2, U6.9 (VSS), U7.2 (GND), U7.13 (GND); also elsewhere on the board
LED_PWR: U6.32 (PB12); also elsewhere on the board
LED_STATUS: U6.31 (PB11); also elsewhere on the board
unnamed: C19.1, U6.4 (PC14), Y1.2 (OSC2)
unnamed: C20.1, U6.5 (PC15), Y1.1 (OSC1)
unnamed: C21.1, U6.10 (PF0), Y2.2 (OSC2)
unnamed: C22.1, U6.11 (PF1), Y2.1 (OSC1)
PCAP04_1_INT: U6.37 (PA9); also elsewhere on the board
PCAP04_1_P2: U6.36 (PA8); also elsewhere on the board
PCAP04_1_P3: U6.35 (PB15); also elsewhere on the board
PCAP04_1_SCL: U6.33 (PB13); also elsewhere on the board
PCAP04_1_SDA: U6.34 (PB14); also elsewhere on the board
PCAP04_2_INT: U6.18 (PA1); also elsewhere on the board
PCAP04_2_P2: U6.16 (PC3); also elsewhere on the board
PCAP04_2_P3: U6.15 (PC2); also elsewhere on the board
PCAP04_2_SCL: U6.13 (PC0); also elsewhere on the board
PCAP04_2_SDA: U6.14 (PC1); also elsewhere on the board
SCL3300_CS: U6.21 (PA4); also elsewhere on the board
SCL3300_MISO: U6.23 (PA6); also elsewhere on the board
SCL3300_MOSI: U6.24 (PA7); also elsewhere on the board
SCL3300_SCK: U6.22 (PA5); also elsewhere on the board
STANDBY_SENSE: U6.55 (PD5); also elsewhere on the board
SWCLK: U6.46 (PA14); also elsewhere on the board
SWDIO: U6.45 (PA13); also elsewhere on the board
SWO: U6.57 (PB3); also elsewhere on the board
TEMP_SENSE: U6.48 (PC8); also elsewhere on the board
TEMP_SENSE_EXT: U6.42 (PA10); also elsewhere on the board
USB_D+: U6.44 (PA12); also elsewhere on the board
USB_D-: U6.43 (PA11); also elsewhere on the board
VBUS_SENSE: U6.19 (PA2); also elsewhere on the board
~BLE_RST: U6.2 (PC12), U7.10 (RST_N)
~CHARGE_EN: U6.56 (PD6); also elsewhere on the board
~RST: U6.12 (~NRST); also elsewhere on the board

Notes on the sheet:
SPI1
wakeup 2
wakeup 1
I2C2
SPI2
wakeup 5
I2C3
wakeup 4
I2C1
UART6
wakeup 6
RN4871-I_RM128 Bluetooth Low Energy
UART3

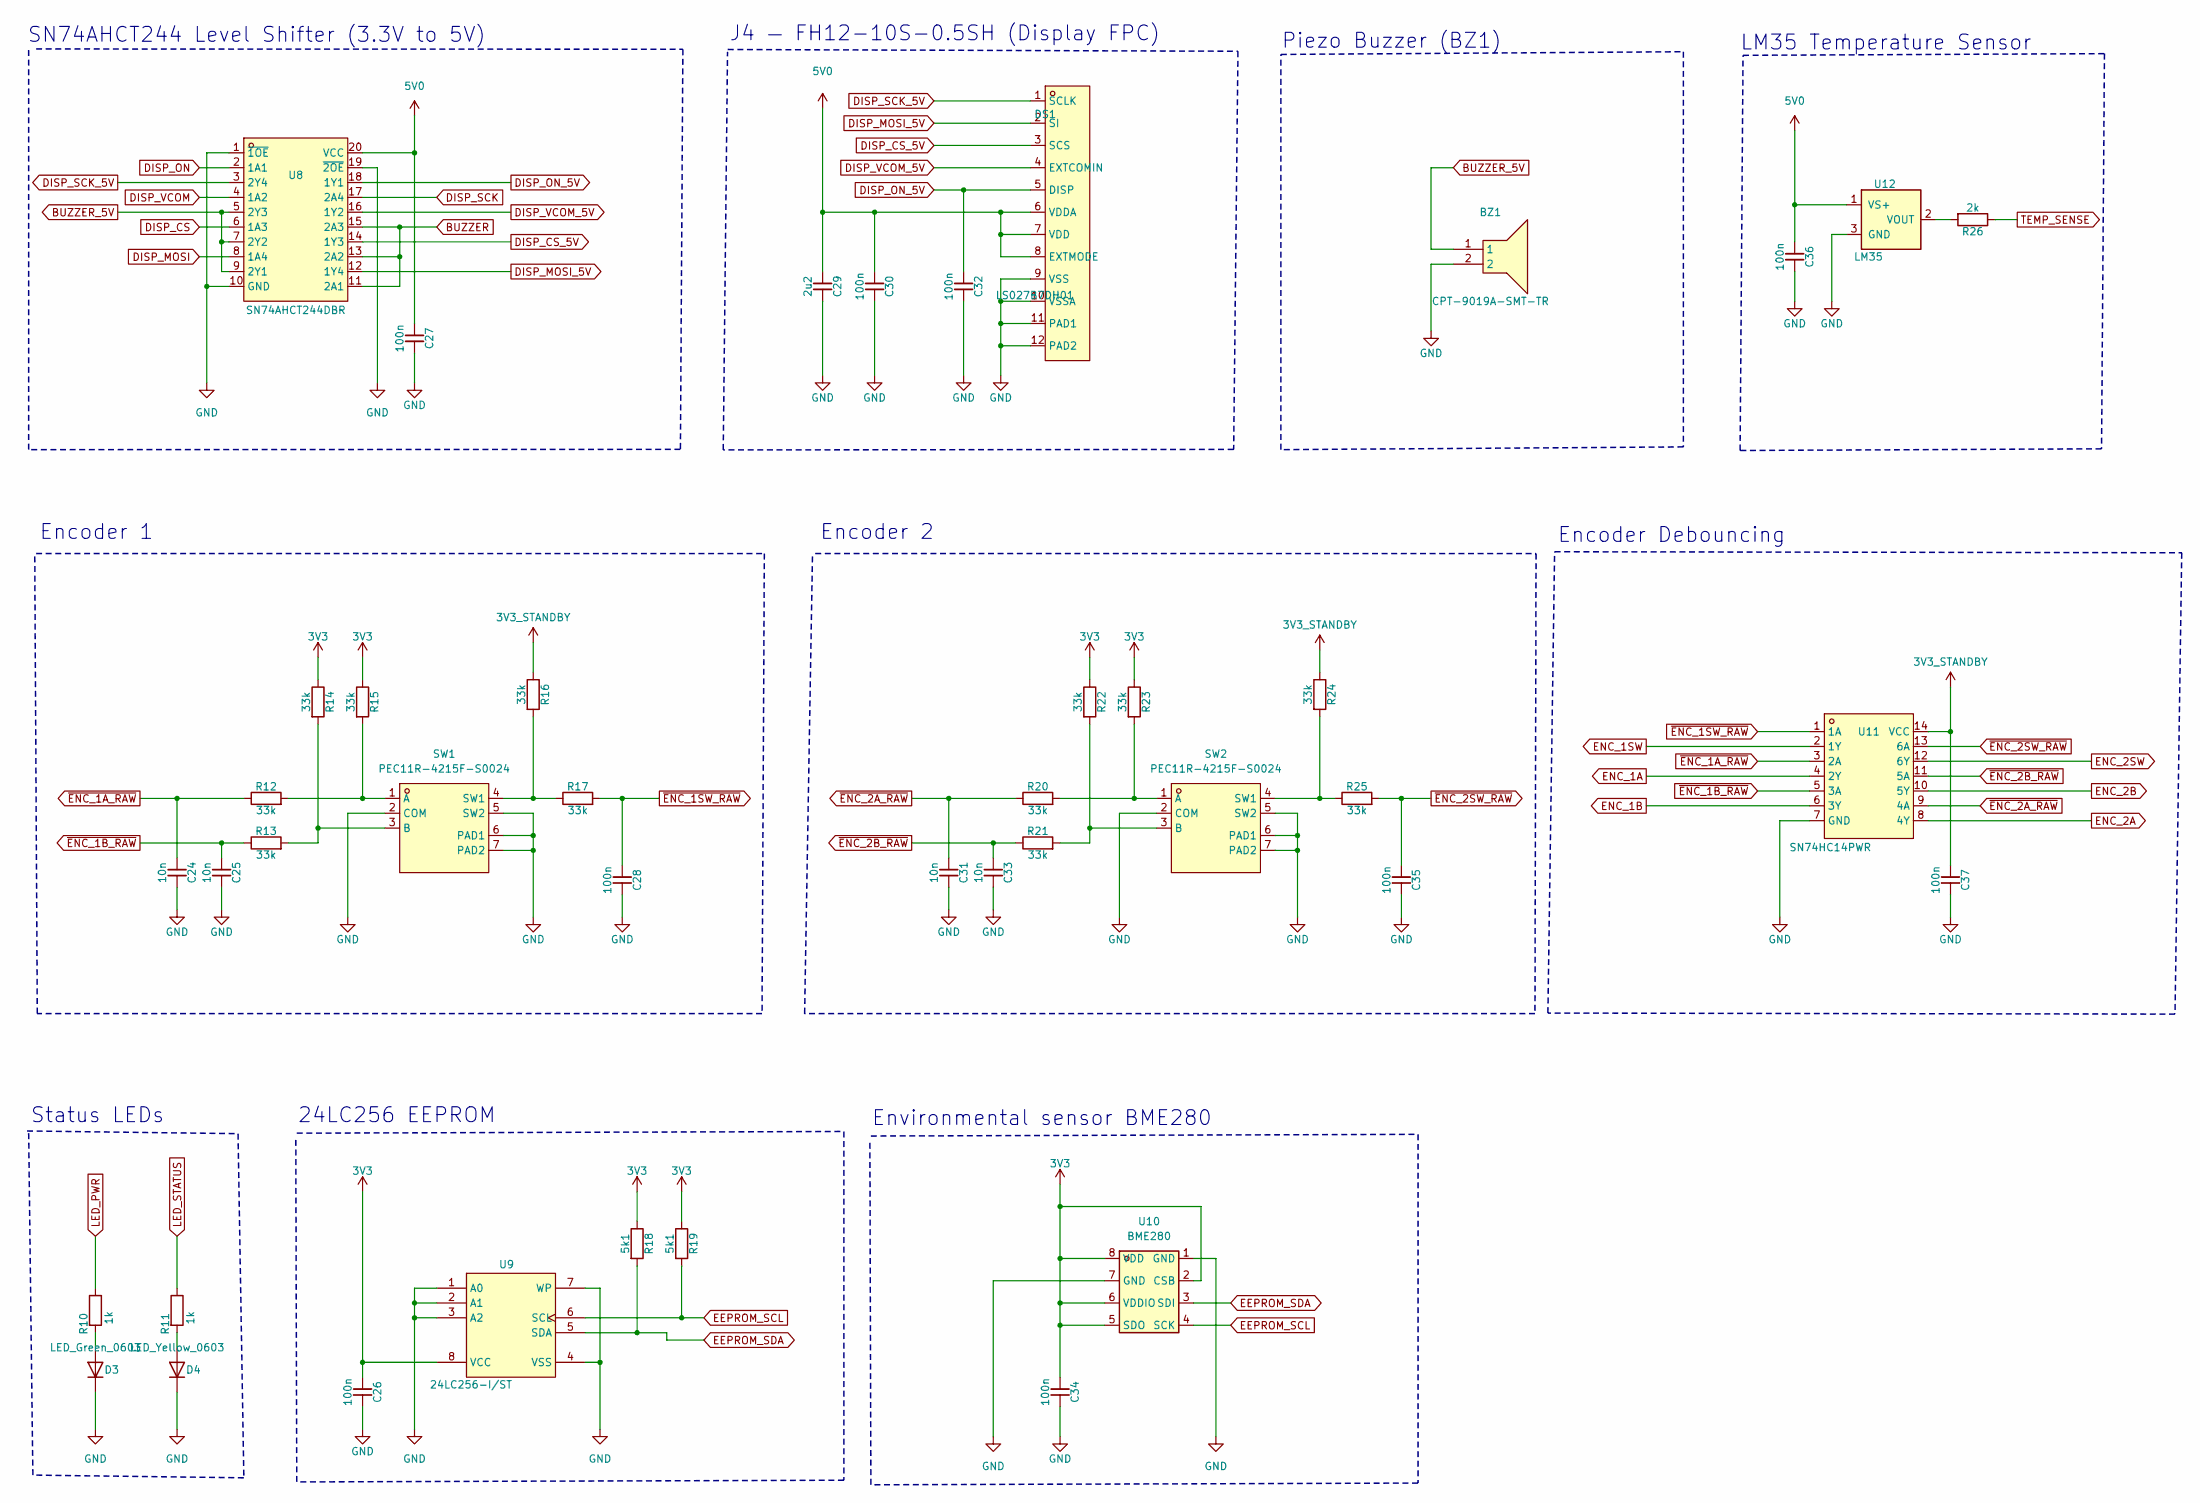
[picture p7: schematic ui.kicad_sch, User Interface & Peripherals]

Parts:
BZ1: CPT-9019A-SMT-TR; CPT-9019A; MPN CPT-9019A-SMT-TR; LCSC C20181991
C24, C25, C31, C33: 10n; C_0603; Voltage 50V; MPN 0603B103K500NT; LCSC C57112
C26, C27, C28, C30, C32, C34, C35, C36, C37: 100n; C_0603; Voltage 50V; MPN CC0603KRX7R9BB104; LCSC C14663
C29: 2u2; C_0805; Voltage 16V; MPN GCM21BR71C225KA64L; LCSC C126589
D3: LED_Green_0603; LED_0603; MPN 19-217/GHC-YR1S2/3T; LCSC C72043
D4: LED_Yellow_0603; LED_0603; MPN KT-0603Y; LCSC C2287
DS1: LS027B7DH01; Display_LS027B7DH01; MPN LS027B7DH01; LCSC C17492463
R10, R11: 1k; R_0603; MPN 0603WAF1001T5E; LCSC C21190
R12, R13, R14, R15, R16, R17, R20, R21, R22, R23, R24, R25: 33k; R_0603; MPN 0603WAF3302T5E; LCSC C4216
R18, R19: 5k1; R_0603; MPN 0603WAF5101T5E; LCSC C23186
R26: 2k; R_0603; MPN 0603WAF2001T5E; LCSC C22975
SW1, SW2: PEC11R-4215F-S0024; RotaryEncoder_PEC11R; MPN PEC11R-4215F-S0024; LCSC C143790
U8: SN74AHCT244DBR; SSOP-20; MPN SN74AHCT244DBR; LCSC C2868870
U9: 24LC256-I/ST; TSSOP-8; MPN 24LC256-I/ST; LCSC C87823
U10: BME280; LGA-8_2.5x2.5mm_P0.65mm; MPN BME280; LCSC C92489
U11: SN74HC14PWR; TSSOP-14; MPN SN74HC14PWR; LCSC C6821
U12: LM35; SOT-23-3; LCSC C9900081740

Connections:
3V3: C26.1, C34.1, R14.1, R15.1, R18.1, R19.1, R22.1, R23.1, U9.8 (VCC), U10.2 (CSB), U10.5 (SDO), U10.6 (VDDIO), U10.8 (VDD); also elsewhere on the board
3V3_STANDBY: C37.1, R16.1, R24.1, U11.14 (VCC); also elsewhere on the board
5V0: C27.1, C29.1, C30.1, C36.1, DS1.6 (VDDA), DS1.7 (VDD), DS1.8 (EXTMODE), U8.20 (VCC), U12.1 (VS+); also elsewhere on the board
BUZZER: U8.11 (2A1), U8.13 (2A2), U8.15 (2A3); also elsewhere on the board
BUZZER_5V: BZ1.1, U8.5 (2Y3), U8.7 (2Y2), U8.9 (2Y1)
DISP_CS: U8.6 (1A3); also elsewhere on the board
DISP_CS_5V: DS1.3 (SCS), U8.14 (1Y3)
DISP_MOSI: U8.8 (1A4); also elsewhere on the board
DISP_MOSI_5V: DS1.2 (SI), U8.12 (1Y4)
DISP_ON: U8.2 (1A1); also elsewhere on the board
DISP_ON_5V: C32.1, DS1.5 (DISP), U8.18 (1Y1)
DISP_SCK: U8.17 (2A4); also elsewhere on the board
DISP_SCK_5V: DS1.1 (SCLK), U8.3 (2Y4)
DISP_VCOM: U8.4 (1A2); also elsewhere on the board
DISP_VCOM_5V: DS1.4 (EXTCOMIN), U8.16 (1Y2)
EEPROM_SCL: R19.2, U9.6 (SCL), U10.4 (SCK); also elsewhere on the board
EEPROM_SDA: R18.2, U9.5 (SDA), U10.3 (SDI); also elsewhere on the board
ENC_1A: U11.4 (2Y); also elsewhere on the board
ENC_1B: U11.6 (3Y); also elsewhere on the board
ENC_1SW: U11.2 (1Y); also elsewhere on the board
ENC_2A: U11.8 (4Y); also elsewhere on the board
ENC_2B: U11.10 (5Y); also elsewhere on the board
ENC_2SW: U11.12 (6Y); also elsewhere on the board
GND: BZ1.2, C24.2, C25.2, C26.2, C27.2, C28.2, C29.2, C30.2, C31.2, C32.2, C33.2, C34.2, C35.2, C36.2, C37.2, D3.2 (K), D4.2 (K), DS1.9 (VSS), DS1.10 (VSSA), DS1.11 (PAD1), DS1.12 (PAD2), SW1.2 (COM), SW1.5 (SW2), SW1.6 (PAD1), SW1.7 (PAD2), SW2.2 (COM), SW2.5 (SW2), SW2.6 (PAD1), SW2.7 (PAD2), U8.1 (~1OE), U8.10 (GND), U8.19 (~2OE), U9.1 (A0), U9.2 (A1), U9.3 (A2), U9.4 (VSS), U9.7 (WP), U10.1 (GND), U10.7 (GND), U11.7 (GND), U12.3 (GND); also elsewhere on the board
LED_PWR: R10.1; also elsewhere on the board
LED_STATUS: R11.1; also elsewhere on the board
unnamed: D3.1 (A), R10.2
unnamed: D4.1 (A), R11.2
unnamed: R12.2, R15.2, SW1.1 (A)
unnamed: R13.2, R14.2, SW1.3 (B)
unnamed: R16.2, R17.1, SW1.4 (SW1)
unnamed: R20.2, R23.2, SW2.1 (A)
unnamed: R21.2, R22.2, SW2.3 (B)
unnamed: R24.2, R25.1, SW2.4 (SW1)
unnamed: R26.2, U12.2 (VOUT)
TEMP_SENSE: R26.1; also elsewhere on the board
~ENC_1A_RAW: C24.1, R12.1, U11.3 (2A)
~ENC_1B_RAW: C25.1, R13.1, U11.5 (3A)
~ENC_1SW_RAW: C28.1, R17.2, U11.1 (1A)
~ENC_2A_RAW: C31.1, R20.1, U11.9 (4A)
~ENC_2B_RAW: C33.1, R21.1, U11.11 (5A)
~ENC_2SW_RAW: C35.1, R25.2, U11.13 (6A)

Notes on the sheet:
Encoder 2
Encoder Debouncing
Status LEDs
LM35 Temperature Sensor
SN74AHCT244 Level Shifter (3.3V to 5V)
Environmental sensor BME280
24LC256 EEPROM
J4 — FH12-10S-0.5SH (Display FPC)
Piezo Buzzer (BZ1)
Encoder 1

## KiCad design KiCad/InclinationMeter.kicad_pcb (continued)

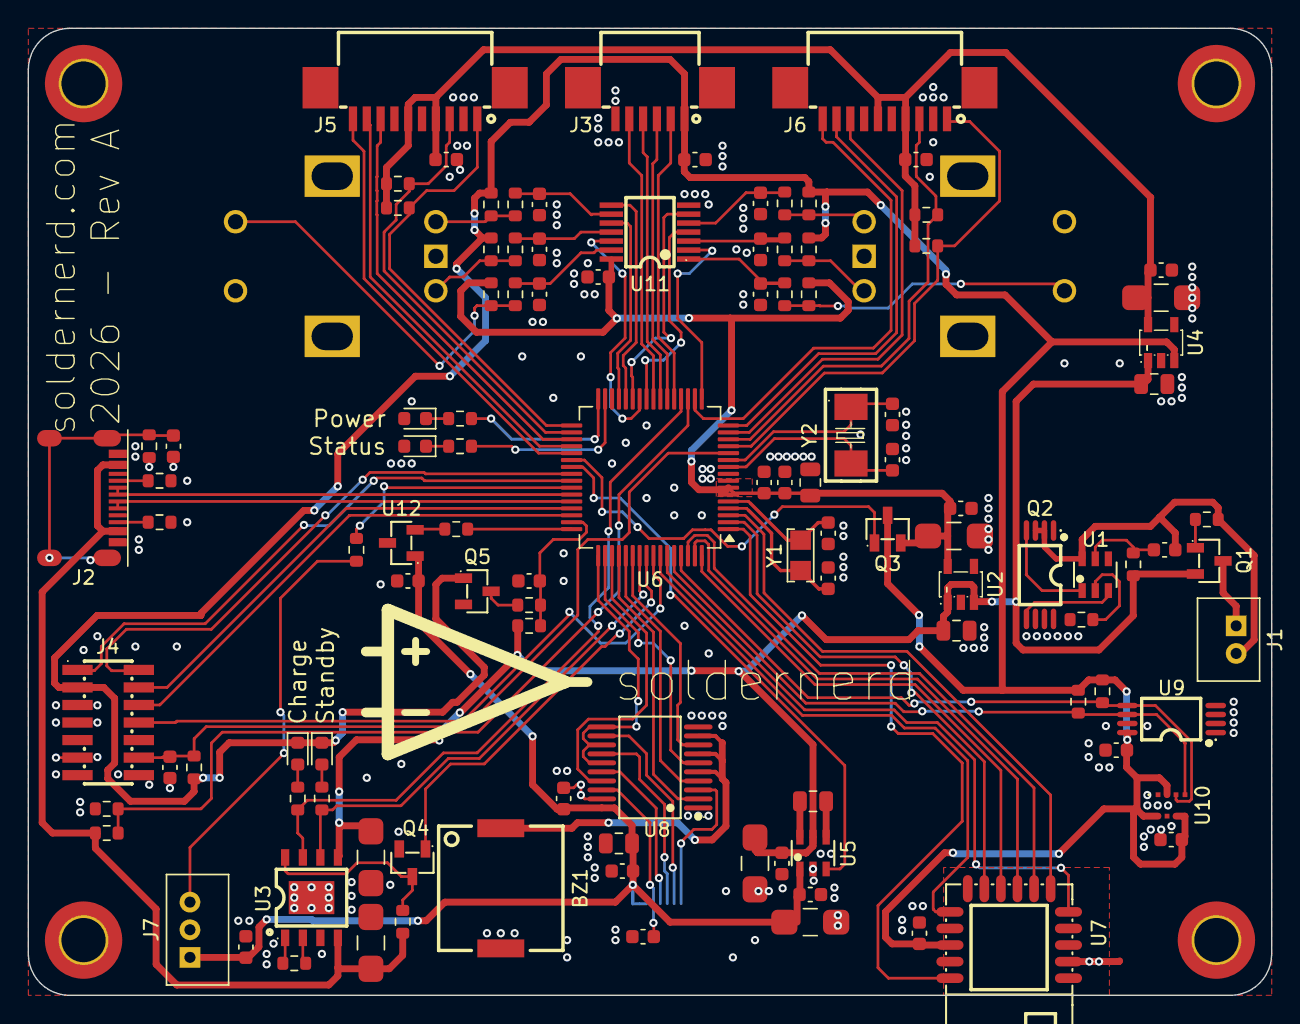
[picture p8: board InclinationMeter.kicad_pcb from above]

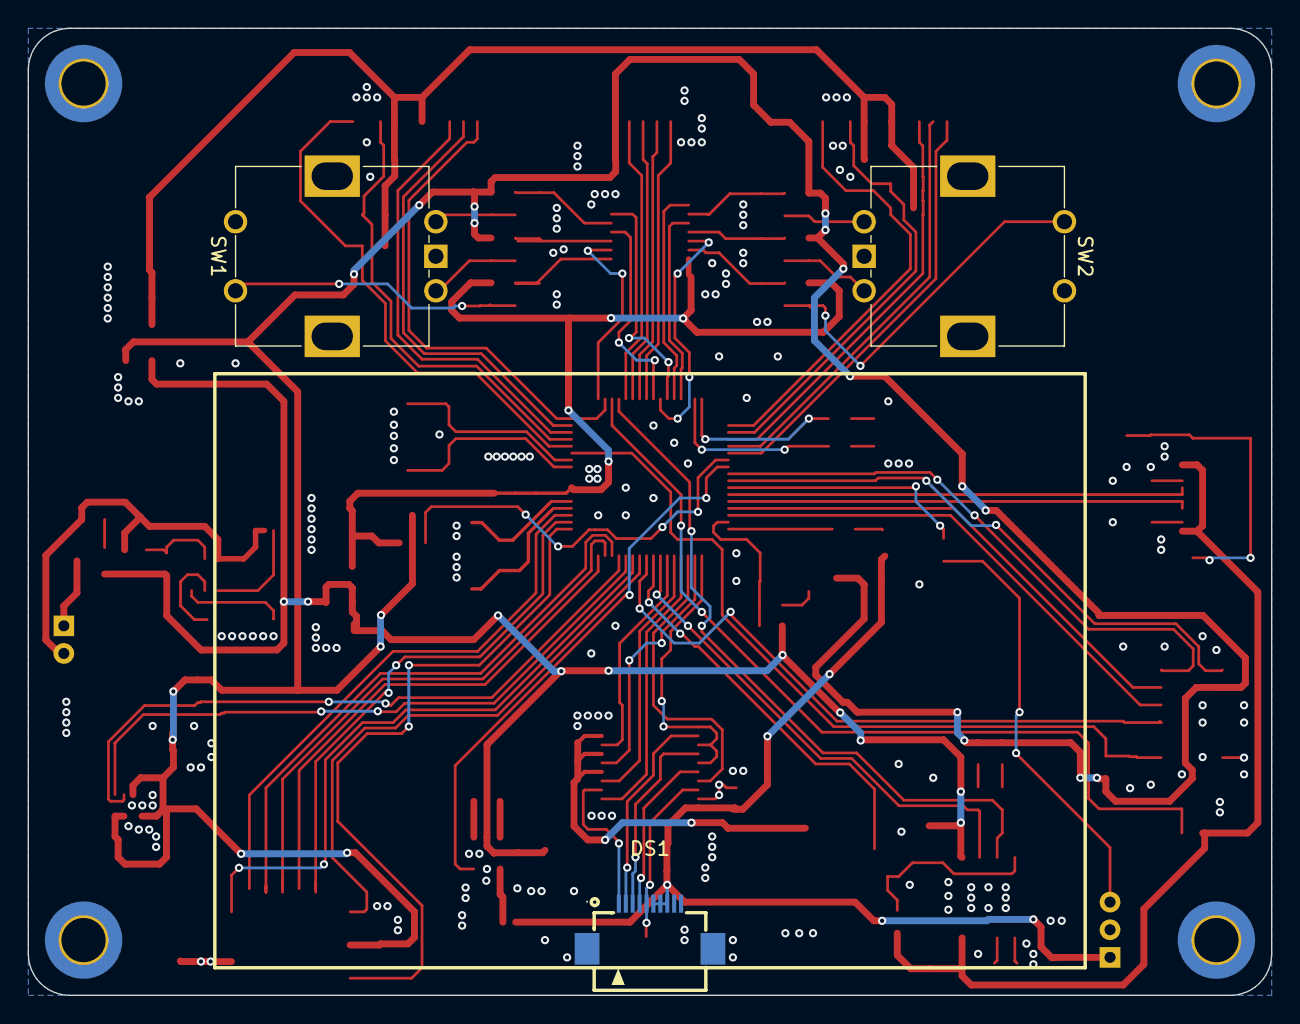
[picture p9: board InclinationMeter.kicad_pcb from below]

Board: 4 copper layers, 90.0 x 70.0 mm, 118 parts (3 on the bottom side), 105 nets.

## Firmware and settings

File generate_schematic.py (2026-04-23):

#!/usr/bin/env python3
"""
KiCad 10 Schematic Generator — Precision Electronic Level Instrument.

Generates a hierarchical .kicad_sch schematic with actual component symbols
placed and wired, following professional schematic layout best practices.

Usage:  python generate_schematic.py
Output: KiCad/ directory with .kicad_sch, .kicad_pro, library tables.

Reference: KiCad_SchematicsGuide.md, spec.md, Netlist.md
"""

import uuid
import json
import re
from pathlib import Path

# ═══════════════════════════════════════════════════════════════════════════
# CONFIGURATION
# ═══════════════════════════════════════════════════════════════════════════

SCRIPT_DIR = Path(__file__).resolve().parent
PROJECT_DIR = SCRIPT_DIR / "KiCad"
LOCAL_LIB_DIR = SCRIPT_DIR / "Libraries" / "KiCad"
KICAD_SYM_DIR = Path(r"C:\Program Files\KiCad\10.0\share\kicad\symbols")

PROJECT_NAME = "InclinationMeter"
DATE = "2026-04-14"
REV = "0.1"

# ═══════════════════════════════════════════════════════════════════════════
# HELPERS
# ═══════════════════════════════════════════════════════════════════════════

def uid():
    return str(uuid.uuid4())


# Current instance path for the sheet being generated.
# Set by each sheet generator before creating components.
# Format: "/{root_uuid}/{sheet_uuid}" for sub-sheets, "/{root_uuid}" for root.
_current_instance_path = ""


# ── Pin position data for all local library symbols ──
# Extracted from .kicad_sym files. Format: {pin_num: (x, y)} in symbol coords (Y-up).
# Connection point = the (at X Y) value from the pin definition.

PINS = {
    "TP4056": {
        "1": (-12.70, 2.54), "2": (-12.70, 0.00), "3": (-12.70, -2.54),
        "4": (-12.70, -5.08), "5": (12.70, -5.08), "6": (12.70, -2.54),
        "7": (12.70, 0.00), "8": (12.70, 2.54), "9": (12.70, 5.08),
    },
    "DW01A": {
        "1": (-12.70, 2.54), "2": (-12.70, 0.00), "3": (-12.70, -2.54),
        "4": (12.70, -2.54), "5": (12.70, 0.00), "6": (12.70, 2.54),
    },
    "FS8205A": {
        "1": (-8.89, 3.81), "2": (-8.89, 1.27), "3": (-8.89, -1.27),
        "4": (-8.89, -3.81), "5": (8.89, -3.81), "6": (8.89, -1.27),
        "7": (8.89, 1.27), "8": (8.89, 3.81),
    },
    "DMG2305UX": {
        "1": (-7.62, 0.00), "2": (5.08, -10.16), "3": (5.08, 10.16),
    },
    "LP5907": {
        "1": (-10.16, 2.54), "2": (-10.16, 0.00), "3": (-10.16, -2.54),
        "4": (10.16, -2.54), "5": (10.16, 2.54),
    },
    "SD6210A": {
        "1": (-12.70, 2.54), "2": (-12.70, 0.00), "3": (-12.70, -2.54),
        "4": (12.70, -2.54), "5": (12.70, 0.00), "6": (12.70, 2.54),
    },
    "SN74AHCT244": {
        "1": (-11.43, 11.43), "2": (-11.43, 8.89), "3": (-11.43, 6.35),
        "4": (-11.43, 3.81), "5": (-11.43, 1.27), "6": (-11.43, -1.27),
        "7": (-11.43, -3.81), "8": (-11.43, -6.35), "9": (-11.43, -8.89),
        "10": (-11.43, -11.43), "11": (11.43, -11.43), "12": (11.43, -8.89),
        "13": (11.43, -6.35), "14": (11.43, -3.81), "15": (11.43, -1.27),
        "16": (11.43, 1.27), "17": (11.43, 3.81), "18": (11.43, 6.35),
        "19": (11.43, 8.89), "20": (11.43, 11.43),
    },
    "SN74HC14": {
        "1": (-10.16, 7.62), "2": (-10.16, 5.08), "3": (-10.16, 2.54),
        "4": (-10.16, 0.00), "5": (-10.16, -2.54), "6": (-10.16, -5.08),
        "7": (-10.16, -7.62), "8": (10.16, -7.62), "9": (10.16, -5.08),
        "10": (10.16, -2.54), "11": (10.16, 0.00), "12": (10.16, 2.54),
        "13": (10.16, 5.08), "14": (10.16, 7.62),
    },
    "RN4871": {
        "1": (-13.97, 8.89), "2": (-13.97, 6.35), "3": (-13.97, 3.81),
        "4": (-13.97, 1.27), "5": (-13.97, -1.27), "6": (-13.97, -3.81),
        "7": (-13.97, -6.35), "8": (-13.97, -8.89),
        "9": (13.97, -8.89), "10": (13.97, -6.35), "11": (13.97, -3.81),
        "12": (13.97, -1.27), "13": (13.97, 1.27), "14": (13.97, 3.81),
        "15": (13.97, 6.35), "16": (13.97, 8.89),
    },
    "24LC256": {
        "1": (-12.70, 6.35), "2": (-12.70, 3.81), "3": (-12.70, 1.27),
        "4": (12.70, -6.35), "5": (12.70, -1.27), "6": (12.70, 1.27),
        "7": (12.70, 6.35), "8": (-12.70, -6.35),
    },
    "FH12_10S": {
        "1": (-5.08, 11.43), "2": (-5.08, 8.89), "3": (-5.08, 6.35),
        "4": (-5.08, 3.81), "5": (-5.08, 1.27), "6": (-5.08, -1.27),
        "7": (-5.08, -3.81), "8": (-5.08, -6.35), "9": (-5.08, -8.89),
        "10": (-5.08, -11.43), "11": (3.81, -16.51), "12": (3.81, 16.51),
    },
    "FTSH_107": {
        "01": (-7.62, 7.62), "02": (7.62, 7.62), "03": (-7.62, 5.08),
        "04": (7.62, 5.08), "05": (-7.62, 2.54), "06": (7.62, 2.54),
        "07": (-7.62, 0.00), "08": (7.62, 0.00), "09": (-7.62, -2.54),
        "10": (7.62, -2.54), "11": (-7.62, -5.08), "12": (7.62, -5.08),
        "13": (-7.62, -7.62), "14": (7.62, -7.62),
    },
    "X50328MSB2GI": {
        "1": (-5.08, 0.00), "2": (5.08, 0.00),
    },
    "CPT_9019A": {
        "1": (-6.35, 1.27), "2": (-6.35, -1.27),
    },
    "LS027B7DH01": {
        "1": (-10.16, 11.43), "2": (-10.16, 8.89), "3": (-10.16, 6.35),
        "4": (-10.16, 3.81), "5": (-10.16, 1.27), "6": (-10.16, -1.27),
        "7": (-10.16, -3.81), "8": (-10.16, -6.35), "9": (-10.16, -8.89),
        "10": (-10.16, -11.43),
    },
    # Inline symbols
    "R": {"1": (0.0, 3.81), "2": (0.0, -3.81)},
    "C": {"1": (0.0, 2.54), "2": (0.0, -2.54)},
    "LED": {"1": (0.0, 2.54), "2": (0.0, -2.54)},
}


def pin(sym_key, pin_num, sx, sy, sym_rot=0):
    """Calculate schematic (x, y) of a pin's wire connection point.

    sym_key:  key into PINS dict
    pin_num:  pin number/name as string
    sx, sy:   symbol placement position in schematic
    sym_rot:  symbol rotation (0, 90, 180, 270)
    """
    px, py = PINS[sym_key][pin_num]
    if sym_rot == 0:
        return (sx + px, sy - py)
    elif sym_rot == 90:
        return (sx - py, sy - px)
    elif sym_rot == 180:
        return (sx - px, sy + py)
    elif sym_rot == 270:
        return (sx + py, sy + px)
    return (sx + px, sy - py)


# ═══════════════════════════════════════════════════════════════════════════
# SYMBOL EXTRACTION
# ═══════════════════════════════════════════════════════════════════════════

def extract_symbol(lib_path: Path, symbol_name: str) -> str:
    """Extract a single symbol definition from a .kicad_sym file."""
    content = lib_path.read_text(encoding="utf-8")
    pattern = f'(symbol "{symbol_name}"'
    start = content.find(f'\t{pattern}')
    if start == -1:
        start = content.find(pattern)
    if start == -1:
        raise ValueError(f"Symbol '{symbol_name}' not found in {lib_path}")
    if start > 0 and content[start - 1] == '\t':
        start = start  # keep the tab
    depth = 0
    i = start
    while i < len(content):
        if content[i] == '(':
            depth += 1
        elif content[i] == ')':
            depth -= 1
            if depth == 0:
                return content[start:i + 1]
        i += 1
    raise ValueError(f"Unmatched parentheses for symbol '{symbol_name}'")
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

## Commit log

2026-04-23 Initial commit
    KiCad schematic migrated to sldrnrd_kicad_lib (symbols + footprints).
    Hardware spec v0.2: dual LP5907 LDO architecture, encoder and USB-C
    parts selected, RC debounce values updated.
    [InclinationMeter.kicad_pcb, InclinationMeter.kicad_sch, Netlist.csv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]
2026-04-23 Streamline markdown files
    Remove superseded PIC pin assignment, resolved missing.md, and
    STM32 pin assignment (covered by spec.md). Move KiCad reference
    docs to docs/.
2026-05-02 Schematics edited manually
    [InclinationMeter.kicad_sch, ble.kicad_sch, connectors.kicad_sch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]
2026-05-10 Schematic finalized
    [InclinationMeter.kicad_pcb, InclinationMeter.kicad_sch, connectors.kicad_sch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]
2026-05-11 Restore manual KiCad edits lost in 2026-05-10 force-push reset
    Recovers connectors/mcu/power/ui schematics and the PCB layout from the
    manual saves captured in KiCad/.history/ (timestamp 2026-05-10 19:55),
    which were wiped when the working tree was hard-reset to origin/master
    after an amended Schematic finalized force-push.
    [InclinationMeter.kicad_pcb, connectors.kicad_sch, mcu.kicad_sch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]
2026-05-14 Basic board layout changed. MCU pinout changed accordingly
    [InclinationMeter.csv, InclinationMeter.kicad_pcb, mcu.kicad_sch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]
2026-05-14 Encoder fixed, main parts and dimensions locked
    [InclinationMeter.kicad_pcb, connectors.kicad_sch, ui.kicad_sch]
2026-05-15 Board largely routed, except power and gnd
    [InclinationMeter.kicad_pcb, connectors.kicad_sch, mcu.kicad_sch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]
2026-05-22 Environmental sensor added, mostly routed.
    [InclinationMeter.kicad_pcb, connectors.kicad_sch, mcu.kicad_sch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]
2026-05-23 Routed with no errors, silkscreen done
    [InclinationMeter.kicad_pcb]
2026-05-23 External temperature sensor added
    [InclinationMeter.kicad_pcb, connectors.kicad_sch, mcu.kicad_sch]
2026-05-27 JST headers fixed, no more errors, fully routed
    [InclinationMeter.kicad_pcb, connectors.kicad_sch, power.kicad_sch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]
2026-05-31 Capacitors changed to specific symbols, board layout not yet complete
    [InclinationMeter-B_Cu.gbr, InclinationMeter-B_Mask.gbr, InclinationMeter-B_Paste.gbr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]
2026-06-12 Board layout finalized, first gerbers generated
    [BOM-InclinationMeter.csv, BOM-debug.csv, BOM-debug2.csv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]
2026-06-12 crystal capacitors changed to correct values
    [InclinationMeter.kicad_pcb, mcu.kicad_sch]
2026-06-12 Symbols and board updated to match library
    [InclinationMeter.kicad_pcb, connectors.kicad_sch, mcu.kicad_sch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]
2026-06-12 Remaining resistors and capacitors replaced by specific value components
    [BOM-InclinationMeter.csv, BOM-debug.csv, BOM-debug2.csv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]
2026-06-12 R30 fixed as well
    [InclinationMeter.kicad_pcb, connectors.kicad_sch]
2026-06-12 R4 changed to 2k
    [BOM-InclinationMeter.csv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]
